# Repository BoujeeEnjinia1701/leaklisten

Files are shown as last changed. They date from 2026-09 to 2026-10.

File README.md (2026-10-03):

# LeakListen

     

**Area:** Smart Cities · **TRL:** 3 of 9 (proof of concept on paper) · **Value-engineering target:** about $130 USD · **Difficulty:** 3 of 5

An acoustic leak sensor that clamps onto water mains and valves and listens overnight for the noise signature of leaks.

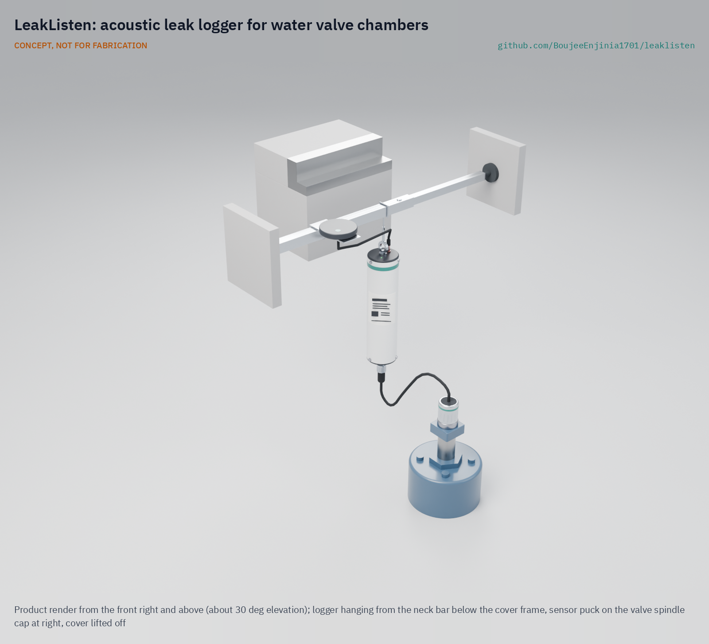
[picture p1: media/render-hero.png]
LeakListen: acoustic leak logger for water valve chambers, product render


[Exploded render](media/render-exploded.png) · [Detail render](media/render-detail.png) · [Interactive 3D model](media/viewer.html) · [Concept blueprint (PDF)](media/concept-blueprint.pdf) · [General arrangement LKL-DWG-001 (PDF)](cad/drawings/LKL-DWG-001.pdf) · [Sizing calculations](docs/04-calcs/01-sizing.md) · [Prototype build plan](docs/05-build-plan.md) · [Design decisions](docs/06-design-decisions.md) · [Review note](docs/REVIEW.md)

## Concept rationale

Leaks on pressurized mains make a steady hiss that travels along the pipe wall, and it is easiest to hear at night, when demand and traffic are low. A logger that listens to every valve in a district for a few minutes each night, and flags the ones whose quietest level has risen, turns a slow street-by-street survey into a short list of places to check. LeakListen does this with a magnet-on piezo sensor, a logger that hangs under the chamber cover, one primary cell for years of life and a single small LoRaWAN message a night.

It is open and garage-buildable because the utilities with the highest losses are often the least able to buy and maintain a fleet of closed commercial loggers. The parts are a turned aluminium puck, a piezo disc, a PVC tube, a standard LoRaWAN module and a lithium cell, for about $142 per logger, and the data format is documented so any network server, including the lab's TwinKit gateway, can read it.

## Burning platform

Water utilities lose an estimated 126 billion m³ of treated water a year to leaks and unbilled use, worth nearly $40 billion ([World Bank](https://blogs.worldbank.org/en/ppps/what-do-private-companies-look-performance-based-non-revenue-water-project)). In developing countries alone, about 45 million m³ a day leak from distribution networks, "enough to serve nearly 200 million people" ([Kingdom, Liemberger and Marin, World Bank, 2006](https://documents1.worldbank.org/curated/en/385761468330326484/pdf/394050Reducing1e0water0WSS81PUBLIC1.pdf)).

High-income networks are not immune. The United States still has about 240,000 water main breaks a year, costing about $2.6 billion in repairs ([ASCE 2025 Report Card](https://infrastructurereportcard.org/cat-item/drinking-water-infrastructure/)). Many leaks, though, never break the surface and run until someone listens for them.

## Where it could be used

### By industry

| Industry | Use |
| --- | --- |
| Municipal water utilities | Nightly screening of a district metered area, so leak crews go to flagged streets first |
| Small towns and community water schemes | A handful of loggers on the key valves of a small network without a specialist contract |
| Campuses, airports and industrial parks | Leaks on private mains after the utility meter, which the utility does not survey |
| Irrigation districts | Leaks on buried pressurized irrigation pipelines |
| Fire protection networks | Hidden leaks on private fire mains that stay pressurized but rarely flow |
| Research and education | An open logger and dataset for leak noise research and teaching |

### By country or region

| Country or region | Why it matters there |
| --- | --- |
| United States | About 240,000 water main breaks a year ([ASCE 2025](https://infrastructurereportcard.org/cat-item/drinking-water-infrastructure/)); many small utilities cannot fund commercial logger fleets. |
| England and Wales | Companies leaked an average of 2,967 million litres a day from April 2022 to March 2025, and all have leakage reduction targets ([Discover Water](https://www.discoverwater.co.uk/leaking-pipes)). |
| Southeast Asia | A study of 47 utilities in Indonesia, Malaysia, Thailand, the Philippines and Vietnam found non-revenue water averaging 30 %, ranging from 4 to 65 % ([Kingdom et al., 2006](https://documents1.worldbank.org/curated/en/385761468330326484/pdf/394050Reducing1e0water0WSS81PUBLIC1.pdf)). |
| Developing countries generally | About 45 million m³ a day lost to leakage ([Kingdom et al., 2006](https://documents1.worldbank.org/curated/en/385761468330326484/pdf/394050Reducing1e0water0WSS81PUBLIC1.pdf)); a low-cost open logger suits utilities starting a leak program. |
| South Africa | About 22 million people, 39 % of the population, were affected by intermittent water supply in 2017, and 65 of 231 municipalities supplied water intermittently ([Loubser, Chimbanga and Jacobs, 2021, *Water SA*](https://scielo.org.za/scielo.php?pid=S1816-79502021000100001&script=sci_arttext)). LeakListen only hears leaks on pressurized pipes, so it fits zones with continuous supply, and a pilot there would test that limit. |

## What sparked the idea

The starting point was the way Tokyo finds hidden leaks. Inspectors of the Tokyo Metropolitan Government Bureau of Waterworks press the tip of a listening rod against a water meter, gate valve or fire hydrant and listen for leak noise through a diaphragm, alongside night-time minimum flow measurements, electronic detectors, correlators and noise loggers; with this sustained effort the city's leakage rate fell from 10.2 % in fiscal 1992 to 3.5 % in fiscal 2024 ([Bureau of Waterworks, *Prevention of Leakage in Tokyo 2025*](https://www.english.metro.tokyo.lg.jp/documents/d/english/knowledge_and_tech_r07rousui)). Few utilities can staff that many trained listeners. LeakListen asks whether a cheap, open logger left on the same gate valves could do the first round of that listening every night, so the scarce experts go only where a valve has started to hiss.

## Problem

A large share of treated city water is lost to leaks before it reaches customers, and leaks are found by slow manual surveys. Full problem statement: [docs/01-problem.md](docs/01-problem.md).

## Concept

A magnetic piezo sensor clips onto a valve spindle cap and a sealed logger hangs under the chamber cover, placed from the surface with no chamber entry. Each night between 02:00 and 04:00 the logger records twelve 20 s windows, computes levels and a 64-band spectrum from 5 Hz to 2 kHz, deletes the raw samples and sends a 24-byte summary over LoRaWAN. A server (or the lab's TwinKit gateway) flags a logger whose night-time minimum level rises and stays up, and a crew then pinpoints the leak with standard tools.

Estimated performance at TRL 3 ([LKL-CAL-001](docs/04-calcs/01-sizing.md)): about 1.2 mAh a day and 10 years or more on one C-size lithium cell; 0.96 kg for the logger, cable and sensor against R12's 1.0 kg (met on paper), plus a 0.32 kg neck bar that stays in the chamber; about $142 in parts against a $130 value-engineering target. The reference leak (5 L/min at 3 bar) is heard about 185 m along an iron main, with a wide uncertainty. The magnet-on sensor is for metallic mains; plastic networks are served by a hydrophone variant on hydrants, not yet sized (R2). Under a cast-iron cover the radio reaches about 0.5 km, so a gateway is planned within 0.5 km of each such district (R7, at risk until cover loss is measured). Also at risk: detection on iron (R1), sensor bandwidth (R3) and noise (R4). A 42 mm magnet now holds 125 N on a coated cap (R9 met on paper). Install time and the false alarm rate need field work.

Full design precis: [docs/02-concept.md](docs/02-concept.md) · Requirements: [docs/03-requirements.md](docs/03-requirements.md) · Decisions: [DDR-001](docs/decisions/0001-trl2-review-decisions.md), [DDR-002](docs/decisions/0002-recommendations-accepted.md) · Model: [cad/src/model.py](cad/src/model.py)

## Key components

- Aluminium sensor puck with a 42 mm pot magnet (with keeper plate), a piezo disc under a 53 g brass mass and a charge preamplifier
- 2 m shielded sensor cable with an M12 IP68 plug
- IP68 PVC logger tube with turned, O-ring sealed end plugs, an eye bolt and antenna connector on top, and a printed frame inside carrying an STM32WL LoRaWAN board (FieldNode core) and a 24-bit ADC
- Lithium thionyl chloride C cell, primary, about 7.7 Ah
- Telescopic aluminium neck bar wedged across the chamber neck below the cover frame on two rubber feet; the logger hangs from it on a lanyard, and a flat LoRa antenna sits on it just under the cover

The working bill of materials is in [bom/bom.csv](bom/bom.csv).

## Building the prototype

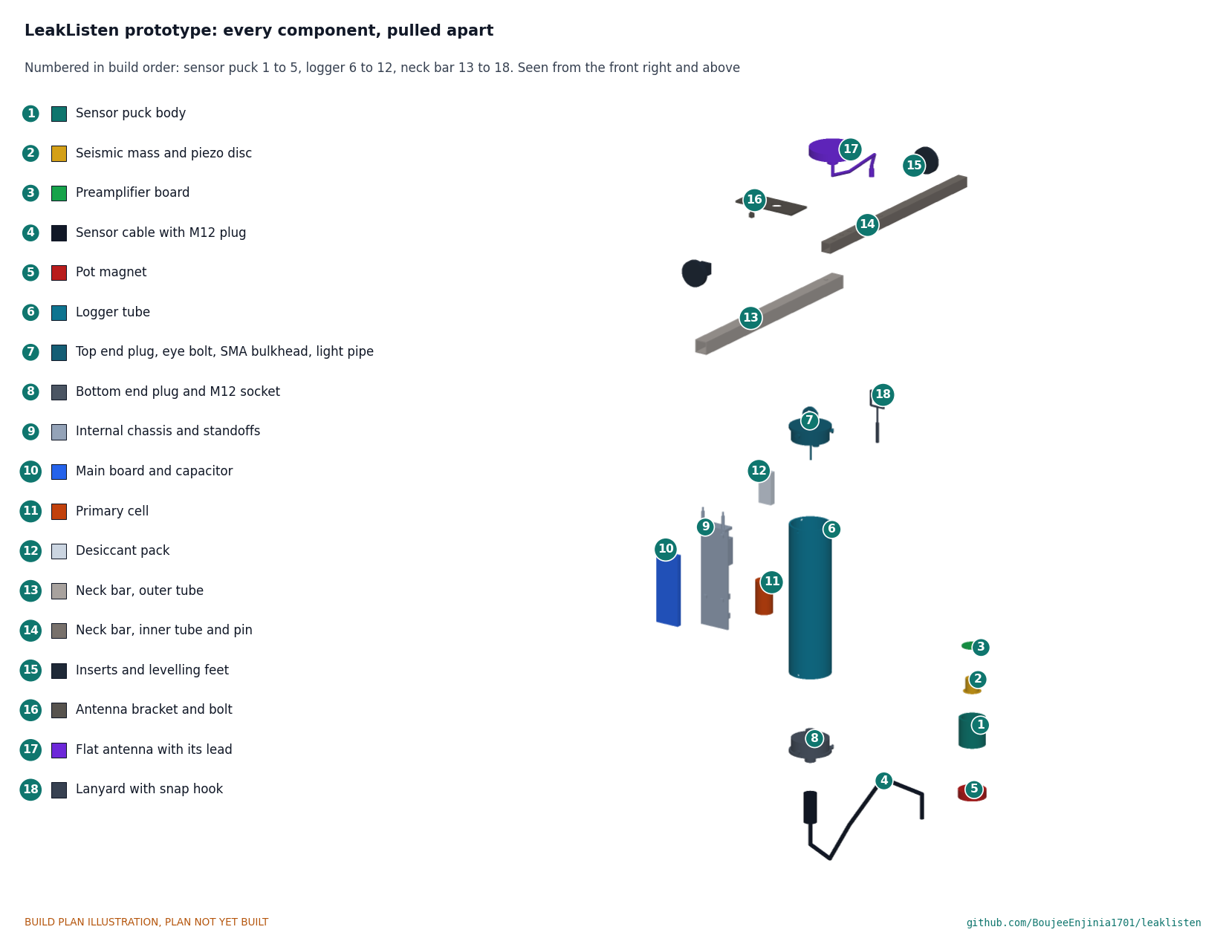
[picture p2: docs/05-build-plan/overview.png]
LeakListen prototype: every component pulled apart and numbered in build order


The [prototype build plan](docs/05-build-plan.md) (LKL-BLD-001) shows, in pictures, how to make each of the eighteen components and put them together in fifteen steps; nothing has been built yet. The made parts are a turned aluminium puck and brass weight, a cut PVC tube with two turned plastic end plugs, a printed frame for the electronics, and a telescopic aluminium neck bar with an antenna bracket. Writing the plan made the design buildable: the strap that was to hook over the cover frame became a neck bar wedged across the chamber neck below the frame, and the end plugs, the top plug fittings, the frame inside the logger and the puck base were redesigned so every part has a fixing (LKL-DDR-003, accepted by Amish on 2026-10-02). Every picture is drawn from the model, and the model checks that each part touches what it should and clears what it should not.

## Safety

> Valve chambers can be confined spaces with low oxygen or toxic gas; LeakListen is placed from the surface, and nobody should enter a chamber without a confined space permit, gas testing and a trained standby person. Covers are heavy and street work needs traffic management.
>
> The logger uses a lithium thionyl chloride primary cell: never charge it, short it, crush it or heat it, and follow the dangerous goods rules for lithium metal cells. The pot magnet can pinch fingers and affect pacemakers.
>
> Place loggers on a public water network only with the utility's written permission.

## Repository layout

| Folder | Contents |
| --- | --- |
| `docs/` | Problem, concept, requirements, calculations and design decisions |
| `cad/src/` | build123d Python source, the source of truth for all geometry |
| `cad/step/`, `cad/stl/` | Exported models for FreeCAD, other CAD tools and printing |
| `cad/drawings/` | 2D sketches and dimensioned drawings |
| `bom/` | Bill of materials |
| `electronics/` | KiCad schematics and PCB layouts |
| `firmware/` | Microcontroller code |
| `media/` | Renders, perspectives and photos |
| `build-log/` | Dated prototyping notes |

## Documentation

Controlled documents follow the portfolio [documentation standard](.kit/STANDARDS.md). Each carries a document ID (LKL-PRC-001 for the precis), a version and a revision history. Branded PDFs are built with `python .kit/render.py` and attached to GitHub Releases when a document is tagged, for example `LKL-PRC-001/v1.0`.

## Credits

Designed by Amish Chadha. See [CONTRIBUTORS.md](CONTRIBUTORS.md) for roles. To cite this design, use [CITATION.cff](CITATION.cff) (GitHub shows it as "Cite this repository").

AI assistance (Claude) was used to accelerate concept renders, prototype documentation and first-pass sizing calculations. Design direction and all decisions are Amish Chadha's, recorded in this repository's decision records (`docs/decisions/`).

## Licenses

- **Hardware** (CAD, drawings, BOM, electronics): [CERN-OHL-S v2](LICENSE)
- **Software** (firmware, scripts, notebooks): [MIT](LICENSE-SOFTWARE)

A project of the [Design Molecule](https://designmolecule.com) lab.

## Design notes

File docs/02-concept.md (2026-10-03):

---
doc_id: LKL-PRC-001
title: LeakListen design precis
project: LeakListen
doc_type: Design precis
version: "0.7"
status: Draft
date: '2026-10-02'
author: Amish Chadha
license: CERN-OHL-S-2.0
revisions:
- version: "0.1"
  date: '2026-09-25'
  author: Amish Chadha
  change: Initial scaffold
- version: "0.2"
  date: '2026-09-25'
  author: Amish Chadha
  change: TRL 2 concept, components, first-order numbers, safety and open questions
- version: "0.3"
  date: '2026-09-25'
  author: Amish Chadha
  change: TRL 3 design choices adopted for TRL 3 (LKL-DDR-001); numbers replaced by LKL-CAL-001; 53 g seismic mass, 24-byte summary, regional transmit power, weekly time correction; links to the model and LKL-DWG-001
- version: "0.4"
  date: '2026-09-25'
  author: Amish Chadha
  change: "Recommendations accepted by Amish (DDR-002): 42 mm pot magnet with keeper plate; contact sensor scoped to metallic mains, hydrophone variant for plastic; district gateway within 0.5 km under iron covers; numbers from LKL-CAL-001 v0.2; LKL-DWG-001 Rev P2"
- version: "0.5"
  date: '2026-10-01'
  author: Amish Chadha
  change: "Constructable design (LKL-DDR-003): neck bar hanger in place of the strap, flanged end plugs, eye bolt and SMA bulkhead, internal chassis, 8 mm puck base; numbers from LKL-CAL-001 v0.3; LKL-DWG-001 Rev P4; cost against the value-engineering target"
- version: "0.6"
  date: '2026-10-02'
  author: Amish Chadha
  change: "Decisions of 2026-10-02: R12 restated (met on paper), calibration check in CalRig, first candidate partner region"
- version: "0.7"
  date: '2026-10-02'
  author: Amish Chadha
  change: 'Daily charge, battery life and cost updated for the status light pipe; general arrangement Rev P5; no requirement status changed'
---

# LeakListen design precis

## Summary

LeakListen is a battery-powered acoustic leak logger that hangs under a valve chamber cover, sticks a magnetic vibration sensor onto the valve spindle cap, listens to the pipe for a few minutes each night, and sends one small LoRaWAN summary a day. A leak on a pressurized main makes a steady hiss that travels along the pipe wall; when a logger's quietest night-time level rises and stays up for several nights, the server flags that street for a follow-up survey. The TRL 3 calculations (LKL-CAL-001 v0.3) give about 1.2 mAh a day, 10 years or more on one C-size lithium cell, 1.35 kg with the neck bar hanger and about $142 in parts for the constructable design (LKL-DDR-003). They also show the two weak points, now answered by decisions Amish accepted on 2026-09-25 (LKL-DDR-002). The reference leak is heard about 185 m along an iron main but only a few metres along a plastic one, so the magnet-on sensor is scoped to metallic mains and plastic networks are left to a hydrophone variant (R2, not yet sized). The radio reaches about 0.5 km, not 1 km, from under a cast-iron cover, so a gateway is planned within 0.5 km of each such district (R7, at risk until the cover loss is measured).

Figure 1. Concept in a valve chamber, street and chamber shown in section ([media/hero.png](../media/hero.png)). Figure 2. Exploded view with BOM numbers ([media/exploded.png](../media/exploded.png)). Figure 3. Cutaway of the logger and sensor ([media/cutaway.png](../media/cutaway.png)). Figure 4. Nightly data flow ([media/flow.png](../media/flow.png)). Figure 5. General arrangement, drawing LKL-DWG-001 Rev P4 ([cad/drawings/LKL-DWG-001.pdf](../cad/drawings/LKL-DWG-001.pdf)), from the parametric model [cad/src/model.py](../cad/src/model.py).

## How it works

1. **Place from the surface.** A technician lifts the cover, lowers the sensor puck on its cable with a pole until the magnet snaps onto the valve spindle cap, and sets the neck bar, with the logger and antenna already fitted, across the chamber neck just below the cover frame, winding out one rubber foot by hand; the logger hangs from the bar on a lanyard and the flat antenna sits on the bar 20 mm under the cover. Nobody enters the chamber. (The concept hooked a strap over the frame; that is not buildable without lifting the cover off its seat, LKL-DDR-003.)
2. **Listen at night.** A real-time clock wakes the logger between 02:00 and 04:00, when demand and traffic noise are lowest. It records 12 windows of 20 s at 8 kS/s from the piezo sensor through a charge preamplifier and a 24-bit ADC. Once a week it asks the network for the time (LoRaWAN 1.0.3 DeviceTimeReq) so the clock stays within 20 s.
3. **Process on the device.** For each window the microcontroller computes the RMS level and a 64-band spectrum from 5 Hz to 2 kHz, in fixed point, with three FFT stages at 8,000, 1,000 and 250 S/s so that even the 0.49 Hz wide bottom band is resolved. It keeps the minimum and the 10th percentile level across the night (leaks are steady; traffic and water use are not) and a band spectrum. Raw samples are then deleted.
4. **Send one summary.** 24 bytes (two night levels, 16 band levels, peak band, steadiness, battery voltage, temperature, flags) go by LoRaWAN to any network server, such as the lab's TwinKit gateway, at +14 dBm in EU868 or up to +20 dBm in US915. The frame fits every EU868 rate and US915 at SF9 or faster.
5. **Flag on the server.** After a 14-night baseline, a logger whose night-time minimum rises by a set margin and stays up for 3 or more nights, with a steady narrow-band spectrum, is flagged. A crew then pinpoints with a ground microphone or a correlator.

## Main components

Numbers match the exploded view and [bom/bom.csv](../bom/bom.csv).

Table 1. Main components.

| No. | Component | Key figures | Role |
| --- | --- | --- | --- |
| 1 | Sensor puck body | Aluminium, 40 mm diameter x 42 mm, potted | Stiff, sealed carrier for the sensor and preamplifier |
| 2 | Pot magnet | 42 mm, about 600 N nominal pull on thick flat steel; keeper plate for transport (LKL-DDR-002; was 32 mm, 290 N) | Attaches to the spindle cap with no tools; 125 N on a 0.5 mm coating (R9) |
| 3 | Piezo disc and seismic mass | 27 mm brass-backed piezo disc in compression under a 20 x 20 mm brass mass, about 53 g; about 157 pC/g | Turns pipe vibration into charge |
| 4 | Charge preamplifier | Low-noise JFET-input stage, 1 nF and 53 MΩ feedback (3 Hz high-pass), then 40 dB; about 1.0 µg/√Hz | Low-noise, low-frequency front end (R3, R4) |
| 5 | Sensor cable | 2 m shielded PUR, M12 IP68 plug | Lets the puck sit on the valve while the logger stays near the cover |
| 6 | Logger housing | 63 mm PVC tube, 240 mm flange to flange, two flanged acetal end plugs with two O-rings each and three radial screws, M12 panel socket | IP68 enclosure (R11) |
| 7 | Main board | STM32WL LoRaWAN module (FieldNode core), 24-bit audio ADC, RTC, hybrid layer capacitor of 0.1 F or more | Scheduling, spectrum, radio |
| 8 | Primary cell | Li-SOCl2, C size, 3.6 V, about 7.7 Ah | Years of life without charging (R6) |
| 9 | Neck bar hanger | Telescopic 20 and 16 mm square aluminium tube with two rubber levelling feet, wedged across the chamber neck below the frame; wire rope lanyard and snap hook | Surface installation (R10) without disturbing the cover |
| 10 | Flat LoRa antenna | About 70 mm disc on a bracket on the neck bar, 20 mm under the cover; 1 m lead with an SMA plug | Radio as close to the cover as possible (R7) |
| 12 | Internal chassis | Printed PETG spine hung from the top plug, clips for the cell and capacitor, desiccant pocket | Holds the electronics; lifts out with the top plug |
| 13 | Top plug fittings | M6 eye bolt (lanyard) and IP67 SMA bulkhead (antenna); the status light pipe rod, part of line 7, shows a short blink at power-up or magnet swipe | Each sealed on its own washer or O-ring |

## Key design choices

These choices were proposed at TRL 2 and were decided by Amish on 2026-09-25: go with recommendation (LKL-DDR-001, confirmed in LKL-DDR-002). The last three follow from the TRL 3 review, also decided by Amish on 2026-09-25 (LKL-DDR-002).

- **Contact sensor on the valve, not a hydrophone.** A magnet-on sensor needs no pipe tapping and no contact with drinking water. Hydrophones hear further on plastic pipes but need a hydrant or tapping point; this is kept as an option for plastic networks (D3), and LKL-CAL-001 shows it is needed to hear any distance on PVC or PE.
- **Noise-level screening, not correlation.** Correlation needs time-synchronized raw audio from pairs of loggers and much more data over the radio. Nightly level and spectrum screening fits LoRaWAN and a primary cell (D1); correlation is recorded as a later variant.
- **Primary cell, not solar.** A chamber has no sun, and a lithium thionyl chloride cell has very low self-discharge. A hybrid layer capacitor supplies the radio pulses the cell cannot deliver alone. A C-size cell (D5) gives 10 years or more.
- **Reuse the FieldNode radio core.** The STM32WL module, payload conventions and network settings are shared with FieldNode so fixes carry across; FieldNode's solar charger and enclosure are not used (D4). Transmit power and the link budget method follow FieldNode's FND-CAL-001.
- **Compression-mode sensor with a heavy mass.** A 53 g brass mass on the disc in compression gives five times the TRL 2 sensitivity while keeping the sensor's own resonance near 200 kHz, far above the band. A disc used as a bender would be as sensitive but would resonate inside the band.
- **Privacy by design.** Raw samples never leave the logger (R8, a fixed requirement under D6). A contact sensor on a valve is a poor microphone, but the rule keeps the design acceptable for street deployment.
- **Contact sensor for metallic mains, hydrophone variant for plastic.** LKL-CAL-001 shows a contact sensor hears only a few metres along PVC or PE, so the magnet-on sensor's scope is metallic mains (R1), and R2 applies to the hydrophone variant on a hydrant or tapping point, which is not yet sized.
- **District gateway under iron covers.** The flat antenna stays under the cover. Where covers are cast iron, a gateway (TwinKit or a partner's) is planned within about 0.5 km of the district; a through-cover antenna or composite cover is used only where the utility agrees. The cover loss is to be measured before deployment (TRL 4, on hold).
- **42 mm pot magnet.** About 600 N rated, it holds 125 N on a cap with 0.5 mm of paint and rust, against 60 N for the 32 mm magnet, for $4 more. It ships with a keeper plate fitted.

## Key numbers (LKL-CAL-001)

All values come from LKL-CAL-001 and `docs/04-calcs/sizing.py`; they are first-principles estimates on assumed data.

Table 2. Key numbers.

| Quantity | Value | Requirement |
| --- | --- | --- |
| Data sampled and sent per night | 3.84 MB sampled and deleted; 24 bytes sent | R8, R14 |
| Daily charge | 1.18 mAh (EU868 SF7) to 1.25 mAh (EU868 SF12), with the status light blink | R6 |
| Battery life on energy | 10.1 to 12.5 years; taken as 10 years | R6 (5 years) |
| Airtime | 1.97 s per uplink at SF12; 5.9 s a day worst case | R14 |
| Link under an iron cover (20 dB assumed) | About 0.53 km range (EU868 SF12); +0.9 dB at the planned 0.5 km gateway distance, -1.2 dB for US915 SF9 | R7 at risk |
| Detection distance, reference leak | About 185 m on ductile iron (93 to 370 m); about 4 m on PVC with the contact sensor, out of its scope | R1 at risk; R2 open (hydrophone variant) |
| Sensor self-noise | 1.03 µg/√Hz worst from 100 Hz to 1 kHz | R4 at risk |
| Mounted resonance | About 676 to 1,350 Hz with the 42 mm magnet and 8 mm puck base | R3 at risk |
| Magnet hold on iron, 42 mm magnet | 309 N bare, 187 N at 0.3 mm, 125 N at a 0.5 mm coating | R9 met on paper |
| Clock | 20 s worst with a weekly time correction | R5 |
| Size and mass | 63 mm tube (68 mm over the screw heads), 283 mm overall; 1.35 kg with the neck bar, 0.96 kg for the logger, cable and sensor | R12 met on paper: 0.96 kg against 1.0 kg for the logger, cable and sensor (restated 2026-10-02, LKL-DDR-003 A1); the bar is site hardware |
| Parts cost | About $142 against a value-engineering target of $130 | R15: USD 12 over the target |

**Energy.** Listening, 12 mA for about 252 s a night, is 59 % of the worst day; sleep at 4 µA and the cell's own self-discharge make up most of the rest. The radio adds only 0.005 to 0.08 mAh a day at +14 dBm.

**Radio.** The flat antenna under the cover is the weak link. To close 1 km, the cover may cost no more than about 10 dB. Decided by Amish, 2026-09-25 (LKL-DDR-002): measure the cover loss first, then plan a gateway within about 0.5 km of each district with iron covers, with a through-cover antenna or composite cover where a utility agrees. At 0.5 km the EU868 link has +0.9 dB to spare at a 20 dB cover loss, and the US915 SF9 link misses by 1.2 dB.

**Cost.** Value-engineering target: USD 130. Estimated cost of the constructable design: USD 142 (USD 12 over the target), see [bom/bom.csv](../bom/bom.csv). The neck bar, the turned end plugs, the chassis and the top plug fittings added USD 28 to the concept's USD 113.

## Safety

> **Safety:** Valve chambers can be confined spaces with low oxygen or toxic gas. LeakListen is designed to be placed from the surface; nobody should enter a chamber without the utility's confined space permit, gas testing and a trained standby person. Covers can weigh 30 kg or more: use a lifting key, lift with the legs and keep feet clear. Street work needs traffic management and high-visibility clothing under local rules.
>
> The lithium thionyl chloride primary cell can vent, burn or explode if shorted, crushed, heated above its rating or charged. Fit a fuse or PTC and reverse protection, never fit a charging circuit, and store and ship cells under the dangerous goods rules for lithium metal cells.
>
> The 42 mm pot magnet pulls about twice as hard as the 32 mm one it replaces, and can pinch fingers badly and affect pacemakers and implanted devices. Carry it with its keeper plate fitted and remove the plate only at the cap.
>
> Placing anything on a public water network needs the utility's written permission. Nothing in LeakListen touches drinking water.

## Open questions

- [ ] Detection distance on iron pipes (R1): estimated in LKL-CAL-001, but the leak source strength and pipe losses need field recordings of known leaks.
- [ ] Sizing the hydrophone variant for plastic networks (R2).
- [ ] Radio loss through cast-iron, ductile iron and composite covers (R7): assumed 10 to 30 dB in LKL-CAL-001, not measured. The response is decided (district gateway within 0.5 km by default, LKL-DDR-002); the measurement is TRL 4 work and on hold.
- [ ] Sensor self-noise (R4): 1.03 µg/√Hz on assumed data; the ceramic's d33 and the op-amp noise need checking against chosen parts.
- [ ] Threshold rules for the leak flag, and how to handle pumps, pressure reducing valves and night-time customer use (R13).
- [ ] Adapter for brass, bronze and plastic fittings (the 42 mm magnet for coated caps is decided, LKL-DDR-002).
- [ ] Whether time synchronization for correlation between neighboring loggers is worth adding later.
- [x] Logger calibration check: a small shaker bay in CalRig, which today covers temperature, humidity and particles only; LeakListen defines the acceptance test (frequency range, level and pass band) in its own repo (decided by Amish, 2026-10-02).
- [x] First partner: a water utility with metallic mains, district metered areas and a leakage target it reports against; the first candidate region to approach is the UK, which would set the radio band to EU868 (decided by Amish, 2026-10-02; nothing agreed). The pilot utility is asked for its range of chamber neck sizes before any deployment.

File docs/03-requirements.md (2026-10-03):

---
doc_id: LKL-REQ-001
title: LeakListen requirements
project: LeakListen
doc_type: Requirements
version: "0.7"
status: Draft
date: '2026-10-02'
author: Amish Chadha
license: CERN-OHL-S-2.0
revisions:
- version: "0.1"
  date: '2026-09-25'
  author: Amish Chadha
  change: Initial scaffold
- version: "0.2"
  date: '2026-09-25'
  author: Amish Chadha
  change: First measurable requirements for TRL 2, with status against the concept
- version: "0.3"
  date: '2026-09-25'
  author: Amish Chadha
  change: "TRL 3, status from LKL-CAL-001 for every requirement; R8 fixed (LKL-DDR-001 D6); R5 and R14 note the weekly time correction and the 24-byte summary"
- version: "0.4"
  date: '2026-09-25'
  author: Amish Chadha
  change: "Recommendations accepted by Amish (DDR-002): R1 and R2 restated (contact sensor for metallic mains, hydrophone variant for plastic); R7 restated against a district gateway within 0.5 km under iron covers; R9 met with the 42 mm magnet; status from LKL-CAL-001 v0.2"
- version: "0.5"
  date: '2026-10-01'
  author: Amish Chadha
  change: "Constructable design (LKL-DDR-003): status from LKL-CAL-001 v0.3; R12 not met on mass with the neck bar; R15 reported against the value-engineering target; R3 and R10 figures updated"
- version: "0.6"
  date: '2026-10-02'
  author: Amish Chadha
  change: "R12 restated by Amish on 2026-10-02 (LKL-DDR-003 A1): 1.0 kg for the logger, cable and sensor, neck bar counted as site hardware; met on paper"
- version: "0.7"
  date: '2026-10-02'
  author: Amish Chadha
  change: 'R6 figure and R15 cost updated for the status light pipe (LKL-DDR-003 follow-up); no status changed'
---

# LeakListen requirements

These are first-pass requirements for one logger. Targets are proposals for review; they come from desk research, not yet from a partner utility, and must be revised after co-design (see the problem statement, LKL-PRB-001). Status is judged against the design in LKL-PRC-001 v0.5 by the calculations in LKL-CAL-001 v0.2, which print every figure quoted here. The TRL 2 review decisions are recorded in LKL-DDR-001. The TRL 3 review decisions, accepted by Amish on 2026-09-25, are recorded in LKL-DDR-002: they restate R2 (plastic mains are served by the hydrophone variant) and R7 (a gateway within 0.5 km of each district with iron covers); no numeric target is lowered.

Table 1. Requirements and status at TRL 3 (LKL-CAL-001).

| ID | Requirement | Target | Verification | Status at TRL 3 |
| --- | --- | --- | --- | --- |
| R1 | Hear a leak on metallic mains (contact sensor) | Flag a 5 L/min (1.3 US gal/min) leak at 3 bar within 100 m of the logger on cast or ductile iron DN100 to DN200. The magnet-on contact sensor's scope is metallic mains (LKL-DDR-002) | Attenuation and detection estimate (LKL-CAL-001 section G); later a partner site with a controlled leak | **At risk:** about 185 m on ductile iron at the central estimate, 93 to 370 m over plausible pipe losses |
| R2 | Hear a leak on plastic mains (hydrophone variant) | Same leak within 30 m on PVC or PE DN100 to DN200, with the hydrophone variant on a hydrant or tapping point (LKL-DDR-002, D3) | As R1, for the hydrophone variant | Open: the hydrophone variant is not sized at TRL 3. For the record, the contact sensor, now out of scope for plastic, hears about 4 m on PVC and 2 m on PE |
| R3 | Sensor bandwidth | 5 Hz to 2 kHz, within ±3 dB after correction | Resonance estimate (LKL-CAL-001 section F); later a shaker comparison | **At risk:** with the 42 mm magnet and the 8 mm puck base the mount resonates at about 676 to 1,350 Hz, flat only to 370 to 730 Hz |
| R4 | Sensor self-noise | Equivalent input noise 1 µg/√Hz or less from 100 Hz to 1 kHz | Noise calculation (LKL-CAL-001 section F) | **At risk:** 1.03 µg/√Hz worst case with the 53 g seismic mass |
| R5 | Night listening | 12 windows of 20 s between 02:00 and 04:00 local time, clock drift under 1 min per month | Clock drift estimate (LKL-CAL-001 section H) | Met on paper with a weekly network time correction (20 s worst); 87 s a month free running |
| R6 | Battery life | 5 years or more on one primary cell at the R5 schedule and one uplink a night | Power budget (LKL-CAL-001 section C) | Met on paper: 10.1 years or more on energy; taken as 10 years |
| R7 | Radio link | 90 % or more of nightly summaries delivered from a chamber with a cast-iron cover to a gateway planned within 0.5 km of each such district; 1 km where the utility agrees to a composite cover or a through-cover antenna (LKL-DDR-002) | Link budget (LKL-CAL-001 section D); cover loss measurement and field check later (TRL 4, on hold) | **At risk:** +0.9 dB at 0.5 km under a 20 dB iron cover (EU868 SF12), -1.2 dB for US915 SF9, -9.1 dB for a tight 30 dB cover; cover loss unmeasured |
| R8 | Data and privacy | Only band levels and spectra leave the logger; raw vibration samples are deleted on the device after processing. Fixed requirement (LKL-DDR-001 D6) | Design review | Met by design |
| R9 | Attachment | Magnet holds 100 N or more on a steel or iron spindle cap, with no tools or pipe work | Hold estimate (LKL-CAL-001 section I); a pull test later | Met on paper with the 42 mm magnet (LKL-DDR-002): 125 N on a 0.5 mm coating, 187 N on 0.3 mm. Non-ferrous fittings, outside this target, need an adapter |
| R10 | Install from the surface | Placed and recovered in 10 min or less without entering the chamber, for chambers up to 1.5 m deep | Task estimate (LKL-CAL-001 section K); a walk-through with the partner utility | Not verifiable at TRL 3: 11 min estimate with the neck bar assembled beforehand; cable reaches caps 2.18 m down |
| R11 | Survive the chamber | IP68: 1 m submersion for 7 days; operate from -20 to +50 °C | Design review (LKL-CAL-001 section J) | Met by design; the logger floats on its lanyard when flooded |
| R12 | Size and mass | Logger 70 mm diameter or less and 300 mm long or less; logger, cable and sensor 1.0 kg or less. The neck bar is site hardware that stays in the chamber and is not counted (restated by Amish on 2026-10-02, LKL-DDR-003 A1) | Parametric model (LKL-CAL-001 section K); weighing at TRL 4 | Met on paper: 68 x 283 mm overall; logger, cable and sensor 0.96 kg (0.04 kg margin); the neck bar is 0.32 kg |
| R13 | Leak flag quality | 1 false alarm or fewer per 20 loggers per month after a 14-night baseline | Field data from a partner network | Not verifiable at TRL 3 |
| R14 | Open and interoperable | Standard LoRaWAN 1.0.x uplink (1.0.3 for the time request), documented 24-byte payload, works with any network server and TwinKit | Design review (LKL-CAL-001 sections A and B) | Met by design |
| R15 | Cost | Parts cost per logger against a value-engineering target of USD 130 (`budget_usd`, a hypothetical control target) | Priced BOM (LKL-CAL-001 section M) | USD 142, USD 12 over the value-engineering target |

## Requirements at risk or open

Summary (LKL-CAL-001 v0.4, Table 6): none not met, 4 at risk, 1 open (R2, variant not sized), 2 not verifiable at TRL 3, 4 met on paper, 3 met by design, and R15 USD 12 over its value-engineering target. R12 was not met on mass after LKL-DDR-003 until Amish restated it on 2026-10-02 (A1); before LKL-DDR-003 R12 and R15 were met on paper; before LKL-DDR-002 there were 2 not met (R2, R7) and 4 at risk (R1, R3, R4, R9).

- **R12 thin margin on mass.** The concept's strap hanger could not be built (it had nothing to hook over except the seat under the cover), and the neck bar that replaces it (LKL-DDR-003) weighs 0.32 kg. The set is 1.35 kg; the logger, cable and sensor are 0.96 kg. Amish decided on 2026-10-02 (LKL-DDR-003, A1) to restate R12 as 1.0 kg for the logger, cable and sensor and count the bar as site hardware, so R12 is met on paper with a 0.04 kg margin; the logger set is weighed at TRL 4.

- **R7 at risk.** At an assumed 20 dB cover loss the link closes to about 0.53 km in EU868 and 0.46 km in US915. Under LKL-DDR-002 a gateway is planned within 0.5 km of each district with iron covers, which EU868 SF12 reaches with +0.9 dB to spare and US915 SF9 misses by 1.2 dB. The cover loss must be measured first; that is TRL 4 work and on hold.
- **R2 open.** Leak noise attenuates quickly on plastic pipes (0.42 dB/m at 100 Hz on PVC against 0.011 dB/m on ductile iron), and a contact sensor on a valve hears the reference leak only a few metres along PVC or PE. Under LKL-DDR-002 R2 applies to the hydrophone variant (LKL-DDR-001 D3), which is not yet sized.
- **R1 at risk.** The central estimate of 185 m on iron clears 100 m, but pipe loss and leak source strength are both uncertain by large factors.
- **R3 at risk.** The magnet mount's resonance falls inside the band and varies by site; the heavier 42 mm magnet and the 8 mm puck base lower it by about 13 %.
- **R4 at risk.** 1.03 µg/√Hz against 1 µg/√Hz, on assumed ceramic and op-amp data.
- **R9 met on paper** with the 42 mm magnet (LKL-DDR-002); it was at risk with the 32 mm magnet (90 N at a 0.3 mm coating). Brass, bronze or plastic fittings still need an adapter.
- **R10 and R13 not verifiable at TRL 3.** They need a walk-through and field data with a partner utility.

## Assumptions

- Network pressure at night 2 to 6 bar; leaks at lower pressure are quieter.
- Valve spindle caps and hydrant bodies are cast iron or steel on most networks the lab would target first.
- A LoRaWAN gateway (TwinKit, a partner's or a public network) is within about 1 km in an urban area, and within about 0.5 km of each district with cast-iron covers (LKL-DDR-002).
- Transmit power follows the regional limit: +14 dBm in EU868, up to +20 dBm in US915.
- Primary cell: lithium thionyl chloride C size, 3.6 V, about 7.7 Ah nominal, derated to 70 % usable for cold and pulse loads.

## Safety requirements

> **Safety:** S1: no confined space entry is needed to place, service or recover a logger. S2: the cell is a primary lithium cell with a fuse or PTC and reverse protection; no charging circuit is fitted. S3: the logger carries a label with the owner, a contact and a lithium cell warning. S4: nothing touches drinking water, and nothing is fixed to the pipe other than the magnet.

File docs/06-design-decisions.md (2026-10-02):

---
doc_id: LKL-DEC-001
title: LeakListen design decisions register
project: LeakListen
doc_type: Design decisions register
version: "0.2"
status: Draft
date: '2026-10-02'
author: Amish Chadha
license: CERN-OHL-S-2.0
revisions:
  - version: "0.1"
    date: '2026-10-01'
    author: Amish Chadha
    change: Register opened with the open decisions, items to confirm, value engineering and decisions made to date
  - version: "0.2"
    date: '2026-10-02'
    author: Amish Chadha
    change: "Amish approved the recommendations for all six open decisions on 2026-10-02 (LKL-DDR-003 accepted); moved to decisions made"
---

# LeakListen design decisions register

Every design decision still to be made, and every decision made, in one place. Each decision is argued in full in its decision record under `docs/decisions/`; this register is the index Amish works from. The build plan (`docs/05-build-plan.md`) describes the design as it stands and does not list open decisions.

## Open decisions

None. All open decisions were decided on 2026-10-02.

## To confirm when parts are bought

| # | What to confirm | Why it matters | Source |
| --- | --- | --- | --- |
| 1 | The pot magnet's stud is M6 and can be cut to 6 mm | The puck base is tapped M6 for 6 mm of thread | LKL-DDR-003, P7 |
| 2 | The flat antenna's centre stud size, and that its lead ends in an SMA plug | Sets the bracket's stud hole and the top plug's connector | LKL-DDR-003, P2 and P4 |
| 3 | The SMA bulkhead's panel hole and the M12 socket's thread (M16 x 1.5 assumed) | Sets the holes in the two end plugs | LKL-DDR-003, P4 and P6 |
| 4 | The square tube inserts suit 1.5 mm wall tube and take an M10 levelling foot | The feet wedge the bar | LKL-DDR-003, P1 |
| 5 | The main board fits 38 x 110 mm with its components within 8 mm | The chassis and the tube bore are sized to it | LKL-DDR-003, P5 |
| 6 | The capacitor and cell sizes (16 x 30 mm, C size 26.2 x 50 mm) | The chassis clips are printed to them; the cell clears the bore by 0.8 mm | LKL-DDR-003, P5 |

## Value engineering

Value-engineering target: USD 130 (a hypothetical control target, not a limit). Estimated cost of the constructable design: USD 141 (USD 11 over the target). Main cost drivers and savings worth trying:

- The largest lines are the main board (USD 30, a prototype price; its design is TRL 4 work), the neck bar hanger (USD 18), the logger housing with its turned plugs (USD 16), the sensor cable (USD 12) and the primary cell (USD 12).
- Making the design constructable added USD 28 to the concept's USD 113: the neck bar (USD 12 more than the strap), the turned plugs, O-rings and screws (USD 4), the internal chassis (USD 4), the eye bolt and SMA bulkhead (USD 7) and the thicker puck (USD 1).
- Savings worth trying: a fixed-length bar cut to each district's neck width, with one foot and no inner tube or pin (about USD 4 and 80 g); plugs turned in batches or moulded later; a main board price that should fall once its design is done; a cable bought by the reel with a field-fit M12 plug.

## Decisions made

| Date | Decision | Decided by | Record |
| --- | --- | --- | --- |
| 2026-09-25 | D1 to D6: nightly noise-level screening; flat antenna under the cover; piezo disc sensor with the hydrophone kept for plastic networks; reuse of the FieldNode STM32WL core; C-size cell; raw samples never leave the device | Amish: "i accept all your recommendations, go with them across all repos." | LKL-DDR-001, LKL-DDR-002 |
| 2026-09-25 | D7: measure cover loss first, then a gateway within about 0.5 km of each district with iron covers | Amish, same instruction | LKL-DDR-002 |
| 2026-09-25 | D8: the contact sensor's scope is metallic mains; the hydrophone variant answers plastic mains | Amish, same instruction | LKL-DDR-002 |
| 2026-09-25 | D9: 42 mm pot magnet with a keeper plate | Amish, same instruction | LKL-DDR-002 |
| 2026-10-01 | Budget treated as a value-engineering target, reported as over or under rather than met or not met | Amish: "the budgets are a hypothethical control target to ensure we are thinking along a value engineering lens" | This register; LKL-CAL-001 v0.3 |
| 2026-10-02 | Design for construction accepted as a whole: the changes P1 to P9 of LKL-DDR-003 (neck bar hanger, flanged end plugs, top plug fittings, internal chassis, puck changes) and their knock-on changes, as made | Amish: "i approve your recommendations for all 555 open decisions." | LKL-DDR-003, P1 to P9 |
| 2026-10-02 | R12 restated as 1.0 kg for the logger, cable and sensor (0.96 kg estimated); the 0.32 kg neck bar is site hardware that stays in the chamber; the logger set is weighed at TRL 4 because the margin is 0.04 kg | Amish: "i approve your recommendations for all 555 open decisions." | LKL-DDR-003, A1 |
| 2026-10-02 | Neck bar for the prototype; the pilot utility is asked for its range of chamber neck sizes before any deployment, and a longer inner tube is designed only if that range goes past 710 mm; a drilled bracket stays the fallback for poor or out-of-range necks | Amish: "i approve your recommendations for all 555 open decisions." | LKL-DDR-003, A2 |
| 2026-10-02 | First partner: a water utility with metallic mains, district metered areas and a leakage target it reports against. First candidate region to approach: the UK, where water companies run district metered areas and report leakage to the regulator; that would set the radio band to EU868 | Amish: "i approve your recommendations for all 555 open decisions." | LKL-DDR-002, O1 |
| 2026-10-02 | The vibration calibration check goes in CalRig as a small shaker bay; LeakListen defines the acceptance test (frequency range, level and pass band) in its own repo | Amish: "i approve your recommendations for all 555 open decisions." | LKL-DDR-002, O2 |
| 2026-10-02 | Light pipe on the top plug kept, lit only for a brief blink at power-up or magnet swipe and added to BOM line 7; board orientation, cable route and render context accepted as appearance only | Amish: "i approve your recommendations for all 555 open decisions." | `docs/REVIEW.md`, 2026-09-26 |

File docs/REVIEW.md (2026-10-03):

# Review note: LeakListen

## Session 2026-10-02: open decisions decided by Amish

Amish wrote on 2026-10-02: "i approve your recommendations for all 555 open decisions." Every open decision in this repo's register was decided as recommended and moved to "Decisions made" in `docs/06-design-decisions.md`, dated 2026-10-02.

### Decisions recorded

6 decisions recorded (register items 1 to 6). The register's "Open decisions" section now reads: "None. All open decisions were decided on 2026-10-02."

### Documents changed

- `docs/06-design-decisions.md` v0.2
- `docs/decisions/0003-design-for-construction.md` v0.2
- `docs/decisions/0001-trl2-review-decisions.md` v0.3
- `docs/decisions/0002-recommendations-accepted.md` v0.2
- `docs/03-requirements.md` v0.6
- `docs/04-calcs/01-sizing.md` v0.4
- `docs/02-concept.md` v0.6
- `docs/01-problem.md` v0.5
- `docs/05-build-plan.md` v0.2
- `README.md` (R12 figure and DDR-003 status; not a controlled document)

PDFs re-rendered with `python3 .kit/render.py`. The CAD model, BOM quantities and prices, and pictures were not changed.

### Follow-up actions to carry approved decisions into the design

1. Decision 1 (build plan pictures and renders): Update `cad/src/product_model.py` to the constructable design (neck bar, flanged plugs, eye bolt and SMA bulkhead) and regenerate `media/render-*.png`, `media/card.png` and `media/social-preview.png` on Amish's Mac; then drop the concept strap parameters that `cad/src/model.py` keeps only for the appearance model.
2. Decision 2 (calculations): Change the R12 check in `docs/04-calcs/sizing.py` to 1.0 kg for the logger, cable and sensor (neck bar excluded) and rerun, so that LKL-CAL-001 matches the hand-edited v0.4.
3. Decision 5 (documents): Write LeakListen's vibration acceptance test (frequency range, level and pass band) in this repo, and raise the small shaker bay with the CalRig project; CalRig was not edited.
4. Decision 6 (model): Add the light pipe and its hole to the top plug in `cad/src/model.py` and rerun the constructability checks.
5. Decision 6 (drawings): Regenerate the top plug making sketch and LKL-DWG-001 with the light pipe hole.
6. Decision 6 (BOM): Add the light pipe to BOM line 7 (description and price) in `bom/bom.csv` and rerun the cost line [M1].
7. Decision 6 (calculations): Add the power-up and magnet-swipe blink to the daily charge in LKL-CAL-001, section C (expected to be negligible).
8. Decision 6 (build plan pictures and renders): Show the light pipe in the top plug step pictures of LKL-BLD-001 and in the renders.

### Points found in the review

- R10 (install in 10 min or less) is shown as 'not verifiable at TRL 3' although the task estimate is now 11 min; on the register's own figures it should read 'at risk'.
- Item 2's restated limit leaves 0.04 kg of margin on the logger set (0.96 kg against 1.0 kg) on estimated masses.
- The 2026-09-26 note that the hanger plate overlapped the antenna by about 10 mm is resolved by LKL-DDR-003, P2 and can be closed in REVIEW.md.

TRL 4 remains on hold by Amish's instruction.

## Session 2026-10-01: kit 1.7.0, constructable design and prototype build plan

Kit 1.7.0 installed (`.kit/`, `.claude/commands/`, `CLAUDE.md` replaced by `.kit/CLAUDE.md`). Following `/build-plan` and STANDARDS section 18, under Amish's 2026-09-30 instruction to make the design physically buildable and his 2026-10-01 instruction to treat the budget as a value-engineering target.

### What was done

- Constructability review of `cad/src/model.py` with build123d checks; the model is now built component by component and runs 72 checks (`python cad/src/model.py --check`), all passing.
- `docs/decisions/0003-design-for-construction.md` (LKL-DDR-003 v0.1, Draft, open for Amish's review): every change below, its reason and the knock-on effects.
- `docs/05-build-plan.md` (LKL-BLD-001 v0.1) with `cad/src/build_plan_media.py`: overview, 9 making sketches (`cad/drawings/LKL-DWG-101` to `109`), 8 joint pictures, 15 step pictures and a wiring diagram in `docs/05-build-plan/`.
- `docs/06-design-decisions.md` (LKL-DEC-001 v0.1): 6 open decisions, 6 items to confirm when parts are bought, a value engineering section and the decisions made to date.
- `bom/bom.csv`: lines 1, 6 and 9 repriced, lines 12 (internal chassis) and 13 (top plug fittings) added; `bom/bom-notes.md` updated.
- Calculations re-run: LKL-CAL-001 v0.3 and `docs/04-calcs/results.csv`. LKL-REQ-001 v0.5 and LKL-PRC-001 v0.5 updated to match.
- STEP and STL regenerated (`leaklisten-assembly`, `logger`, `sensor-puck`, and new `neck-bar`); LKL-DWG-001 Rev P4 (with `cad/src/sheets.py` brought in line with the kit 1.7 sheet layout); concept media regenerated (`hero`, `exploded`, `cutaway`, `flow`, `concept-blueprint`, `model.glb`).
- `project.yaml`: `design_state: constructable`, LKL-DDR-003, LKL-BLD-001 and LKL-DEC-001 added to `trl_evidence`; `budget_usd` unchanged at 130. README: links line, value-engineering wording, key components and a "Building the prototype" section.

### Design changes made for construction (LKL-DDR-003)

1. Hanger: the stainless strap "hooked over the cover frame" (which could only sit under the cover and rock it) became a telescopic aluminium neck bar wedged across the chamber neck below the frame on two rubber levelling feet; the logger hangs from it on a wire rope lanyard.
2. Antenna: on a 40 x 3 mm bracket bolted across the bar, held by its own stud; 20 mm under the cover (was 8 mm), and no longer overlapping the hanger (the overlap flagged in this note on 2026-09-26 is resolved).
3. End plugs: flanged acetal plugs with two O-rings each, held by three radial M4 screws outboard of the O-rings; tube cut to 232 mm so the logger stays 240 mm flange to flange.
4. Top plug: an M6 eye bolt for the lanyard and an IP67 SMA bulkhead for the antenna, in place of one "antenna and lanyard gland".
5. Inside the logger: a printed chassis hung from the top plug on two standoffs, with the board on standoffs, clips for the cell and capacitor and a desiccant pocket.
6. Bottom plug: a front-mount M12 panel socket in an M16 thread.
7. Puck base thickened from 3 to 8 mm and tapped M6 for the magnet's stud.
8. Puck bore stepped so a round 31 mm preamplifier board sits on the step clear of the seismic mass, with potting above the board only.
9. Logger lowered to 180 mm below the street to hang under the bar; the cable still reaches caps 2.18 m deep.

### Key results

- Mass 1.35 kg with the neck bar (logger, cable and sensor 0.96 kg): **R12 not met** on mass (1.0 kg). Size 68 x 283 mm still meets R12's 70 x 300 mm.
- Value-engineering target: USD 130. Estimated cost of the constructable design: USD 141 (USD 11 over the target).
- R3 slightly worse: mounted resonance 676 to 1,352 Hz (was 695 to 1,389 Hz). Install task estimate 11 min (R10, not verifiable at TRL 3). Logger still floats on its lanyard when flooded (1.9 N).
- Requirement status: 1 not met (R12), 4 at risk (R1, R3, R4, R7), 1 open (R2), 2 not verifiable (R10, R13), 3 met on paper (R5, R6, R9), 3 met by design (R8, R11, R14), R15 USD 11 over its value-engineering target.

### Proposed, awaiting Amish

All in the design decisions register (LKL-DEC-001): accept LKL-DDR-003 as a whole; A1, restate R12's mass limit for the logger, cable and sensor (recommended); A2, neck bar versus a drilled wall bracket for other neck sizes (neck bar recommended for the prototype); O1 and O2 carried from LKL-DDR-002; the 2026-09-26 appearance-model items.

### Safety

No change to the safety case. The neck bar removes a hazard the concept had (a strap under the cover seat would rock the cover under traffic). The build plan carries stop points for the lithium thionyl chloride cell and the magnet, and keeps all work at the bench or the surface.

### Stale, to redo on Amish's Mac

The photoreal renders (`media/render-*.png`, referenced by the README but not present in this copy), `media/card.png`, `media/social-preview.png` and the appearance model `cad/src/product_model.py` still show the concept strap hanger, the fused end plugs and the single top gland. The design changed visibly, so they are stale. `cad/src/model.py` keeps the concept strap parameters only so `product_model.py` still runs.

### Recommended next step

Amish reviews LKL-DDR-003 and the register. TRL 4 (building and testing to the plan) remains on hold.

## Session 2026-09-26: sources strengthened

Amish asked on 2026-09-26 to fix the weaker sources. README change only; no controlled document changed. All other README sources (World Bank, Kingdom et al. 2006, ASCE 2025, Discover Water, Tokyo Bureau of Waterworks) were re-checked and support their claims.

| Where | Old source | New source |
| --- | --- | --- |
| Country row: Sub-Saharan Africa | None | Replaced by South Africa, citing [Loubser, Chimbanga and Jacobs, 2021, *Water SA*](https://scielo.org.za/scielo.php?pid=S1816-79502021000100001&script=sci_arttext) (22 million people, 39 % of the population, on intermittent supply in 2017) |

## Session 2026-09-25: /populate to a strong TRL 2

### What was done

- `docs/01-problem.md` (LKL-PRB-001 v0.2): problem with cited loss figures, users, operating context, constraints, out of scope, prior work (Hunaidi and Chu 1999, Gutermann ZONESCAN, World Bank NRW work), open questions and safety; co-design checklist kept.
- `docs/03-requirements.md` (LKL-REQ-001 v0.2): 15 measurable requirements (R1 to R15) with targets, verification method and status at TRL 2; safety requirements S1 to S4; assumptions.
- `docs/02-concept.md` (LKL-PRC-001 v0.2): how it works, 10 numbered components, design choices, data and energy budgets, battery life, magnet hold, cost, safety and open questions.
- `cad/src/concept_media.py`: massing model of the logger on a gate valve in a DN150 main's valve chamber, with the street, soil and chamber shown in section and a 1.75 m person standing on the street. Existing assets (main, valve, spindle cap) are grey and unnumbered.
- `media/`: `hero.png`, `concept-blueprint.png`, `.pdf` and `.svg`, `exploded.png` (BOM callouts 1 to 10), `cutaway.png` (logger and sensor puck interiors), `flow.png` (nightly data flow, estimates), `model.glb` and `viewer.html`.
- `bom/bom.csv`: 11 lines with indicative USD prices, numbered to match the exploded view; `bom/bom-notes.md` updated.
- `README.md`: hero image and links line; concept rationale, burning platform, where it could be used, what sparked the idea, concept, key components and safety expanded.
- `docs/pdf/`: branded PDFs of the three controlled documents.

Media notes: the kit's cutaway cutter is centered on Z = 0, so `concept_media.py` lifts the model 400 mm for the kit media; the hero is rendered separately in true street coordinates with a plain-language note. The main and valve appear only in the hero so the exploded view and cutaway frame the logger at a readable size.

### Key results (estimates, to be checked at TRL 3)

| Quantity | Estimate | Requirement |
| --- | --- | --- |
| Data sampled per night | 3.84 MB (240 s at 8 kS/s, 16 bit), deleted on device | R8 met by design |
| Data sent per night | about 50 bytes, one LoRaWAN uplink plus retries | R14 |
| Energy per day | about 1.15 mAh, self-discharge included | |
| Battery life, C-size Li-SOCl2 7.7 Ah at 70 % usable | about 12.8 years on energy, taken as about 10 years | R6 met on paper (5 years) |
| Magnet hold on a painted spindle cap | about 95 N (a third of the 290 N rating) | R9 marginal (100 N) |
| Logger size and mass | 63 x 240 mm; about 0.7 kg | R12 met |
| Parts cost | about $108 | R15 met ($130) |

Requirements not met or at risk:

- **R2 (plastic pipes) at risk:** plastic pipes attenuate leak noise strongly, so 30 m detection may not be reachable.
- **R7 (radio from under a cast-iron cover) at risk:** cover loss is unknown and may block the link.
- **R9 (attachment) not met** for brass, bronze or plastic fittings, and marginal on painted iron caps.
- **R1, R4 and R13 unverified:** detection distance on iron pipes, sensor self-noise and false alarm rate need calculation at TRL 3 and field data later.

### Proposed, awaiting Amish

1. **Screening versus correlation (pitch-level).** Option A: nightly noise-level screening only (this concept; fits LoRaWAN and a primary cell). Option B: add time-synchronized raw audio for correlation between neighboring loggers (pinpoints leaks, but needs GNSS or radio time sync, much more data and a larger battery). Recommendation: A for TRL 3, with B recorded as a later variant. **Decided by Amish, 2026-09-25: go with recommendation** (LKL-DDR-001, LKL-DDR-002).
2. **Radio from under covers.** Option A: flat antenna under the cover (this concept). Option B: through-cover antenna in a drilled or composite cover (needs utility consent). Option C: a nearby gateway per district. Recommendation: A, with a link budget at TRL 3 deciding whether B is needed. **Decided by Amish, 2026-09-25: go with recommendation** (LKL-DDR-001, LKL-DDR-002).
3. **Sensor type.** Piezo disc with a charge amplifier (cheap, this concept) versus a MEMS accelerometer (simpler, likely noisier at low levels) versus a hydrophone on hydrants (hears further on plastic, needs a tapping). Recommendation: piezo disc, with the hydrophone kept as an option for plastic networks. **Decided by Amish, 2026-09-25: go with recommendation** (LKL-DDR-001, LKL-DDR-002).
4. **Reuse of the FieldNode radio core** (STM32WL module and payload conventions, without FieldNode's solar power). Recommendation: yes, to share fixes across the lab. **Decided by Amish, 2026-09-25: go with recommendation** (LKL-DDR-001, LKL-DDR-002).
5. **Primary cell size.** C size about 7.7 Ah (this concept, about 10 years) versus D size about 19 Ah (longer margin, larger tube). Recommendation: C size. **Decided by Amish, 2026-09-25: go with recommendation** (LKL-DDR-001, LKL-DDR-002).
6. **Privacy rule.** Raw samples never leave the device (R8). Recommendation: keep as a fixed requirement. **Decided by Amish, 2026-09-25: go with recommendation** (LKL-DDR-001, LKL-DDR-002).
7. **First partner utility and region** for co-design and a pilot district. No recommendation; still Proposed, awaiting Amish.
8. **Whether a vibration calibration check belongs here or in CalRig** (CalRig today covers temperature, humidity and particles only). No recommendation; still Proposed, awaiting Amish.

No change to `project.yaml`: the pitch and problem still match the numbers found, and the budget holds.

### Safety concerns

- Valve chambers are confined spaces; the design avoids entry, but a failed placement may tempt someone to climb in. Instructions must say never enter without a permit, gas test and standby person.
- Heavy covers and street work: manual handling and traffic.
- Lithium thionyl chloride primary cell: fire or explosion if shorted, crushed, heated or charged; dangerous goods rules apply to shipping.
- Strong pot magnet: pinching and implanted medical devices.
- Work on a public water network without utility permission.

### Recommended next step

Review this note and the media, then decide items 1 and 2. If approved, run `/advance-trl3` to estimate leak noise attenuation and detection distance for iron and plastic pipes, the sensor noise budget, the radio link budget through covers, and the magnet hold, and to produce the parametric model and drawing sheet.

## Session 2026-09-25: TRL 3

On 2026-09-25 Amish asked for this batch of repos to be taken through the usual process with the instruction "you know the drill, nothing gets past TRL 3". He has not reviewed this repo's TRL 2 items one by one, so every item that carried a recommendation is adopted as recommended for TRL 3 under Amish's 2026-09-25 instruction, open for his review. This session ran `/advance-trl3` on that basis and stopped at TRL 3.

### What was done

- `docs/decisions/0001-trl2-review-decisions.md` (LKL-DDR-001 v0.1, status proposed): six items adopted as recommended for TRL 3, open for Amish's review (D1 to D6), and two left open (O1, O2).
- `docs/04-calcs/01-sizing.md` (LKL-CAL-001 v0.1) and `docs/04-calcs/sizing.py`: data and processing, airtime, energy and battery life, link budget through the cover, leak noise attenuation, sensor noise and resonances, detection distance, clock, magnet hold, chamber survival, size and mass, installation, false alarms and cost, with a status for every requirement. The script imports the model, reads the BOM and `project.yaml`, prints every number the note quotes and writes `docs/04-calcs/results.csv`.
- `cad/src/model.py`: parametric build123d model of the installed set (sensor puck, magnet, piezo and mass, preamplifier, cable with M12 plug, logger tube with plugs, board and capacitor, cell, desiccant, hanger and lanyard, flat antenna), with the spindle cap and cover frame as grey context. Exports `cad/step/` and `cad/stl/` for `leaklisten-assembly`, `logger` and `sensor-puck`.
- `cad/src/sheets.py` and `cad/drawings/LKL-DWG-001.svg`, `.pdf`, `.png`: general arrangement at Rev P1, 1:5, marked "CONCEPT, NOT FOR FABRICATION" and "PRELIMINARY, NOT FOR FABRICATION". LKL-DWG-001 was free because the concept blueprint is LKL-DWG-010.
- `bom/bom.csv` (11 lines, all priced with a supplier or supplier type, $109.00 against the $130 budget) and `bom/bom-notes.md`.
- `cad/src/concept_media.py` now takes the LeakListen parts from the model; all of `media/` was re-rendered and every image checked; temporary `_views` folders deleted.
- LKL-PRB-001, LKL-PRC-001 and LKL-REQ-001 revised to v0.3; `README.md` (TRL badge and line, links, concept figures) and `project.yaml` (`trl: 3`, `trl_target: 3`, evidence list) updated. PDFs rebuilt in `docs/pdf/`.

Design changes made by the calculations, within the adopted decisions: the seismic mass grows from about 11 g to about 53 g in compression and the puck from 34 to 42 mm tall (R4); the nightly summary shrinks from about 50 to 24 bytes so it fits US915 (R14); transmit power is +14 dBm in EU868, since the TRL 2 figure of +20 dBm is not permitted there; the clock takes a weekly LoRaWAN time correction (R5).

### Requirement status (LKL-CAL-001, Table 6)

2 not met, 4 at risk, 2 not verifiable at TRL 3, 4 met on paper, 3 met by design.

| ID | Status | Key number |
| --- | --- | --- |
| R2 Plastic mains | **Not met** | About 4 m on PVC and 2 m on PE for the reference leak, against 30 m |
| R7 Radio link | **Not met** | -9.7 dB at 1 km under an iron cover at an assumed 20 dB loss (EU868 SF12); range about 0.53 km |
| R1 Metallic mains | At risk | About 185 m on ductile iron; 93 to 370 m over plausible pipe losses |
| R3 Bandwidth | At risk | Magnet mount resonance about 780 to 1,550 Hz, flat only to 420 to 840 Hz |
| R4 Self-noise | At risk | 1.03 µg/√Hz against 1 µg/√Hz |
| R9 Attachment | At risk | 149 N bare, 90 N at a 0.3 mm coating, 60 N at 0.5 mm; non-ferrous fittings still need an adapter |
| R10 Install, R13 False alarms | Not verifiable at TRL 3 | 10 min task estimate; random scatter negligible, site events unknown |
| R5, R6, R12, R15 | Met on paper | 20 s clock error with weekly sync; 10.3 years or more; 63 x 267 mm, 0.93 kg; $109.00 |
| R8, R11, R14 | Met by design | |

Key numbers: 1.15 to 1.22 mAh a day; 1.97 s per uplink at SF12; 157 pC/g sensor; leak noise loss 0.011 dB/m (iron) and 0.42 dB/m (PVC) at 100 Hz.

### Decisions recorded (LKL-DDR-001)

Adopted as recommended for TRL 3 under Amish's 2026-09-25 instruction, open for his review (since **Decided by Amish, 2026-09-25: go with recommendation**, LKL-DDR-002): D1 nightly noise-level screening, correlation as a later variant; D2 flat antenna under the cover, with the link budget deciding whether more is needed (it is, see item 3 below); D3 piezo disc sensor, hydrophone kept as an option for plastic networks; D4 reuse of the FieldNode STM32WL core and payload conventions without its solar power; D5 C-size cell; D6 raw samples never leave the device, R8 fixed. No new budget, pitch or problem wording was recommended, so `budget_usd` stays at $130 and `project.yaml` and `README.md` keep the existing pitch and problem lines.

### Still awaiting Amish

1. **O1, first partner utility and region** for co-design and a pilot district. No preference stated.
2. **O2, vibration calibration check here or in CalRig.** No recommendation was made. CalRig's TRL 3 scope is still temperature, humidity and particles.
3. **New, radio under iron covers (R7).** Options: (a) a through-cover antenna or composite cover, which needs utility consent; (b) plan a gateway within about 0.5 km of each district (TwinKit or partner); (c) relax R7 to 0.5 km under iron covers. Recommendation: measure cover loss first; then (b) as the default because it touches no utility asset, with (a) where a utility agrees. **Decided by Amish, 2026-09-25: go with recommendation** (LKL-DDR-002 D7); the measurement is TRL 4 and on hold.
4. **New, plastic mains (R2).** Options: (a) restate the contact sensor's scope as metallic mains and make the hydrophone variant (D3) the answer for plastic networks; (b) keep R2 for the contact sensor and accept it is not met; (c) relax R2. Recommendation: (a). **Decided by Amish, 2026-09-25: go with recommendation** (LKL-DDR-002 D8); the pitch still holds, since hydrophones also mount on existing fittings.
5. **New, 42 mm pot magnet (R9).** About +$4 ($113.00, under budget); holds 125 N at a 0.5 mm coating. Recommendation: yes, with a keeper plate as for the 32 mm magnet. **Decided by Amish, 2026-09-25: go with recommendation** (LKL-DDR-002 D9).

Suggestions only, not in the repo: request the full 64-band spectrum from a flagged logger by downlink; a pointed hardened contact stud under the magnet to stiffen the mount (R3).

### Cross-repo consistency

- FieldNode (FND REVIEW, TRL 3): STM32WL-class module, +14 dBm SX1262-class radio at 45 mA, 20-byte payload, TwinKit first. LeakListen now uses the same EU868 power, noise figure, SNR limits and antenna and feeder figures; its path model is urban Hata rather than FieldNode's suburban one, because loggers sit at street level in towns. The 24-byte summary is LeakListen's own payload on FieldNode's conventions. No conflict; FieldNode not edited.
- TwinKit (TWK REVIEW, TRL 3): 8-channel LoRaWAN concentrator; gateway sensitivity assumed equal to the node's, as here. Recommendation 3(b) would add gateways at about 0.5 km spacing in districts with iron covers, which is denser than TwinKit's sizing assumes. Noted here; TwinKit not edited.
- CalRig: no vibration scope (O2 stays open). No other repo was edited.

### Safety concerns

- Confined spaces: the design still needs no chamber entry. A failed placement may tempt someone to climb in; instructions must say never enter without a permit, gas test and standby person.
- Heavy covers and street work: manual handling and traffic management, as at TRL 2.
- Lithium thionyl chloride cell: fuse or PTC, reverse protection and no charging circuit; dangerous goods rules for shipping. The hybrid layer capacitor must be fused with the cell.
- Magnets: the proposed 42 mm magnet roughly doubles the pull, and the pinch hazard with it; keeper plate fitted in transport, and the pacemaker warning on the label.
- A flooded chamber lifts the logger against its lanyard (2.8 N); the lanyard must not rely on the antenna lead.
- Utility permission before placing anything on a public network.

### Gaps and notes

- Citations: the TRL 2 note listed no unchecked citations. The new citation in LKL-CAL-001 and LKL-PRB-001 (Gao et al., 2004) was verified with WebFetch on its publisher page. WebSearch was not used (quota exhausted).
- Assumptions only tests can settle: cover loss (10 to 30 dB), leak acoustic efficiency (1e-6 to 1e-4), pipe loss factors, valve coupling (-10 dB), night background, magnet mount stiffness and the gap law for the magnet. No figure was invented to replace them.
- The kit's cutaway cuts at the mean Y of the parts; as at TRL 2, `concept_media.py` lifts the logger parts 400 mm for the kit media and renders the hero separately in street coordinates. The cutaway shows the cell, capacitor and puck interior; the main board sits in the removed half and shows in the exploded view.
- Existing material beyond TRL 3: `build-log/README.md` (scaffold) is present, untouched and not extended. `firmware/` and `electronics/` are empty. No test, build or firmware material exists.

### Recommended next step

TRL 4 is on hold by Amish's instruction; this repo stops at TRL 3. Amish's review is needed on D1 to D6, O1 and O2, and items 3 to 5 above. For the record only, TRL 4 would need: a bench build of the sensor puck and logger; a lab test report (TST, `environment: lab`) covering sensor sensitivity and self-noise against a reference accelerometer on a shaker, magnet pull on coated iron caps, mounted resonance, LoRa loss through iron and composite covers, sleep and listening current, and a submersion check; and build log entries. None of this has been started.

## Session 2026-09-25: recommendations accepted

On 2026-09-25 Amish wrote: "i accept all your recommendations, go with them across all repos." Every item with a recommendation is now "Decided by Amish, 2026-09-25: go with recommendation", recorded in `docs/decisions/0002-recommendations-accepted.md` (LKL-DDR-002 v0.1). Items without a recommendation stay open. The repo stays at TRL 3.

### Decisions applied and what changed

- **D1 to D6** (LKL-DDR-001): screening, flat antenna, piezo sensor, FieldNode core, C cell, privacy rule. Already built into the TRL 3 design; LKL-DDR-001 raised to v0.2 with the new status wording.
- **D7, radio under iron covers (R7).** Measure cover loss first (TRL 4, on hold), then plan a gateway within about 0.5 km of each district with iron covers, with a through-cover antenna or composite cover where a utility agrees. R7 restated from "gateway within 1 km" to "gateway within 0.5 km under iron covers, 1 km where a composite cover or through-cover antenna is agreed". New LKL-CAL-001 line [D5]: margin at 0.5 km under a 20 dB cover +0.9 dB (EU868 SF12) and -1.2 dB (US915 SF9); -9.1 dB under a tight 30 dB cover. R7: not met (-9.7 dB at 1 km) to at risk.
- **D8, plastic mains (R2).** The contact sensor's scope is metallic mains (R1); R2 applies to the hydrophone variant, which is not yet sized. R2: not met (4 m on PVC) to open.
- **D9, 42 mm magnet (R9).** `cad/src/model.py` magnet 32 to 42 mm (rated 290 to 600 N, new parameter `magnet_rated_n`); STEP and STL re-exported; BOM line 2 $5 to $9, total $109.00 to $113.00 (budget $130 unchanged, margin $21.00 to $17.00); hold at a 0.5 mm coating 60 to 125 N, at 0.3 mm 90 to 187 N. R9: at risk to met on paper. Side effects: puck and magnet 210 to 262 g, mounted resonance 776 to 1,553 Hz becomes 695 to 1,389 Hz (flat to 376 to 752 Hz, R3 still at risk and slightly worse); total mass 0.93 to 0.98 kg (R12 met with 20 g to spare).
- Documents: LKL-PRB-001 v0.4, LKL-PRC-001 v0.4, LKL-REQ-001 v0.4, LKL-CAL-001 v0.2 (script re-run, `results.csv` rewritten), LKL-DDR-001 v0.2, new LKL-DDR-002 v0.1; LKL-DWG-001 Rev P1 to P2 (magnet); `media/` re-rendered (magnet label, key figures) and checked; `bom/bom-notes.md` updated; `project.yaml` evidence list adds LKL-DDR-002. No budget, pitch or problem change was recommended, so `budget_usd`, `pitch` and `problem` are unchanged.
- README: "What sparked the idea" rewritten around Tokyo's listening-rod leak surveys on gate valves (leakage 10.2 % in fiscal 1992 to 3.5 % in fiscal 2024, Tokyo Bureau of Waterworks); cost, mass and requirement text updated. All PDFs and drawings regenerated so the footer reads designmolecule.com.

### Requirement status (LKL-CAL-001 v0.2)

None not met (was 2), 4 at risk, 1 open, 2 not verifiable at TRL 3, 5 met on paper, 3 met by design.

| ID | Status | Key number |
| --- | --- | --- |
| R1 Metallic mains | At risk | About 185 m on ductile iron; 93 to 370 m over plausible pipe losses |
| R3 Bandwidth | At risk | Mount resonance 695 to 1,389 Hz, flat only to 376 to 752 Hz |
| R4 Self-noise | At risk | 1.03 µg/√Hz against 1 µg/√Hz |
| R7 Radio link | At risk | +0.9 dB at 0.5 km (EU868 SF12), -1.2 dB (US915 SF9); cover loss unmeasured |
| R2 Plastic mains | Open | Hydrophone variant not sized |
| R10, R13 | Not verifiable at TRL 3 | Field work needed |
| R5, R6, R9, R12, R15 | Met on paper | 20 s clock; 10.3 years; 125 N at 0.5 mm; 0.98 kg; $113.00 |
| R8, R11, R14 | Met by design | |

### Still awaiting Amish

1. **O1, first partner utility and region** for co-design and a pilot district. No recommendation.
2. **O2, vibration calibration check here or in CalRig.** No recommendation.

The two suggestions in the TRL 3 section (full spectrum by downlink; a hardened contact stud) were suggestions, not recommendations, and remain outside the repo.

### Cross-repo actions

- **TwinKit:** D7 plans a gateway within about 0.5 km of each district with cast-iron covers, denser than TwinKit's current sizing assumes. Raise with TwinKit; TwinKit not edited.
- **FieldNode:** no action; D4 (shared STM32WL core and payload conventions) is consistent with FieldNode's TRL 3 figures.
- **CalRig:** depends on O2, which is still open; no action yet.

### Safety

Unchanged, plus: the 42 mm magnet pulls about twice as hard as the 32 mm one, so the pinch hazard rises; it ships with its keeper plate fitted and the pacemaker warning stays on the label.

### TRL 4

TRL 4 remains on hold by Amish's instruction. Decided but on hold: measuring LoRa loss through cast-iron and composite covers (D7) and any field link check. No build, test, purchasing, PCB or firmware work was done.

## Session 2026-09-26: product appearance model and photoreal renders

Amish chose LeakListen for the first batch of product renders on 2026-09-26.

### What was done

- `cad/src/product_model.py` (new): appearance model for photoreal renders only, with `product_parts()`, `TITLE` and three `RENDER_VIEWS` (hero with compact chamber context, exploded, and a detail view without context). It adds:
  - logger tube with filleted end plugs, a parting groove and O-ring line on each plug, a teal name band, the owner and lithium warning label with print, the antenna gland and a ribbed M12 panel socket;
  - main board with its module shield can and components facing the front, the hybrid layer capacitor, the C cell with terminals and label band, and the desiccant pack (fabric);
  - flat antenna radome with filleted edges, a seam line and a teal mark, and its lead;
  - stainless hanger strap with a rounded bend, rivets and a lanyard eye, and the stainless lanyard;
  - sensor cable on a smoothed route with a molded M12 plug and knurled coupling nut;
  - bead-blasted aluminium sensor puck with grip flutes, a lid seam, a teal ring and a cable gland, on the 42 mm pot magnet; piezo disc, ceramic, 53 g brass mass and preamplifier inside;
  - context (not in the BOM): the square spindle cap, spindle and gate valve bonnet top (bonnet top at Z = -570 mm, as `cad/src/concept_media.py`), and a slice of cover frame, roof slab and street. The chamber cover is left off so the antenna shows, and the main is not drawn, to keep the render compact.
- `README.md`: the hero image now points to `media/render-hero.png`, with a link to `media/render-exploded.png`. The render files are produced separately.
- Every main dimension, position and interface comes from `PARAMS`, `derived()` and `site_context()` in `cad/src/model.py`. `model.py`, the BOM, the calculation note and the drawing are unchanged.

### Differences between the appearance model and model.py

1. **Status light pipe on the top plug.** A small green light pipe (shown lit) is not in model.py or the BOM. It would let the technician confirm the logger is awake before closing the cover, at a small energy cost. Proposed, awaiting Amish. Recommendation: keep it as a brief blink on the magnet-swipe or power-up only, and add it to BOM line 7 if accepted; otherwise delete the part from `product_model.py`.
2. **Main board orientation.** The board sits at the back of model.py's 8 mm board envelope with its components facing the front (-Y), so they show in the exploded view. The envelope is unchanged. Proposed, awaiting Amish. Recommendation: accept; no change to model.py is needed.
3. **Sensor cable route.** The direct run in model.py is drawn with softened bends through the same points, and the cable leaves the puck through a gland on the lid. The 2 m cable length and both end interfaces are unchanged. Proposed, awaiting Amish. Recommendation: accept as appearance only.
4. **Context extent.** The cover frame slice is 220 mm deep (model.py's `site_context()` frame is 120 mm), and a roof slab, street slice and valve bonnet top are added for the render. These are existing assets, not LeakListen parts. Proposed, awaiting Amish. Recommendation: accept as render context only.

Noted, not changed: in model.py the hanger plate overlaps the antenna disc by about 10 mm in X, and the lanyard starts inside the antenna. The appearance model keeps these positions. Proposed, awaiting Amish: shorten the plate or move the antenna about 10 mm toward +X in model.py at the next design revision.

### TRL

Appearance only: no tolerances, no fabrication detail, no PCB layout and no TRL 4 work. `trl: 3` is unchanged, and TRL 4 remains on hold.

## Session 2026-09-27: kit 1.5.0 and image quality

- Kit 1.5.0 synced: STANDARDS v1.5 (sections 12 to 15: product renders, storefront images and image quality, public release, authorship and signing), `.kit/cards.py`, `.kit/image_qc.py`, `.kit/release_gate.py`, issue templates, and the `/render-product` and `/release` commands. `CLAUDE.md` now matches `.kit/CLAUDE.md`.
- Every `media/render-*.png` recaptioned from its original render with the new layout: the title, concept label and repository sit in a band above the render and the view note in a band below it, each line wrapped to the image width, so no text overlaps other text or the render or runs off the image. `media/card.png` and `media/social-preview.png` regenerated with the same rules.
- `python .kit/image_qc.py` and `python .kit/release_gate.py` pass. trl stays 3.

## Session 2026-10-02: approved follow-ups carried out

Amish approved on 2026-10-02 that every follow-up action from the open-decision sign-off be carried out. trl stays 3; no build or test work was done. `budget_usd` is unchanged.

### Follow-ups

1. Done (pictures, appearance model): `cad/src/product_model.py` rebuilt on the constructable design: neck bar with feet, pin and bracket, lanyard, flanged plugs with O-rings and radial screws, eye bolt, SMA bulkhead, light pipe, chassis on standoffs, round preamplifier board on its step, and the model.py cable route. The concept strap parameters and the concept board size are dropped from `cad/src/model.py`. The photoreal renders, `media/card.png` and `media/social-preview.png` are made on Amish's Mac next from the exported scenes.
2. Done (calculations): the R12 check in `sizing.py` counts the logger, cable and sensor against 1.0 kg: 0.96 kg (margin 38 g). The 70 g antenna rides on the neck bar and is counted with the bar, as in the 0.96 kg of the register. With the bar and antenna the set is 1.35 kg.
3. Not done: LeakListen's vibration acceptance test (frequency range, level and pass band) is a test plan, which is TRL 4 work under the portfolio cap; raising the shaker bay with CalRig is Amish's to start. See Cross-repo actions.
4. Done (model): a 3 mm light pipe rod through a 3 mm hole in the top plug, 13 mm from the axis toward the board side and 10 mm along the standoff line, ending 1.5 mm above the board's top edge. All 75 constructability checks pass (3 new). STEP and STL regenerated.
5. Done (drawings): top plug making sketch LKL-DWG-104 (Rev P2) and general arrangement LKL-DWG-001 (Rev P5) show the light pipe hole and rod.
6. Done (BOM): line 7 includes the light pipe, USD 30.00 to USD 31.00 (basis in `bom/bom-notes.md`).
7. Done (calculations): the status light blink is in the daily charge (section C, [C4]): 5 mA for 2 s, 10 times a day, adds 0.028 mAh a day (1.9 % of the worst case). Battery life on energy is now 10.1 years or more (was 10.3); R6 stays met on paper.
8. Done (pictures): the light pipe is in step pictures 5, 7, 8 and 10, joint 8, the overview and the wiring figure, and in the appearance model.

### Results

- Cost: Value-engineering target: USD 130. Estimated cost of the constructable design: USD 142.00 (USD 12.00 over the target); it was USD 141.00 before the light pipe.
- Mass: logger, cable and sensor 0.96 kg; whole set 1.35 kg.
- Requirement status changes: none. R12 stays met on paper (restated); R15 stays over the target; R6 stays met on paper.
- Pictures regenerated: LKL-DWG-001 (Rev P5), LKL-DWG-104 (Rev P2), concept media (hero, exploded, cutaway, flow, concept blueprint, model.glb), overview, steps 5, 7, 8 and 10, joint 8, wiring figure.
- Render scenes exported to `/home/claude/renders/leaklisten` for the views hero, exploded and detail, with `leaklisten__jobs.json`.

### Documents changed

- `docs/04-calcs/01-sizing.md` (LKL-CAL-001 v0.5), `docs/03-requirements.md` (LKL-REQ-001 v0.7), `docs/02-concept.md` (LKL-PRC-001 v0.7), `docs/05-build-plan.md` (LKL-BLD-001 v0.3), `bom/bom.csv`, `bom/bom-notes.md`, `README.md`, `docs/04-calcs/sizing.py`, `docs/04-calcs/results.csv`, `cad/src/model.py`, `cad/src/sheets.py`, `cad/src/build_plan_media.py`, `cad/src/product_model.py`.

### Cross-repo actions

- CalRig: add a small shaker bay for the vibration calibration check of LeakListen (decision of 2026-10-02). LeakListen's acceptance test (frequency range, level, pass band) is to be written at TRL 4. CalRig was not edited.

### Recommended next step

Render the three views on Amish's Mac, then run the card script.

## 2026-10-02: photoreal renders redone on the constructable design

Rendered with Blender Cycles on Amish's Mac from the updated appearance model; captioned with `.kit/photo_caption.py`; `media/card.png` and `media/social-preview.png` regenerated with `.kit/cards.py`. Views: hero, exploded, detail. image_qc passes. Appearance deviations are those logged above as proposed, awaiting Amish.

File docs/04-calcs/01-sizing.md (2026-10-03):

---
doc_id: LKL-CAL-001
title: LeakListen sizing calculations
project: LeakListen
doc_type: Calculation
version: "0.5"
status: Draft
date: '2026-10-02'
author: Amish Chadha
license: CERN-OHL-S-2.0
revisions:
- version: "0.1"
  date: '2026-09-25'
  author: Amish Chadha
  change: First issue for TRL 3 (data and processing, airtime, energy and battery life, link budget through the cover, leak noise attenuation, sensor noise and resonances, detection distance, clock, magnet hold, chamber survival, size and mass, installation, false alarms, cost)
- version: "0.2"
  date: '2026-09-25'
  author: Amish Chadha
  change: "Recommendations accepted by Amish (DDR-002): 42 mm magnet fitted; R2 restated for the hydrophone variant; R7 against a gateway within 0.5 km under iron covers; results re-run"
- version: "0.3"
  date: '2026-10-01'
  author: Amish Chadha
  change: "Constructable design (LKL-DDR-003): mass, cost, resonance, flooding, cable reach and install time re-run; R12 not met on mass; cost reported against the value-engineering target"
- version: "0.4"
  date: '2026-10-02'
  author: Amish Chadha
  change: "R12 status from Amish's 2026-10-02 restatement (LKL-DDR-003 A1): met on paper. Figures not rerun; sizing.py still prints the 1.0 kg total-mass target"
- version: "0.5"
  date: '2026-10-02'
  author: Amish Chadha
  change: 'Rerun with the R12 check on logger, cable and sensor (0.96 kg, neck bar and antenna excluded), the status light blink added to the daily charge (section C), the light pipe added to BOM line 7 (cost USD 142, USD 12 over the target); no requirement status changed'
---

# LeakListen sizing calculations

On paper, LeakListen meets seven of its fifteen requirements (four on paper, three by design), has four at risk, misses none (R12, mass, was missed once the constructable design added a neck bar hanger, LKL-DDR-003, until Amish restated it for the logger, cable and sensor on 2026-10-02), is USD 12 over its value-engineering target on cost (R15), leaves two that cannot be checked until there is field data and leaves one (R2) open until the hydrophone variant is sized. Version 0.1 of this note found two misses. R7 (radio link) was not met at 1 km: with a flat antenna under a cast-iron cover, and an assumed 20 dB cover loss, the link closes to about 0.53 km. Under LKL-DDR-002 a gateway is now planned within 0.5 km of each district with iron covers, and R7 is at risk rather than not met, because the margin at 0.5 km is only +0.9 dB and the cover loss is unmeasured. R2 (plastic mains) was not met: a contact sensor on a valve hears the reference leak only a few metres along PVC or PE pipe. R2 now applies to the hydrophone variant, and the contact sensor's scope is metallic mains. The 42 mm magnet fitted under LKL-DDR-002 moves R9 to met on paper. On iron mains the central estimate is about 185 m against the 100 m target, but the range spans about 93 to 370 m for plausible pipe losses, so R1 is at risk rather than met. The calculations changed four things in the TRL 2 concept: the seismic mass grows from about 11 g to about 53 g so that the sensor meets its noise target, the nightly summary shrinks from about 50 to 24 bytes so that it fits every LoRaWAN region, transmit power follows the regional limit (+14 dBm in EU868, not +20 dBm), and the clock is corrected weekly by the network. Every number in this note is printed by `docs/04-calcs/sizing.py`; the tag in brackets, for example [C1], is the line of that script's output that carries it.

> **Safety:** These are first-principles estimates for a paper proof of concept. They do not replace confined space procedures, a lithium cell safety review or the utility's permission. Valve chambers can hold low-oxygen or toxic air; nothing in this note needs anyone to enter one. See LKL-PRC-001, Safety.

## Scope and method

The note checks every requirement in LKL-REQ-001 v0.5 against the design in LKL-PRC-001 v0.5 and the parametric model `cad/src/model.py`. The script imports the model's `PARAMS`, derived dimensions and part solids, so the puck, seismic mass, logger tube, cable run and part volumes used here are the ones in the STEP files and in drawing LKL-DWG-001. It also reads `bom/bom.csv` and `budget_usd` in `project.yaml`, and writes the status table to `docs/04-calcs/results.csv`. Run it from the repo root with `python docs/04-calcs/sizing.py`.

The design case is a DN150 gate valve in a concrete chamber under a cast-iron cover, with the spindle cap 0.48 m below the street, a network pressure of 3 bar (44 psi) at night, and a LoRaWAN gateway 30 m up in an urban area, 0.5 km away in districts with iron covers (LKL-DDR-002) and 1 km away elsewhere.

## Assumptions

*Table 1. Main assumptions.*

| Area | Assumption | Basis |
| --- | --- | --- |
| Electronics | Sleep 4 µA; 12 mA while sampling and processing; 1 s of preamplifier settling per window; two 0.2 s receive windows at 5 mA per uplink | STM32WL-class figures; to confirm from the chosen module's datasheet |
| Radio | +14 dBm at 45 mA (EU868, as FieldNode); +20 dBm at 120 mA (US915); up to 3 transmissions a night | FieldNode FND-CAL-001 for EU868; the TRL 2 figure for US915 |
| Cell | Li-SOCl2 C, 7.7 Ah, 70 % usable, 1 % a year self-discharge; carries up to 30 mA, the capacitor the rest | Typical bobbin cell; check against the chosen cell |
| Link | 6 dB receiver noise figure; LoRa SNR limits -7.5 dB (SF7) to -20 dB (SF12); node antenna -3 dBi near the cover, 0.5 dB lead; gateway 2 dBi, 2 dB feeder; 10 dB fade margin; Okumura-Hata urban model at a 1 m mobile height | As FieldNode, with an urban rather than suburban path |
| Cover loss | 10 dB composite cover; 20 dB cast-iron cover (central); 30 dB tight cover over a flooded chamber | Assumed, no verified source; the largest single uncertainty in R7 |
| Pipe waves | Fluid-dominated axial wave below the ring frequency, wavenumber k = k_f √(1 + 2Ba/(Eh(1 + iη))), model form after Gao et al. (2004); water B 2.2 GPa, 1,480 m/s | [Gao, Brennan, Joseph, Muggleton and Hunaidi, *J. Sound Vib.* 277 (2004) 133 to 148](https://www.sciencedirect.com/science/article/pii/S0022460X03011647) |
| Pipes | Ductile iron 170 GPa, 6 mm wall; cast iron 100 GPa, 10 mm; PVC 3.3 GPa, 7.7 mm; PE100 1.2 GPa, 14.6 mm; loss factor including soil coupling 0.02 (iron), 0.065 (PVC), 0.10 (PE) | Handbook moduli; loss factors assumed |
| Leak source | 5 L/min at 3 bar through a sharp orifice (Cd 0.6); acoustic efficiency 1e-6 to 1e-4 of the jet's mechanical power (central 1e-5), half into each direction, flat spectrum from 5 Hz to 2 kHz | Flat spectrum as in Gao et al. (2004); efficiency assumed |
| Sensing | Sensor acceleration = -10 dB coupling times the hoop acceleration of a ductile iron valve body (80 mm radius, 10 mm wall) | Assumed; the valve, not the pipe, is what the magnet touches |
| Background | Night vibration on the spindle cap 0.5 µg/√Hz above 100 Hz, rising as 1/f below | Assumed; site data will replace it |
| Sensor | Soft PZT, d33 300 pC/N; 20 mm ceramic, 0.23 mm, εr 1,800, tan δ 0.02; JFET op-amp 5 nV/√Hz with a 10 Hz 1/f corner; 1 nF feedback, 3 Hz high-pass | Typical buzzer ceramic and op-amp figures |
| Magnet | Rated pull 600 N (42 mm, fitted) or 290 N (32 mm, v0.1) on thick mild steel; 0.7 on cast or ductile iron; pull falls as 1/(1 + g/0.6 mm)² with a coating gap g | Assumed gap law; to check against a supplier's curve |
| Clock | 32.768 kHz crystal, ±20 ppm at 25 °C, -0.034 ppm/°C² | Typical tuning-fork crystal |

## A. Nightly data, processing and payload (R5, R8, R14)

- **Data.** Twelve 20 s windows at 8 kS/s and 16 bits are 3.84 MB a night; 12 spectra of 64 bands, 1.54 kB, stay in RAM [A1]. Raw samples are processed as they arrive and never stored.
- **Resolution.** The 64 bands spaced evenly on a log scale from 5 Hz to 2 kHz are only 0.49 Hz wide at the bottom. A three-stage multirate scheme resolves every band: a 1,024-point FFT at the full rate for 80 Hz to 2 kHz, the same after decimating by 8 for 10 to 80 Hz, and a 512-point FFT after decimating by 32 for 5 to 10 Hz [A2].
- **Memory.** The signal path needs about 22 kB, and with a 32 kB allowance for the LoRaWAN stack the total is 54 kB of the STM32WLE5's 64 kB. The STM32WL has no floating-point unit, so processing is fixed point (q15) [A3].
- **Payload.** The TRL 2 summary of about 50 bytes does not fit US915's slowest rate (11 bytes at SF10) and takes 2.8 s at SF12. The summary is now 24 bytes: night minimum and 10th percentile levels, 16 band levels in 1 dB steps (the 64 bands merged four to one), the peak band, a steadiness index, battery, temperature, flags and a sequence number [A4]. The full 64-band spectrum stays on the device and can be requested later.

## B. LoRaWAN airtime (R7, R14)

- **Time on air.** With 13 bytes of LoRaWAN overhead the 37-byte frame takes 82 ms at SF7, 267 ms at SF9, 494 ms at SF10 and 1.97 s at SF12 [B1].
- **Regional limits.** 24 bytes fits EU868 at every rate and US915 at SF9 or faster, within its 400 ms dwell limit (267 ms) [B2].
- **Fair use.** Three transmissions at SF12 use 5.9 s a day, 20 % of The Things Network's 30 s fair-use allowance, and each needs 197 s of silence under the 1 % duty cycle [B3]. R14 is met by design.

## C. Energy and battery life (R6)

*Table 2. Daily charge and battery life [C1].*

| Case | Sleep | Listening | Radio | Self-discharge | Status light | Total | Life on energy |
| --- | --- | --- | --- | --- | --- | --- | --- |
| EU868 SF7 +14 dBm | 0.096 | 0.840 | 0.005 | 0.211 | 0.028 | 1.18 mAh | 12.5 years |
| EU868 SF12 +14 dBm | 0.096 | 0.840 | 0.076 | 0.211 | 0.028 | 1.25 mAh | 11.8 years |
| US915 SF9 +20 dBm | 0.096 | 0.840 | 0.028 | 0.211 | 0.028 | 1.20 mAh | 12.3 years |
| TRL 2 case, 50 bytes at SF12, +20 dBm | 0.096 | 0.840 | 0.281 | 0.211 | 0.028 | 1.46 mAh | 10.1 years |

- **R6 is met on paper.** Every case gives 10.1 years or more on 5.39 Ah usable; life is still taken as 10 years, limited by cell and seal ageing. Listening, not radio, dominates: 58 % of the worst day [C2]. The TRL 2 figure of about 1.15 mAh a day stands for the EU868 case before the status light is added.
- **Status light blink.** The status light pipe (LKL-DDR-003, decision of 2026-10-02) is lit only for a brief blink at power-up or when the magnet is swiped. At 5 mA for 2 s a blink costs 0.0028 mAh; 10 blinks a day, a generous allowance, add 0.028 mAh a day, 1.9 % of the worst-case day [C4], and are included in Table 2. The effect is negligible.
- **Pulse capacitor.** A bobbin cell carrying 30 mA leaves 0.06 F of capacitance to cover an EU868 SF12 burst and 0.05 F for US915 SF9, over a 0.5 V droop; a +20 dBm burst as long as SF12 would need 0.36 F [C3]. The main board specifies a hybrid layer capacitor of 0.1 F or more.

## D. Radio link from under the cover (R7)

*Table 3. Link margin at 1 km after the 10 dB fade margin, and the range at zero margin [D1], [D2].*

| Radio | Link budget | Composite cover (10 dB) | Iron cover (20 dB) | Tight iron cover, flooded (30 dB) |
| --- | --- | --- | --- | --- |
| EU868 SF12, +14 dBm | 147.5 dB | +0.3 dB; 1.02 km | **-9.7 dB; 0.53 km** | **-19.7 dB; 0.28 km** |
| US915 SF9, +20 dBm | 146.0 dB | **-1.8 dB; 0.89 km** | **-11.8 dB; 0.46 km** | **-21.8 dB; 0.24 km** |
| EU868 SF7, +14 dBm | 135.0 dB | **-12.2 dB; 0.45 km** | **-22.2 dB; 0.23 km** | **-32.2 dB; 0.12 km** |

Bold values miss 1 km. The urban Hata path loss at 1 km is 127.3 dB at 868 MHz and 127.9 dB at 915 MHz.

*Table 3a. Link margin at 0.5 km, the planned gateway distance under iron covers (LKL-DDR-002), after the 10 dB fade margin [D5].*

| Radio | Iron cover (20 dB) | Tight iron cover, flooded (30 dB) |
| --- | --- | --- |
| EU868 SF12, +14 dBm | +0.9 dB | **-9.1 dB** |
| US915 SF9, +20 dBm | **-1.2 dB** | **-11.2 dB** |
| EU868 SF7, +14 dBm | **-11.6 dB** | **-21.6 dB** |

- **R7 is at risk.** Under the central iron cover the link reaches about 0.53 km at the slowest EU868 rate and 0.46 km at US915 SF9. R7 is restated under LKL-DDR-002 against a gateway within 0.5 km of each district with iron covers; the EU868 link closes there with +0.9 dB to spare, the US915 link misses by 1.2 dB, and a tight cover over a flooded chamber misses by about 9 dB [D5]. To close 1 km the cover may cost no more than 10.3 dB (EU868 SF12) or 8.2 dB (US915 SF9) [D3], which only a composite cover or a through-cover antenna is likely to give; that remains the option where a utility agrees.
- **Transmit power.** EU868 limits the uplink to 14 dBm ERP (16.15 dBm EIRP), so the TRL 2 assumption of +20 dBm is not permitted there [D4]; the design now uses +14 dBm in EU868, as FieldNode does, and up to +20 dBm in US915.
- **Decision.** Decided by Amish, 2026-09-25 (LKL-DDR-002): measure the cover loss first, then plan a gateway within about 0.5 km of each district as the default, with a through-cover antenna or composite cover where a utility agrees. The cover loss measurement is TRL 4 work and on hold; until then the 20 dB figure is an assumption.

## E. Leak noise attenuation along the pipe (R1, R2)

- **Wave speed.** The fluid-dominated wave travels at about 1,270 m/s in the iron mains and 394 m/s (PVC) and 338 m/s (PE) in the plastic ones, because a compliant wall slows it [E1].
- **Attenuation.** On ductile iron it is 0.011 dB/m at 100 Hz and 0.11 dB/m at 1 kHz; on PVC 0.42 dB/m at 100 Hz and 4.2 dB/m at 1 kHz; on PE nearly twice the PVC figure [E1]. Over 100 m of iron, a 200 Hz tone loses 2.2 dB; over 30 m of PVC it loses 25.1 dB and a 50 Hz tone 6.3 dB [E2]. This agrees in kind with the low-frequency, narrow-band leak signals on plastic pipes that Gao et al. (2004) and Hunaidi and Chu (1999, cited in LKL-PRB-001) describe.

## F. Sensor: sensitivity, self-noise and resonances (R3, R4)

- **Sensitivity.** In compression, a piezo disc's charge output is d33 times the seismic mass. The TRL 2 mass of about 11 g gives 32 pC/g; the TRL 3 mass, a brass cylinder 20 mm x 20 mm of about 53 g, gives 157 pC/g. The disc has 21.8 nF; the charge amplifier uses 1 nF and 53 MΩ [F1].
- **Self-noise.** Op-amp voltage noise across the disc capacitance, the feedback resistor's current noise and the disc's dielectric loss give 1.03 µg/√Hz at 100 Hz, 0.83 at 300 Hz and 0.76 at 1 kHz, and 2.95 µg/√Hz at 10 Hz. With the TRL 2 mass the figures were five times higher [F2]. The worst value from 100 Hz to 1 kHz is 1.03 µg/√Hz against the 1 µg/√Hz target [F3], so **R4 is at risk**, 3 % over the target on assumed ceramic and op-amp data. The ADC's contribution is negligible after the 40 dB stage [F4].
- **Seismic resonance.** In compression the disc and mass resonate far above the band, near 200 kHz [F5]. A disc used as a bender, the other way to raise sensitivity, would resonate inside the band.
- **Mounted resonance.** With the 42 mm magnet and the 8 mm puck base of LKL-DDR-003 the puck and magnet weigh about 277 g (262 g in v0.2, 210 g with the 32 mm magnet of v0.1). On a contact stiffness of 5 to 20 MN/m, typical of a magnet on a painted cap but assumed, they resonate at 676 to 1,352 Hz and stay within 3 dB only up to 366 to 732 Hz [F6]; the heavier magnet and base lower both by about 13 %. A fixed correction cannot remove a resonance that changes from site to site, so **R3 is at risk** above about 370 Hz. This matters for R1: the band that sets the detection distance on iron is the 800 Hz third octave (section G), at the edge of the flat range. Near the resonance the mount amplifies the leak and the background alike, so the level is site-dependent rather than lost; the nightly trend compares a logger with itself, which tolerates this better than an absolute threshold would.

## G. Detection distance (R1, R2)

The reference leak (5 L/min at 3 bar) is a 24.5 m/s jet through a 2.7 mm orifice, 25 W of mechanical power at a Mach number of 0.017 [G1]. The script spreads a fraction of that power over the pipe as a flat spectrum, turns the in-pipe pressure into valve acceleration and, in each third-octave band, finds the distance at which the attenuated leak level falls to the combined background and sensor noise. At that distance the band level rises by 3 dB, enough for the nightly minimum to show it.

*Table 4. Detection distance for the reference leak [G2].*

| Pipe | Efficiency 1e-6 | Efficiency 1e-5 (central) | Efficiency 1e-4 | Target |
| --- | --- | --- | --- | --- |
| Ductile iron DN150 | 105 m | 185 m | 325 m | 100 m (R1) |
| Cast iron DN150 | 99 m | 175 m | 308 m | 100 m (R1) |
| PVC DN150 | 2 m | 4 m | 7 m | 30 m (R2) |
| PE100 DN150 SDR11 | 1 m | 2 m | 4 m | 30 m (R2) |

- **Limiting band.** The detection distance is set by the 800 Hz third octave on iron and the 1 kHz band on plastic [G2]. Leak pressure turns into valve acceleration in proportion to the square of frequency, so the higher bands win until pipe attenuation takes over.
- **R1 is at risk.** The central estimate on ductile iron is 185 m, but halving or doubling the pipe loss factor moves it to 370 m or 93 m [G3], and the source efficiency spans a factor of 100. Only field recordings of known leaks can pin these down.
- **R2 is not met.** A contact sensor on a valve hears only a few metres along a plastic main in this model; halving the pipe loss factor gives 8 m [G3]. The model is pessimistic at low frequency, because a stiff metal valve body converts pressure into very little acceleration there, and practice with hydrophones on plastic mains reaches further. That is the case for the hydrophone variant kept open in decision D3. Under LKL-DDR-002 the contact sensor's scope is metallic mains and R2 applies to the hydrophone variant, which is not sized in this note; the contact sensor figures above are kept for the record.

## H. Clock (R5)

- **Free running.** A ±20 ppm crystal in a chamber at 5 to 20 °C drifts by 54 to 87 s in 30 days [H1], which misses the 1 min a month in R5.
- **Corrected.** A weekly network time request (LoRaWAN 1.0.3 DeviceTimeReq, answered by any compliant network server) holds the error to 20 s at worst [H2]. **R5 is met on paper** with that correction, which is now part of the design.

## I. Magnet hold (R9)

*Table 5. Pull on a cast or ductile iron spindle cap [I1].*

| Magnet | 0.1 mm gap (bare) | 0.3 mm (paint) | 0.5 mm (paint and rust) | 1.0 mm (heavy coating) |
| --- | --- | --- | --- | --- |
| 32 mm pot, 290 N rated (v0.1, replaced) | 149 N | **90 N** | **60 N** | **29 N** |
| 42 mm pot, about 600 N rated (fitted) | 309 N | 187 N | 125 N | **59 N** |

- **R9 is met on paper.** The 32 mm magnet of v0.1 met 100 N only on a bare or lightly coated cap. The 42 mm magnet fitted under LKL-DDR-002 (it fits the 50 mm cap) meets it up to a 0.5 mm coating, and only a heavy 1 mm coating defeats it. The magnet itself carries only about 3.0 N of static load, since the puck sits on top of the cap [I2]; the 100 N target covers a snagged cable or a knock. Non-ferrous caps, outside R9's target, still need an adapter. The larger magnet roughly doubles the pinch hazard; it ships with its keeper plate fitted.

## J. Chamber survival (R11)

- **Submersion.** 1 m of water puts 9.8 kPa on the O-rings and the M12 socket [J1], well within the rating of static O-ring seals and IP68 connectors.
- **Flooding.** The logger body (tube, flanged plugs, fittings, chassis and electronics) weighs about 551 g and displaces 748 g of water, so in a flooded chamber it floats up against the lanyard with 1.9 N [J2]. The lanyard, eye bolt and neck bar carry that by a wide margin.
- **Condensation.** The free air in the tube holds about 5 mg of water at saturation; a 10 g silica gel pack holds about 2,000 mg [J3]. Long-term vapour ingress through the seals cannot be estimated on paper. **R11 is met by design**; a submersion test is TRL 4 work and on hold.

## K. Size, mass and installation (R10, R12)

- **Size and mass.** The logger is 63 mm in diameter (68 mm over the radial screw heads) and 240 mm long flange to flange, 283 mm with its socket and eye bolt, within R12's 70 x 300 mm. Made parts are weighed from their model volume and material, bought parts from catalogue figures. The whole set weighs 1.35 kg [K1]: the housing with its acetal plugs 365 g, the neck bar with feet and lanyard 322 g, the cable 140 g, the magnet 126 g, the cell 90 g, the puck body 78 g and the antenna 70 g. The logger, cable and sensor alone weigh 0.96 kg; the 70 g antenna rides on the bar and is counted with it. The neck bar that replaced the concept's 51 g strap (LKL-DDR-003, P1) puts the whole set 0.35 kg over 1.0 kg. On 2026-10-02 Amish restated R12 as 1.0 kg for the logger, cable and sensor, with the bar counted as site hardware (LKL-DDR-003, A1), so **R12 is met on paper** at 0.96 kg, a margin of 0.04 kg (38 g) on estimated masses; the logger set is weighed at TRL 4.
- **Reach.** The cable plug sits 0.48 m below the street, so the 2 m cable with 0.3 m of slack reaches a spindle cap 2.18 m down, covering chambers up to the 1.5 m of R10 [K2].
- **Time.** The task estimate is 11 min: 3 min for cones and cover, 2 min to lower the puck on a pole, 2 min to set the neck bar with the logger and antenna already fitted and plug in the cable, 2 min to check the network join and 2 min to close up [K3]. It is 1 min over the R10 target and has not been shown with a crew, so **R10 is not verifiable at TRL 3**.

## L. False alarms (R13)

Random night-to-night scatter in the minimum level does not cause false alarms: with a 2 dB scatter and a flag at +6 dB for three nights, the rate is about 1e-6 per 20 loggers a month, and 7e-3 even at 3 dB scatter [L1]. Real false alarms come from persistent changes: a pump schedule, a pressure reducing valve that starts to hunt, a customer's night irrigation. Their rate is a property of the network, so **R13 is not verifiable at TRL 3**.

## M. Cost (R15)

Thirteen BOM lines, every one priced [M1]. Value-engineering target: USD 130 (`budget_usd`, a hypothetical control target, not a limit). Estimated cost of the constructable design: USD 142 (USD 12 over the target). The constructable design added USD 28 to the USD 113 of v0.2 (USD 141 before the light pipe): the neck bar (USD 12 more than the strap), the turned plugs, O-rings and screws (USD 4), the chassis (USD 4), the eye bolt and SMA bulkhead (USD 7), the thicker puck (USD 1) and, added on 2026-10-02, the status light pipe (USD 1). **R15 is USD 12 over the value-engineering target.**

## N. Requirement status

*Table 6. Requirement status from this note [N]. Not met first, then at risk, then open.*

| ID | Requirement | Value | Target | Status |
| --- | --- | --- | --- | --- |
| R12 | Size and mass | 68 x 283 mm; logger, cable and sensor 0.96 kg (1.35 kg with the neck bar) | 70 x 300 mm; 1.0 kg for the logger, cable and sensor (restated 2026-10-02) | Met on paper (0.04 kg margin) |
| R1 | Hear a leak on metallic mains | 185 m on ductile iron at central efficiency (105 to 325 m over source efficiency, 93 to 370 m over pipe loss) | 100 m | **At risk** |
| R3 | Sensor bandwidth | Mounted resonance 676 to 1,352 Hz; flat to 366 to 732 Hz | 5 Hz to 2 kHz, ±3 dB after correction | **At risk** |
| R4 | Sensor self-noise | 1.03 µg/√Hz worst from 100 Hz to 1 kHz | 1 µg/√Hz | **At risk** |
| R7 | Radio link | Range 0.53 km under an iron cover at 20 dB (EU868 SF12), 0.46 km (US915 SF9); cover loss unmeasured | 90 % delivery to a gateway within 0.5 km under iron covers | **At risk** |
| R2 | Hear a leak on plastic mains | Hydrophone variant not sized; the contact sensor (out of scope for plastic) hears 4 m on PVC | 30 m, hydrophone variant | Open, variant not sized at TRL 3 |
| R10 | Install from the surface | 11 min task estimate; reach to 2.18 m | 10 min, 1.5 m, no entry | Not verifiable at TRL 3 |
| R13 | Leak flag quality | Random scatter negligible; site events unknown | 1 per 20 loggers per month | Not verifiable at TRL 3 |
| R5 | Night listening | 20 s worst with weekly time correction | 12 windows, under 1 min a month | Met on paper |
| R6 | Battery life | 10.1 years or more on energy | 5 years | Met on paper |
| R9 | Attachment | 125 N at a 0.5 mm coating (187 N at 0.3 mm, 309 N bare) | 100 N | Met on paper |
| R15 | Cost | $142.00 | $130 value-engineering target | USD 12 over the value-engineering target |
| R8 | Data and privacy | Processed as sampled, deleted on device | Only levels and spectra leave | Met by design |
| R11 | Survive the chamber | IP68 parts; floats on its lanyard when flooded | IP68, -20 to +50 °C | Met by design |
| R14 | Open and interoperable | 24-byte LoRaWAN 1.0.3 uplink, documented | Standard LoRaWAN | Met by design |

## O. TRL 2 figures checked

*Table 7. TRL 2 figures against this note.*

| TRL 2 figure | This note | Outcome |
| --- | --- | --- |
| 3.84 MB sampled a night | 3.84 MB [A1] | Stands |
| About 50 bytes sent a night | 24 bytes [A4] | Changed; the precis is updated |
| About 1.15 mAh a day | 1.18 to 1.25 mAh [C1], with the status light blink | Stands |
| About 12.8 years on energy, about 10 years life | 10.1 to 12.5 years [C1] | Stands |
| Radio at 20 dBm, 120 mA | +14 dBm in EU868 [D4] | Changed |
| Magnet hold about 95 N, marginal | 90 N at 0.3 mm, 60 N at 0.5 mm [I1] | Stood; 42 mm magnet fitted (LKL-DDR-002) |
| 63 x 240 mm, about 0.7 kg | 63 x 240 mm (283 mm overall), 1.35 kg with the neck bar [K1] | Mass changed (v0.2: 0.98 kg); the precis is updated |
| About $108 in parts | $142.00 [M1] | Changed: $113.00 in v0.2 (mass $1, magnet $4); constructable design $28 more |

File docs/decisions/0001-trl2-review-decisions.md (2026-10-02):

---
doc_id: LKL-DDR-001
title: LeakListen TRL 2 review decisions
project: LeakListen
doc_type: Design decision record
version: "0.3"
status: Draft
date: '2026-10-02'
author: Amish Chadha
license: CERN-OHL-S-2.0
revisions:
- version: "0.1"
  date: '2026-09-25'
  author: Amish Chadha
  change: Record the TRL 2 review items adopted as recommended for TRL 3 under Amish's 2026-09-25 instruction, and the items that remain open
- version: "0.2"
  date: '2026-09-25'
  author: Amish Chadha
  change: "Recommendations accepted by Amish (DDR-002): D1 to D6 decided; O1 and O2 still open"
- version: "0.3"
  date: '2026-10-02'
  author: Amish Chadha
  change: "O1 and O2 decided by Amish on 2026-10-02 (LKL-DEC-001, items 4 and 5)"
---

# 0001: TRL 2 review decisions

- **Date:** 2026-09-25
- **Status:** accepted for D1 to D6. On 2026-09-25 Amish wrote "i accept all your recommendations, go with them across all repos", so D1 to D6 are "Decided by Amish, 2026-09-25: go with recommendation" (see LKL-DDR-002). Items O1 and O2 had no recommendation and remain "Proposed, awaiting Amish". O1 and O2 were decided by Amish on 2026-10-02 as recommended in the design decisions register (LKL-DEC-001, items 4 and 5): "i approve your recommendations for all 555 open decisions."

## Context

The TRL 2 review note (`docs/REVIEW.md`, session 2026-09-25, /populate) listed eight items as "Proposed, awaiting Amish". On 2026-09-25 Amish asked for this batch of repos to be taken through the usual process with the instruction "you know the drill, nothing gets past TRL 3". He has not reviewed this repo's items one by one. Every item that carried a recommendation is therefore adopted as recommended for TRL 3 under Amish's 2026-09-25 instruction, open for his review. Items without a recommendation stay open. Version 0.1 of this record contained no decision made by Amish; version 0.2 records his acceptance of D1 to D6 on 2026-09-25.

## Options considered

The options for each item are those listed in `docs/REVIEW.md` (session 2026-09-25, /populate) and in LKL-PRC-001 v0.2, Key design choices.

## Decision

*Table 1. Items decided.*

| # | Item | Recommendation (now the decision) | Status |
| --- | --- | --- | --- |
| D1 | Screening versus correlation (pitch-level) | Option A: nightly noise-level screening only. Time-synchronized correlation between loggers (option B) is recorded as a later variant. | Decided by Amish, 2026-09-25: go with recommendation |
| D2 | Radio from under covers | Option A: flat antenna under the cover, with the TRL 3 link budget deciding whether a through-cover antenna (B) or a nearby gateway (C) is needed. LKL-CAL-001 section D finds that it is needed under iron covers; the response is decided in LKL-DDR-002. | Decided by Amish, 2026-09-25: go with recommendation |
| D3 | Sensor type | Piezo disc with a charge amplifier, with a hydrophone on hydrants kept as an option for plastic networks. | Decided by Amish, 2026-09-25: go with recommendation |
| D4 | Reuse of the FieldNode radio core | Yes: the STM32WL module and payload conventions are shared with FieldNode; FieldNode's solar power is not used. | Decided by Amish, 2026-09-25: go with recommendation |
| D5 | Primary cell size | C size, about 7.7 Ah. | Decided by Amish, 2026-09-25: go with recommendation |
| D6 | Privacy rule | Raw samples never leave the device; R8 is kept as a fixed requirement. | Decided by Amish, 2026-09-25: go with recommendation |

*Table 2. Items that remain open.*

| # | Item | Status |
| --- | --- | --- |
| O1 | First partner utility and region for co-design and a pilot district. No recommendation was made. | Decided by Amish, 2026-10-02 (LKL-DEC-001, item 4): a water utility with metallic mains, district metered areas and a leakage target; first candidate region to approach, the UK (radio band EU868). Nothing is agreed. |
| O2 | Whether a vibration calibration check belongs in LeakListen or in CalRig (CalRig covers temperature, humidity and particles only). No recommendation was made. | Decided by Amish, 2026-10-02 (LKL-DEC-001, item 5): a small shaker bay in CalRig, with LeakListen defining the acceptance test (frequency range, level and pass band) in its own repo. |
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

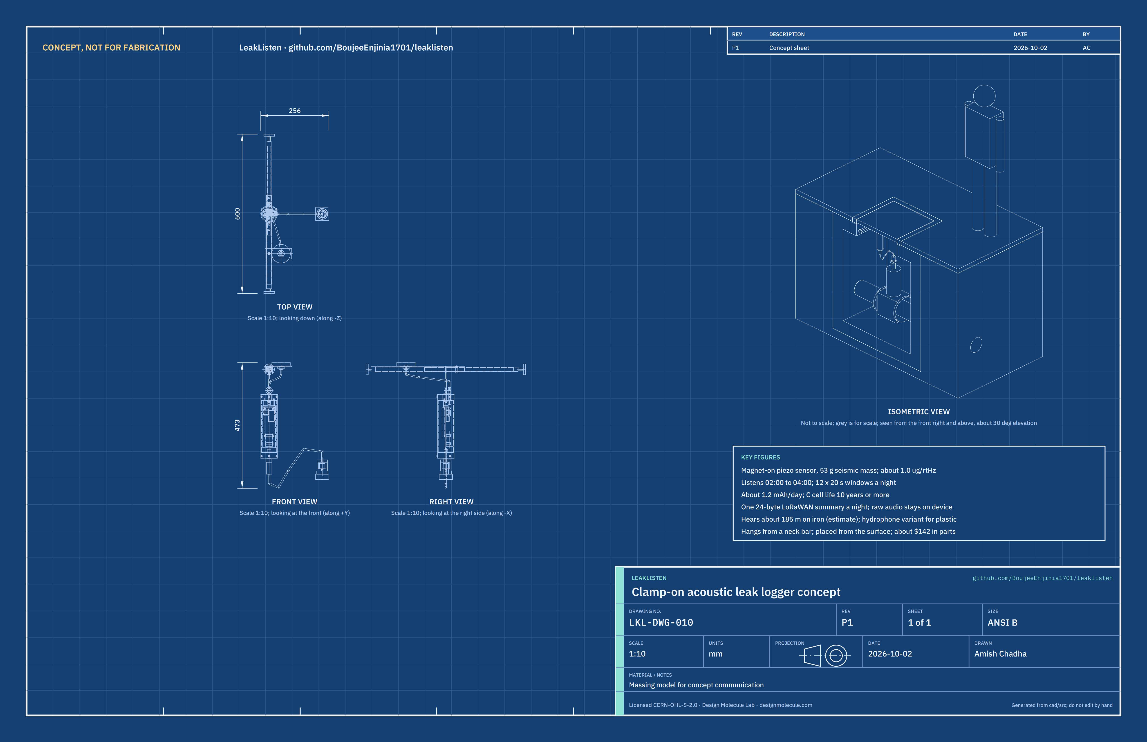
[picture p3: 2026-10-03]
media/concept-blueprint.png

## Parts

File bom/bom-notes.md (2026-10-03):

# BOM notes

- Costs are indicative USD prices for one prototype logger, from typical distributor and hobby market prices in 2026. Every line is priced; supplier types are given where no supplier is chosen yet.
- Line numbers match the callouts in `media/exploded.png`. Line 11 has no callout.
- Lines 12 and 13 were added and lines 1, 6 and 9 repriced when the design was made constructable (LKL-DDR-003, 2026-10-01): the strap hanger became a neck bar (line 9, USD 6 to USD 18), the logger housing gained turned flanged plugs, O-rings and radial screws (line 6, USD 12 to USD 16), the puck base was thickened for the magnet's stud (line 1, USD 8 to USD 9), and the internal chassis (line 12, USD 4) and the eye bolt and SMA bulkhead (line 13, USD 7) are new.
- Value-engineering target: USD 130 (`budget_usd` in `project.yaml`, a hypothetical control target, not a limit). Estimated cost of the constructable design: USD 142 per logger (USD 12 over the target), checked by `docs/04-calcs/sizing.py`, LKL-CAL-001 [M1].
- Changes at TRL 3: the seismic mass grows from about 11 g to about 53 g (line 3, +$1) and the puck from 34 mm to 42 mm tall, so the sensor meets its noise target on paper.
- Decided by Amish, 2026-09-25 (LKL-DDR-002): the 32 mm pot magnet ($5) is replaced by a 42 mm pot magnet with a keeper plate ($9), so the concept total rose from $109.00 to $113.00. The district gateway for iron covers is a TwinKit or partner gateway and is not in the logger's BOM; a through-cover antenna is fitted only where a utility agrees and is not in the total.
- Not included: a LoRaWAN gateway (TwinKit or a partner's network), the placement pole and cover lifting key (utility tools), and any network server costs.
- Decision of 2026-10-02 (LKL-DDR-003 follow-up): line 7 now includes the 3 mm clear acrylic status light pipe rod and its LED, USD 1.00 added (USD 30.00 to USD 31.00), which moves the total from USD 141.00 to USD 142.00. Basis: about USD 0.30 of acrylic rod, a share of a bag of clear epoxy and a status LED at distributor single-piece prices, rounded up.

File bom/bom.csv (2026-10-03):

item | qty | spec | supplier | unit_cost_usd | make_buy | notes
1 Sensor puck body | 1 | Aluminium 6061, 40 mm diameter x 42 mm, turned cup: 8 mm base tapped M6 x 6 mm deep for the magnet stud, 29 mm lower bore, 32 mm upper bore with a step 25 mm above the base for the preamplifier board | Local machinist or online CNC turning service | 9.00 | make | Indicative price for one-off turning; base thickened from 3 mm to take the magnet stud (LKL-DDR-003)
2 Pot magnet | 1 | 42 mm neodymium pot magnet, about 600 N rated pull on thick flat steel, M6 stud cut to 6 mm, with keeper plate | Magnet supplier (industrial pot magnet catalog) | 9.00 | buy | Indicative price; about 125 N on iron with a 0.5 mm coating gap (LKL-CAL-001 [I1]); LKL-DDR-002
3 Piezo disc and seismic mass | 1 | 27 mm brass-backed piezo disc (20 mm ceramic) in compression, with a 20 mm x 20 mm brass mass, about 53 g, epoxy bonded | Electronics distributor plus local machinist | 3.00 | buy | Indicative price; the mass is a slice of 20 mm brass rod (made)
4 Charge preamplifier | 1 | Low-noise JFET-input op-amp (about 5 nV/rtHz), 1 nF and 53 MOhm feedback (3 Hz high-pass), second stage 40 dB, on a round 31 mm board 1.6 mm thick | Electronics distributor | 6.00 | buy | Indicative price; self-noise about 1.0 ug/rtHz (LKL-CAL-001 [F3]); round board seats on the puck's bore step (LKL-DDR-003)
5 Sensor cable | 1 | 2 m shielded PUR cable, 4-core, 6 mm, M12 A-coded IP68 plug at the logger end | Industrial connector supplier | 12.00 | buy | Indicative price for a molded M12 cordset
6 Logger housing | 1 | 63 mm PVC pressure pipe, 3 mm wall, cut to 232 mm; two flanged end plugs turned from 65 mm acetal rod (63 mm flange 4 mm thick, 57 mm spigot 18 mm long, two O-ring grooves); four nitrile O-rings 2.5 mm section; six M4 x 10 stainless pan-head screws; M12 A-coded IP68 front-mount panel socket, M16 thread | Plumbing supplier plus local machinist plus industrial connector supplier | 16.00 | make | Indicative price; IP68 target (R11); flanged plugs and radial screws added (LKL-DDR-003)
7 Main board | 1 | STM32WL LoRaWAN module (FieldNode core), 24-bit audio ADC, RTC crystal, hybrid layer capacitor about 0.1 F or more, fuse and reverse protection, two-layer board; status LED with a 3 mm clear acrylic light pipe rod about 48 mm long, epoxied into a 3 mm hole in the top plug | Electronics distributor plus board house | 31.00 | buy | Indicative price; capacitor sized in LKL-CAL-001 [C3]; light pipe added 2026-10-02 (LKL-DDR-003 follow-up): USD 1.00 on top of the USD 30.00 | basis a 3 mm clear acrylic rod (about USD 0.30 of stock) | a share of a bag of epoxy and a status LED at distributor single-piece prices | rounded up
8 Primary cell | 1 | Lithium thionyl chloride C size, 3.6 V, about 7.7 Ah, with solder tabs | Battery distributor (industrial primary cells) | 12.00 | buy | Indicative price; primary only; never charge; ships as lithium metal dangerous goods
9 Neck bar hanger | 1 | Aluminium square tube 20 x 20 x 1.5 mm and 16 x 16 x 1.5 mm, 350 mm each; two square tube end inserts with M10 nuts; two M10 levelling feet with 40 mm rubber pads; 6 mm locking pin with R-clip; antenna bracket of 40 x 3 mm aluminium flat bar, 100 mm; M5 x 30 bolt and nyloc nut; 3 mm stainless wire rope lanyard with a loop, ferrules and a snap hook | Metal stockist plus local hardware shop | 18.00 | make | Indicative price; replaces the stainless strap and hook (LKL-DDR-003); spans chamber necks of about 570 to 710 mm
10 Flat LoRa antenna | 1 | About 70 mm flat puck antenna for the regional LoRaWAN band, threaded centre stud with nut, 1 m low-loss lead with an SMA plug | Electronics distributor | 10.00 | buy | Indicative price; link from under an iron cover at risk (LKL-CAL-001 section D)
11 Desiccant and consumables | 1 | 10 g silica gel pack, spare O-rings, potting compound, threadlocker, epoxy, owner and lithium warning label | Local hardware and electronics shops | 5.00 | buy | Indicative price; no exploded-view callout
12 Internal chassis | 1 | 3D printed PETG spine 48 x 3 x 158 mm with two cell clips, two capacitor clips and a desiccant pocket; two M3 x 20 hex standoffs; four M3 x 3 nylon standoffs; M3 screws; short lead with a 4-pin plug from the M12 socket to the board | 3D printing (own printer) plus electronics distributor | 4.00 | make | Indicative price; new line (LKL-DDR-003)
13 Top plug fittings | 1 | IP67 SMA female bulkhead with O-ring and nut, with a short pigtail to the board; M6 x 20 stainless eye bolt with a bonded sealing washer and nyloc nut | Electronics distributor plus local hardware shop | 7.00 | buy | Indicative price; new line (LKL-DDR-003); replaces the antenna and lanyard gland

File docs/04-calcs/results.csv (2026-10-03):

id | value | target | status
R1 | 185 m on ductile iron at central efficiency (105 to 325 m) | 100 m on iron | At risk
R2 | hydrophone variant not sized; contact sensor 4 m on PVC (out of its scope) | 30 m on plastic, hydrophone variant | Open, variant not sized at TRL 3
R3 | mounted resonance 676 to 1352 Hz | 5 Hz to 2 kHz within 3 dB | At risk
R4 | 1.03 ug/rtHz | 1 ug/rtHz or less | At risk
R5 | 20 s with weekly time sync | under 60 s a month | Met on paper
R6 | 10.1 years or more on energy | 5 years | Met on paper
R7 | range 0.53 km under an iron cover at 20 dB (EU868 SF12); 0.46 km US915 SF9; cover loss unmeasured | 90 % delivery to a gateway within 0.5 km (iron cover) | At risk
R8 | raw samples processed and deleted on device | only levels leave | Met by design
R9 | 125 N at a 0.5 mm coating (187 N at 0.3 mm) | 100 N | Met on paper
R10 | 11 min task estimate | 10 min, no entry | Not verifiable at TRL 3
R11 | IP68 by design; logger floats on its lanyard | IP68, -20 to +50 degC | Met by design
R12 | 68 x 283 mm, 0.96 kg for logger, cable and sensor (1.35 kg with the neck bar and antenna) | 70 x 300 mm, 1.0 kg for logger, cable and sensor | Met on paper (margin 38 g)
R13 | random variation negligible; site events unknown | 1 per 20 loggers per month | Not verifiable at TRL 3
R14 | 24 B LoRaWAN 1.0.3 uplink | standard LoRaWAN | Met by design
R15 | $142.00 | $130 value-engineering target | $12.00 over the value-engineering target

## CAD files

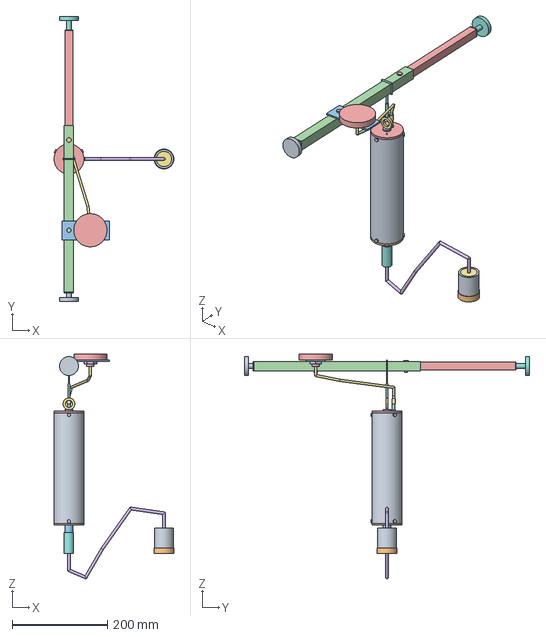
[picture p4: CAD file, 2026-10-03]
cad/step/leaklisten-assembly.step
252.4 x 600.0 x 473.0 mm

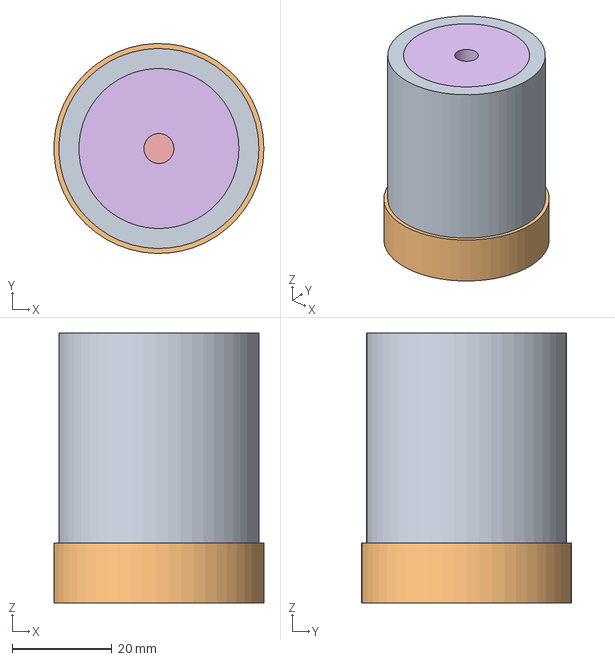
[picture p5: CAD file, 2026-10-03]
cad/step/sensor-puck.step
42.0 x 42.0 x 54.0 mm

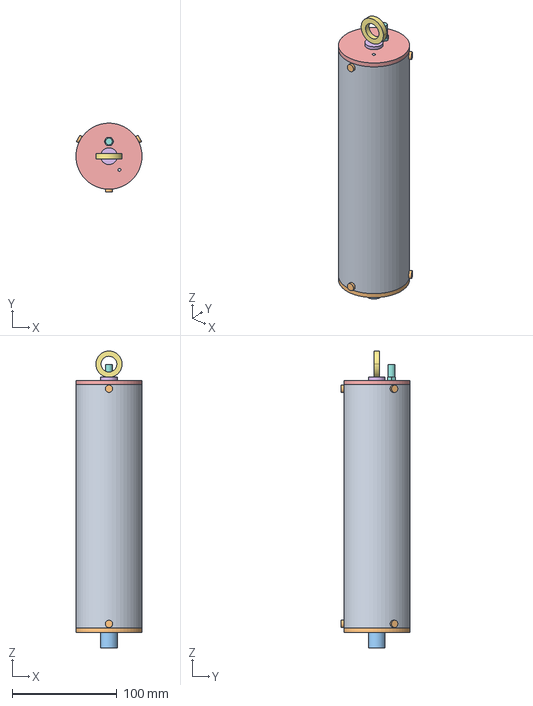
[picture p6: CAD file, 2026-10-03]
cad/step/logger.step
62.9 x 65.5 x 283.0 mm

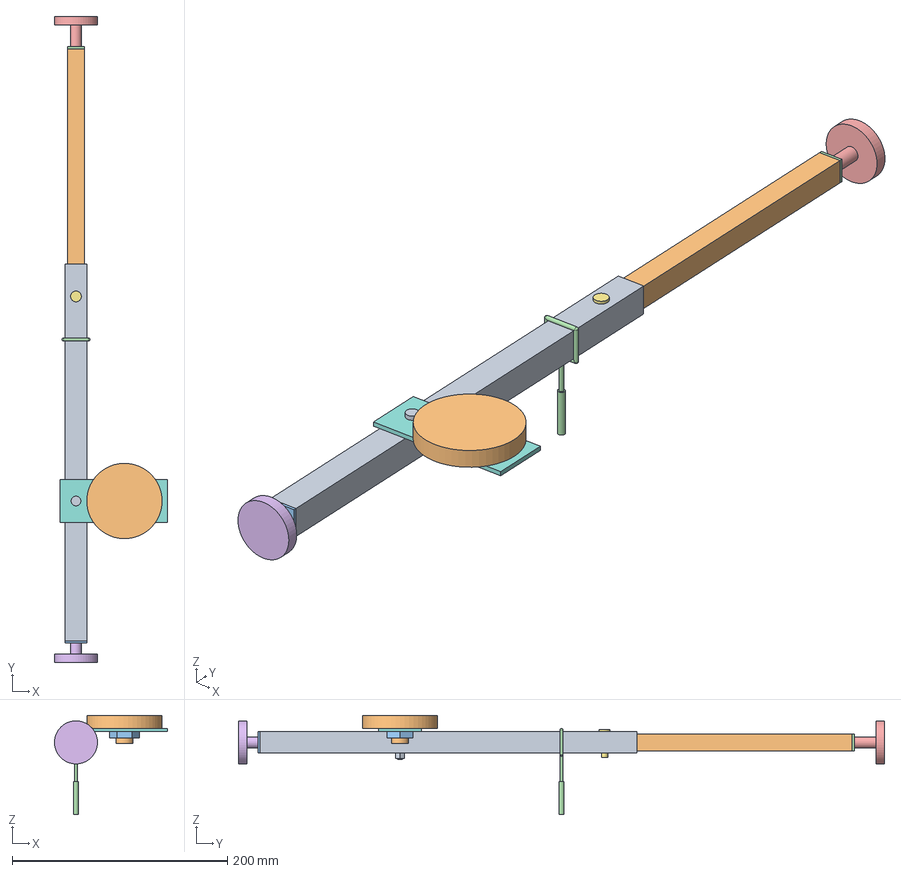
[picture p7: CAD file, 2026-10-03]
cad/step/neck-bar.step
105.0 x 600.0 x 92.0 mm

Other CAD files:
cad/stl/leaklisten-assembly.stl
cad/stl/logger.stl
cad/stl/neck-bar.stl
cad/stl/sensor-puck.stl

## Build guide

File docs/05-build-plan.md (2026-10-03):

---
doc_id: LKL-BLD-001
title: LeakListen prototype build plan
project: LeakListen
doc_type: Build plan
version: "0.3"
status: Draft
date: '2026-10-02'
author: Amish Chadha
license: CERN-OHL-S-2.0
revisions:
  - version: "0.1"
    date: '2026-10-01'
    author: Amish Chadha
    change: First build plan, with pictures by component and step; design made constructable (LKL-DDR-003)
  - version: "0.2"
    date: '2026-10-02'
    author: Amish Chadha
    change: "LKL-DDR-003 recorded as accepted and the R12 acceptance figure set to the restatement, both decided by Amish on 2026-10-02 (LKL-DEC-001, items 1 and 2)"
  - version: "0.3"
    date: '2026-10-02'
    author: Amish Chadha
    change: 'Status light pipe added to the top plug text, parts list and steps 5 and 8; step pictures 5, 7, 8 and 10, joint 8, overview and wiring figure redrawn; general arrangement Rev P5; cost USD 142; no open decisions'
---

# LeakListen prototype build plan

**Plan, not yet built.** How to build the first proof-of-concept prototype, component by component. Building and testing to it is TRL 4 work. Decisions still to be made are kept in the design decisions register ([docs/06-design-decisions.md](06-design-decisions.md)), not here.

## 1. What you are building

Figure 1. Every component, pulled apart and numbered in build order

*Figure 1. Every component pulled apart and numbered in build order: the sensor puck (1 to 5), the logger (6 to 12) and the neck bar that hangs it in the chamber (13 to 18).*

The prototype is one LeakListen set in three parts. The sensor puck is a small turned aluminium cup with a pot magnet under it; inside, a piezo disc and a brass weight turn pipe vibration into a signal, and a small amplifier board, potted in, sends it up a 2 m cable. The logger is a sealed 63 mm PVC tube with a turned plastic plug in each end; inside, a printed frame carries the radio and processing board, a lithium cell and a desiccant pack. The neck bar is a telescopic aluminium bar that wedges across the chamber's neck, just below the cover frame, on two rubber feet; the logger hangs from it on a short wire rope, and a flat antenna sits on a bracket on top of it, just under the cover. Nine components are made in a small workshop: the puck body and the brass weight (turned), the logger tube (cut and drilled), the two end plugs (turned from plastic bar), the frame inside the logger (3D printed), the two bar tubes and the antenna bracket (cut and drilled). Everything else is bought and fitted. The parts cost about USD 142, from the bill of materials.

> **Safety:** The logger holds a lithium thionyl chloride primary cell. It must never be charged, shorted, crushed or heated; keep it in its packaging until stop point S2 (section 6). The pot magnet pulls hard enough to trap fingers and can affect pacemakers; keep its keeper plate on until the puck is at the spindle cap. Valve chambers can be confined spaces: everything in this plan is done at a bench or from the surface, and nobody enters a chamber. Turning, drilling and cutting need eye protection.

## 2. What changed to make it buildable

The concept showed what LeakListen does; some of its parts could not be made or fixed as drawn. Each change below keeps what LeakListen does, and all of them are recorded in decision record LKL-DDR-003, accepted by Amish on 2026-10-02.

*Table 1. Changes from the concept.*

| Component | The concept had | The buildable design has | Why |
| --- | --- | --- | --- |
| Hanger | A stainless strap "hooked over the cover frame", which had nothing to hook over except the seat under the cover | A telescopic aluminium bar wedged across the chamber neck below the frame by two rubber feet; the logger hangs from it on a wire rope lanyard (Figures 15 and 17, steps 11 to 14) | The cover stays seated and nothing is drilled; still placed from the surface |
| Antenna mounting | Overlapping the strap, with no fixing | A small aluminium bracket bolted across the bar, the antenna's own stud through it; the antenna sits 20 mm under the cover (Figure 19) | Nothing overlaps; one bolt and one nut |
| Logger end plugs | Drawn solid with the tube, no way to hold them | Flanged plastic plugs with two O-rings each, held by three screws through the tube outboard of the O-rings (Figures 8 and 10) | Seals for submersion; the screws never cross the seal |
| Top of the logger | One gland for both the lanyard and the antenna lead | An eye bolt for the lanyard and a sealed antenna bulkhead connector, each in its own hole, and a glued-in light pipe rod for the status light (Figures 6 and 12) | A rope and a connector cannot share a gland |
| Inside the logger | Board, cell and desiccant floating | A printed frame hung from the top plug, with clips and a pocket (Figures 9 and 11) | Everything is fixed and lifts out with the top plug |
| Puck base | 3 mm thick, too thin for the magnet's stud | 8 mm thick, tapped for the stud (Figures 2 and 4) | The magnet is screwed on |
| Inside the puck | Amplifier board floating above the weight; "potted" without saying where | A stepped bore: the board sits on the step clear of the weight, and potting fills only the space above the board (Figure 4) | The weight must stand free to sense correctly |

The set now weighs about 1.35 kg with the bar (the logger, cable and puck about 0.96 kg), and is about 283 mm long from socket to eye bolt.

## 3. Making the components

Make and check each component before the assembly step that needs it. Sizes are in millimetres. Workshop tolerance is 0.2 mm on turned diameters that seal or slide and 0.5 mm elsewhere; drawings do not carry tolerances before TRL 4.

### 3.1 Sensor puck body

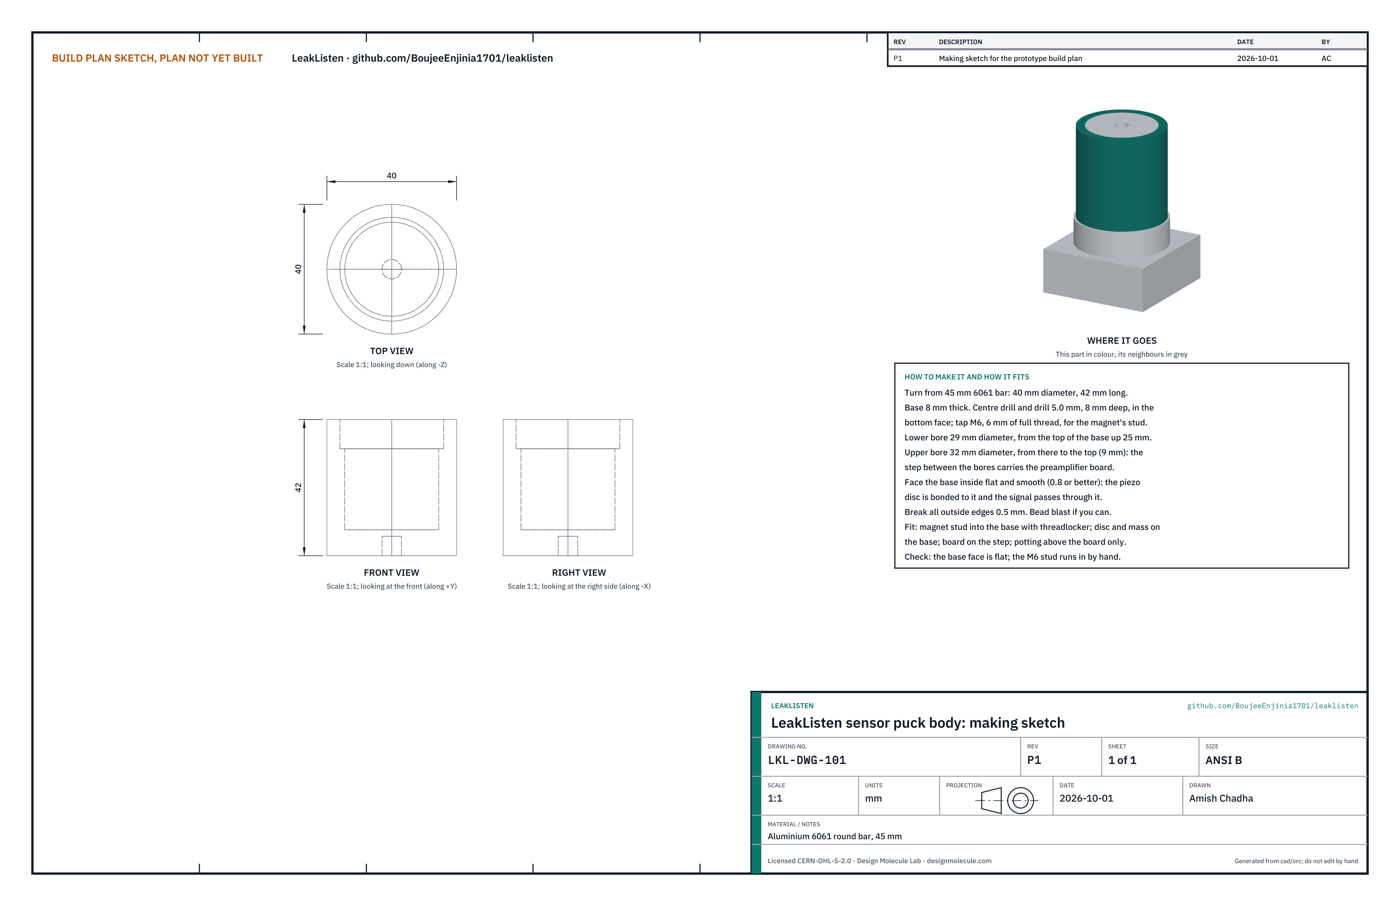
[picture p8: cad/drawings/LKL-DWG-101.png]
Figure 2. Making sketch of the sensor puck body


*Figure 2. Sensor puck body making sketch (LKL-DWG-101).*

**What it is and what it is made from.** The stiff cup that sits on the magnet and carries the sensor. Aluminium 6061 round bar, 45 mm, turned to 40 mm diameter and 42 mm long.

**How to make it.**

1. Face and turn the bar to 40 mm diameter; part off 42 mm long.
2. Bore the lower bore 29 mm diameter, leaving a base 8 mm thick; then bore the upper 9 mm to 32 mm diameter. The step between them is 25 mm above the base.
3. Finish the inside face of the base flat and smooth: the piezo disc is bonded to it and the signal passes through it.
4. Turn the part round. Centre drill the bottom face, drill 5 mm, 8 mm deep, and tap M6 for 6 mm of full thread.
5. Break all outside edges 0.5 mm.

**How it fits the parts next to it.** The magnet's stud screws into the base. The piezo disc is bonded to the inside of the base, the brass weight to the disc, and the round amplifier board rests on the step. Potting fills the upper bore above the board (Figure 4).

**Check before moving on.** The base face is flat when checked with a straight edge; the magnet's stud runs into the thread by hand.

### 3.2 Seismic mass

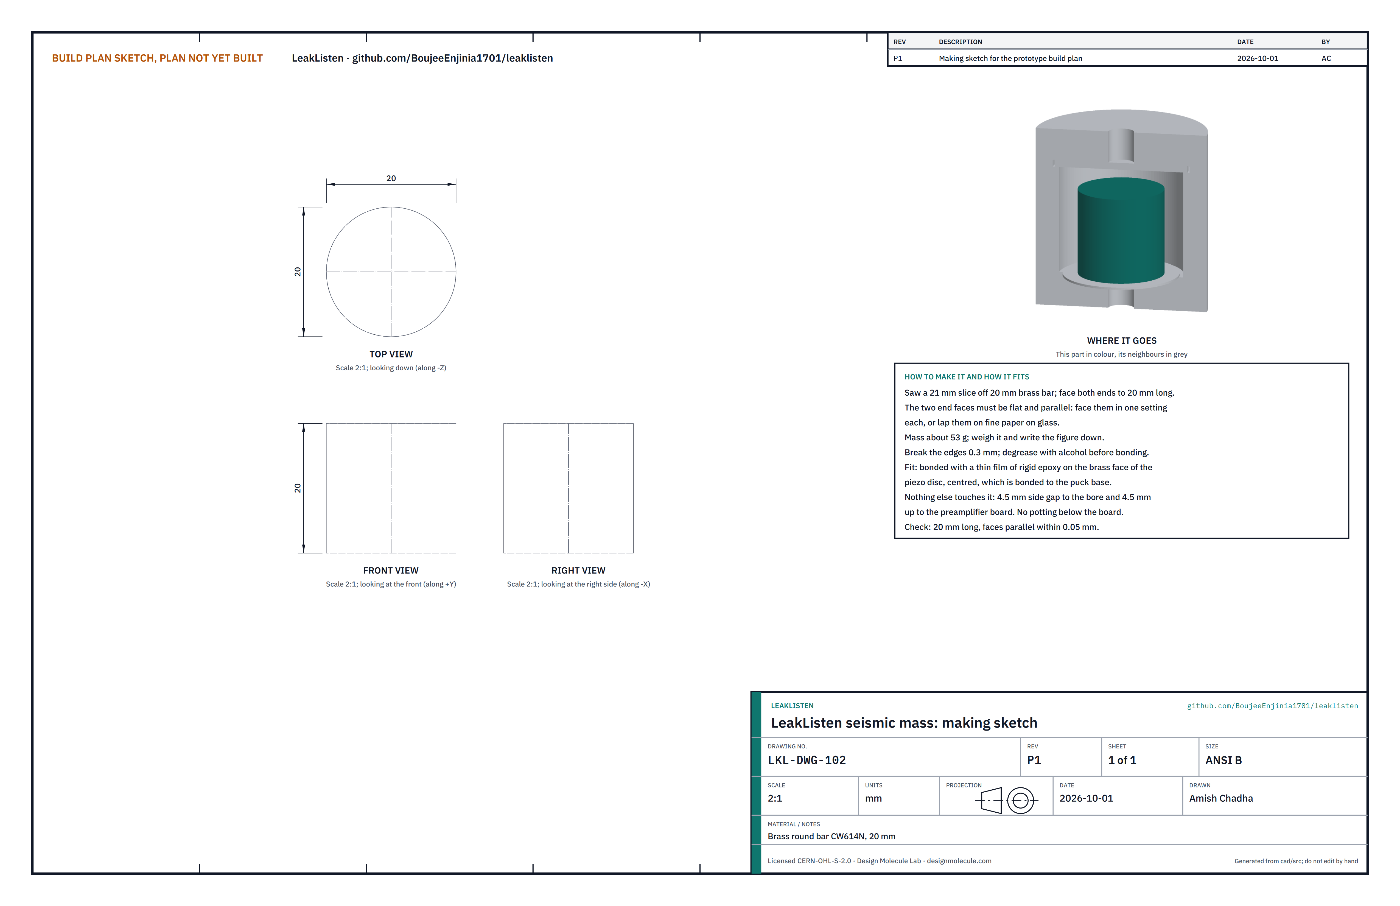
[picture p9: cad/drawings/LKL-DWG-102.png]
Figure 3. Making sketch of the seismic mass


*Figure 3. Seismic mass making sketch (LKL-DWG-102).*

**What it is and what it is made from.** The brass weight that presses on the piezo disc; its inertia is what makes the disc sense vibration. Brass round bar, 20 mm, 20 mm long, about 53 g.

**How to make it.**

1. Saw a 21 mm slice off the bar.
2. Face both ends to 20 mm long, flat and parallel, in one setting each (or lap them on fine abrasive paper on glass).
3. Break the edges 0.3 mm, weigh the part and write the mass down.
4. Degrease with alcohol just before bonding.

**How it fits the parts next to it.**

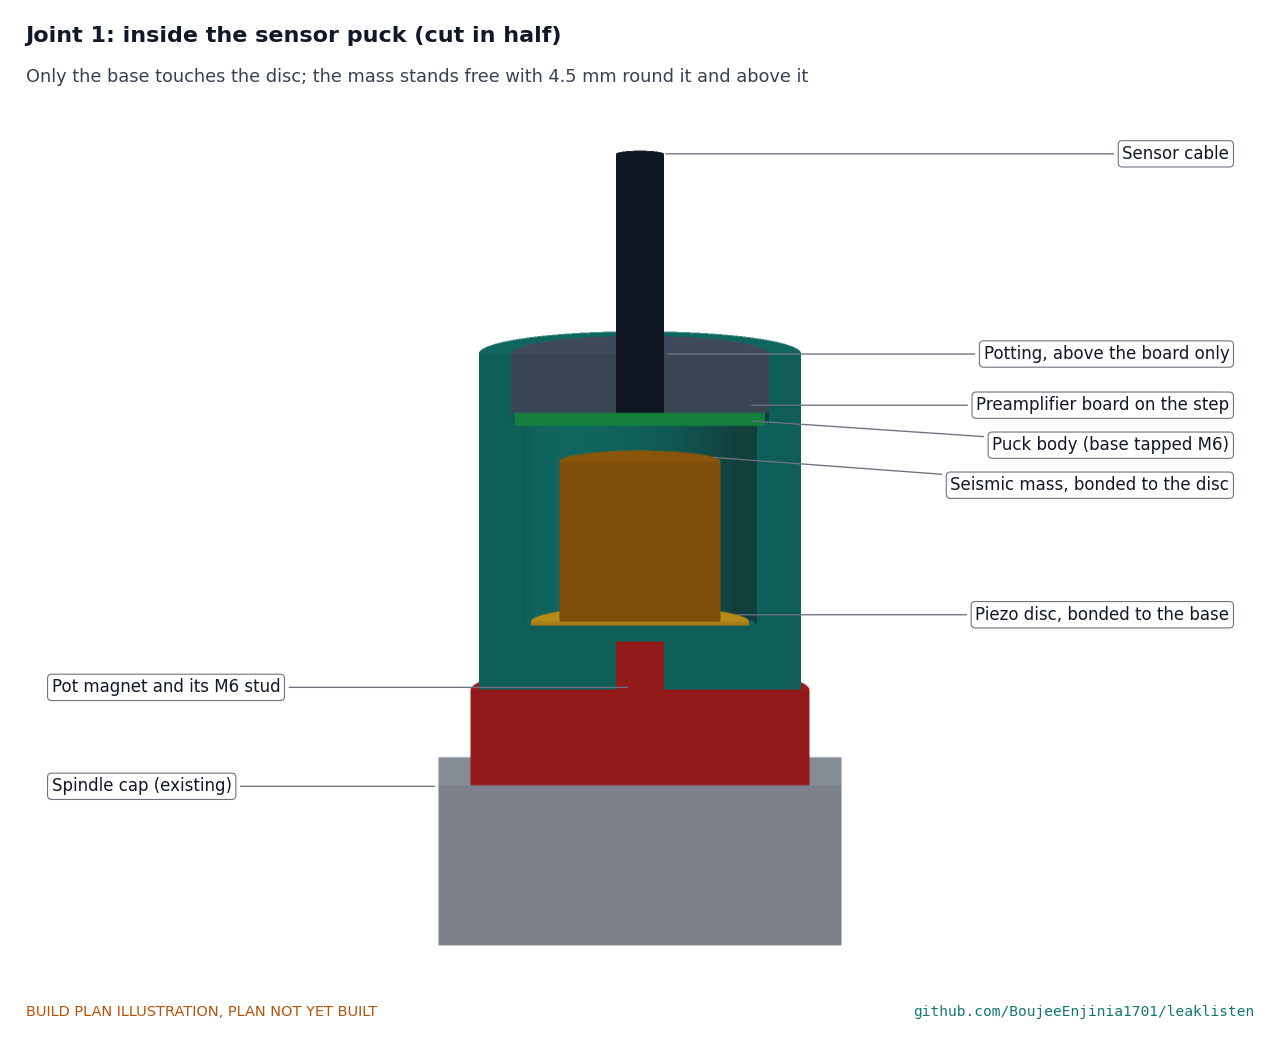
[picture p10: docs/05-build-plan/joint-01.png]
Figure 4. Joint 1: inside the sensor puck, cut in half


*Figure 4. Only the base touches the disc and only the disc touches the weight; the weight has 4.5 mm of air round it and above it.*

A thin film of rigid epoxy bonds the weight, centred, to the brass face of the piezo disc; another bonds the disc to the puck base. Nothing else touches the weight: potting must never run below the amplifier board.

**Check before moving on.** 20 mm long, faces parallel within 0.05 mm.

### 3.3 Bought parts for the sensor puck

- **Pot magnet.** 42 mm neodymium pot magnet, about 600 N rated pull on thick steel, with an M6 stud and a keeper plate. Cut the stud to 6 mm with a hacksaw, keeper plate on, and file the end.
- **Piezo disc.** 27 mm brass-backed piezo disc with a 20 mm ceramic and fine leads.
- **Amplifier board.** The charge amplifier built on a round board 31 mm in diameter, 1.6 mm thick, so it rests on the puck's step.
- **Sensor cable.** 2 m shielded four-core cable, 6 mm, with a moulded M12 plug at one end and bare wires at the other.

### 3.4 Logger tube

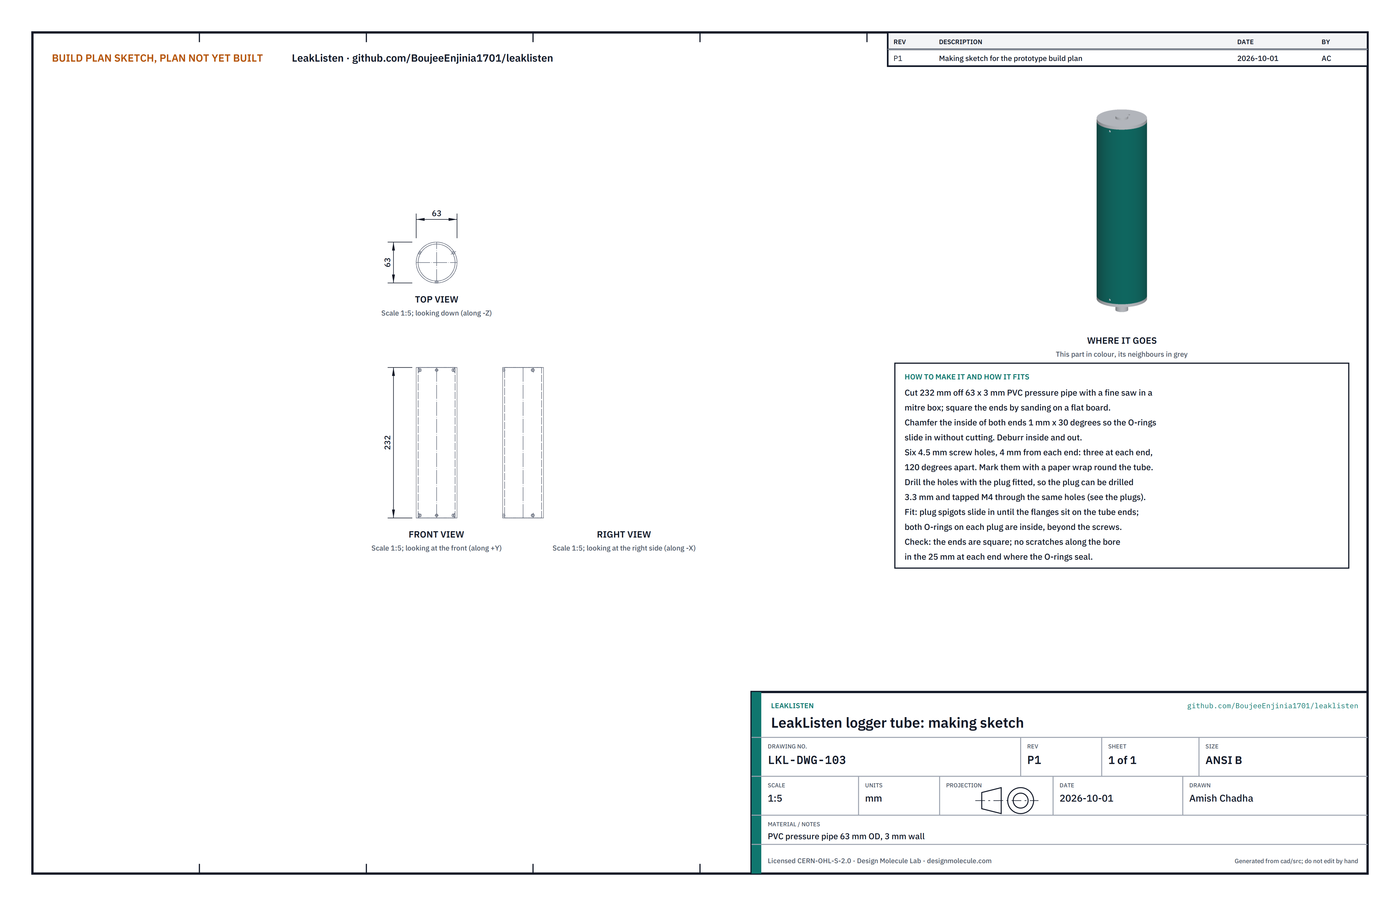
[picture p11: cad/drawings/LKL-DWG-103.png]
Figure 5. Making sketch of the logger tube


*Figure 5. Logger tube making sketch (LKL-DWG-103).*

**What it is and what it is made from.** The body of the logger. PVC pressure pipe, 63 mm outside diameter, 3 mm wall, cut to 232 mm.

**How to make it.**

1. Cut 232 mm with a fine saw in a mitre box; square the ends on abrasive paper laid on a flat board.
2. Chamfer the inside of both ends 1 mm at 30° so the O-rings slide in without being cut. Deburr inside and out.
3. Mark three screw positions at each end, 4 mm from the end and 120° apart, using a paper strip wrapped round the tube.
4. Drill the six holes 4.5 mm only when each plug is in place (section 3.5), so the plug is drilled through the same holes.

**How it fits the parts next to it.** Each plug's spigot slides into one end until its flange meets the tube end. Both O-rings on each plug sit inside the tube, further in than the screws (Figure 10).

**Check before moving on.** The ends are square; the 25 mm of bore at each end, where the O-rings seal, is free of scratches.

### 3.5 Top end plug

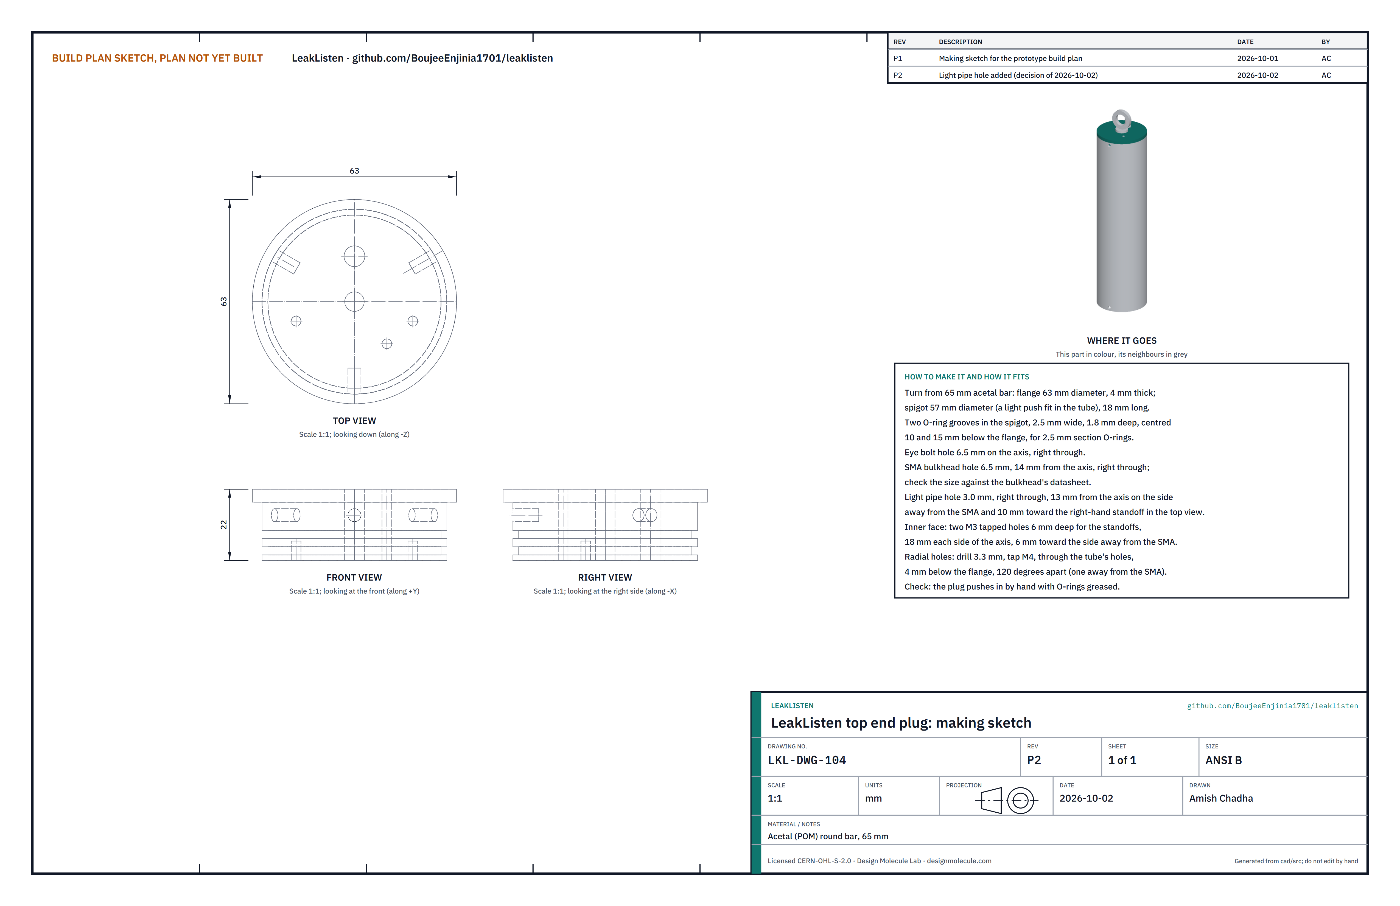
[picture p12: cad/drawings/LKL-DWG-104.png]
Figure 6. Making sketch of the top end plug


*Figure 6. Top end plug making sketch (LKL-DWG-104).*

**What it is and what it is made from.** The plug that closes the top of the logger and carries the eye bolt, the antenna connector, the status light pipe and the internal frame. Acetal (POM) round bar, 65 mm.

**How to make it.**

1. Turn a flange 63 mm in diameter and 4 mm thick, and a spigot 57 mm in diameter and 18 mm long that pushes into the tube by hand.
2. Cut two O-ring grooves in the spigot, 2.5 mm wide and 1.8 mm deep, centred 10 and 15 mm below the flange.
3. Drill a 6.5 mm hole on the axis for the eye bolt, and a 6.5 mm hole 14 mm off the axis for the antenna connector (check its datasheet for the size).
4. Drill a 3.0 mm hole right through for the status light pipe: 13 mm from the axis on the side away from the antenna connector, and 10 mm toward the right-hand standoff as Figure 6 shows it. It sits over the top edge of the board once the frame is hung.
5. On the inner face, drill and tap two M3 holes 6 mm deep for the standoffs: 18 mm each side of the axis, on a line 6 mm from the axis on the side away from the antenna connector.
6. With the plug pushed into the tube and the antenna connector hole pointing where you want it, drill the tube's three top holes 4.5 mm (section 3.4), then drill on into the plug 3.3 mm and tap M4. Put the antenna connector between two screws, not over one.

**How it fits the parts next to it.** See Figure 10 and Figure 12. The flange sits on the tube end; the screws go through the tube 4 mm below the flange.

**Check before moving on.** With greased O-rings the plug pushes in by hand and the screws run in freely.

### 3.6 Bottom end plug

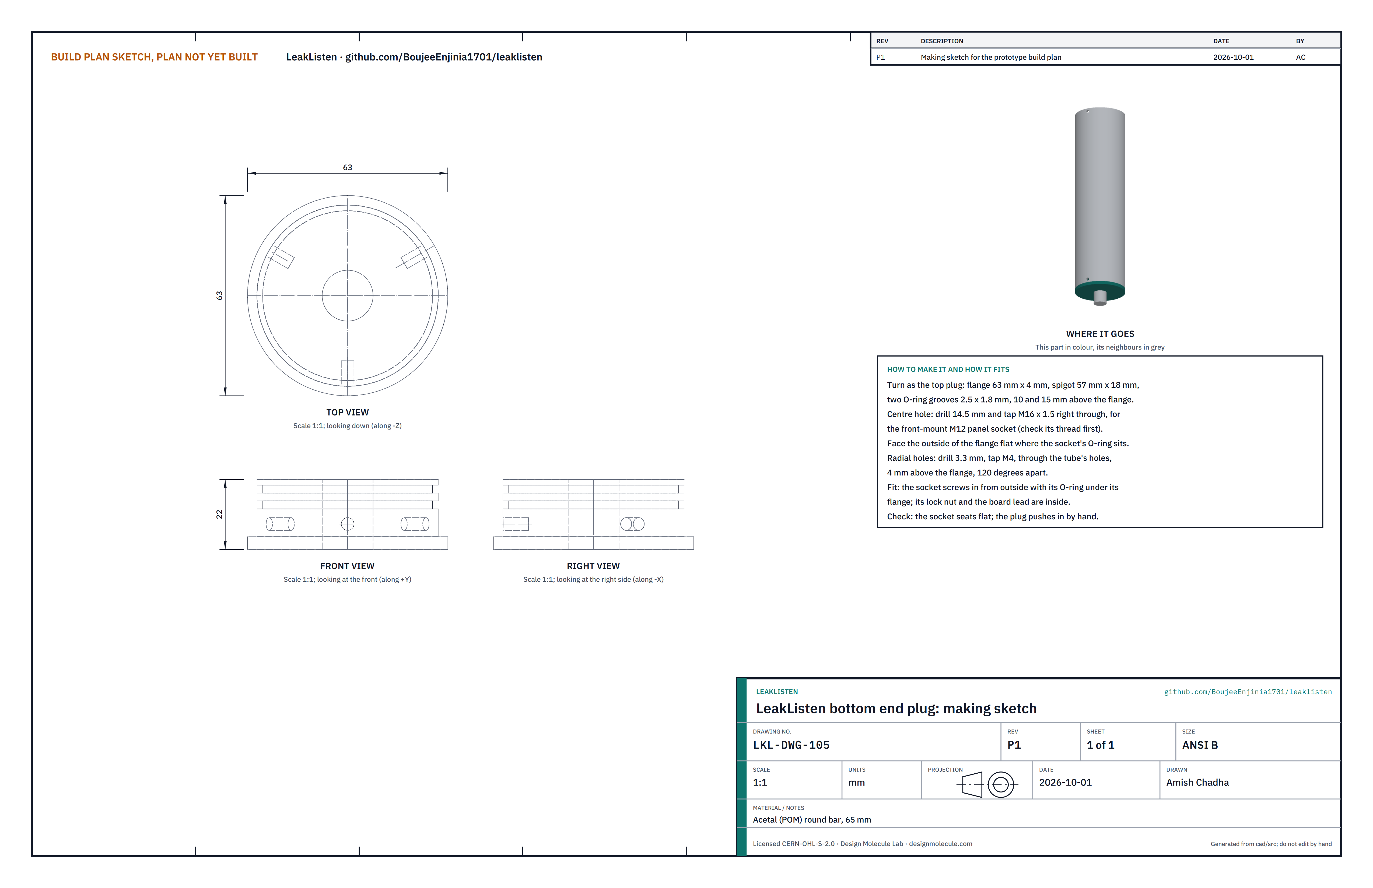
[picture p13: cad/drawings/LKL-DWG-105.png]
Figure 7. Making sketch of the bottom end plug


*Figure 7. Bottom end plug making sketch (LKL-DWG-105).*

**What it is and what it is made from.** The plug that closes the bottom of the logger and carries the cable socket. Acetal (POM) round bar, 65 mm.

**How to make it.**

1. Turn the flange and spigot as the top plug, with the two O-ring grooves 10 and 15 mm above the flange.
2. Drill 14.5 mm right through on the axis and tap M16 x 1.5 for the panel socket (check the socket's thread first).
3. Face the outside of the flange flat where the socket's O-ring seats.
4. Drill and tap the three radial holes through the tube, as for the top plug.

**How it fits the parts next to it.**

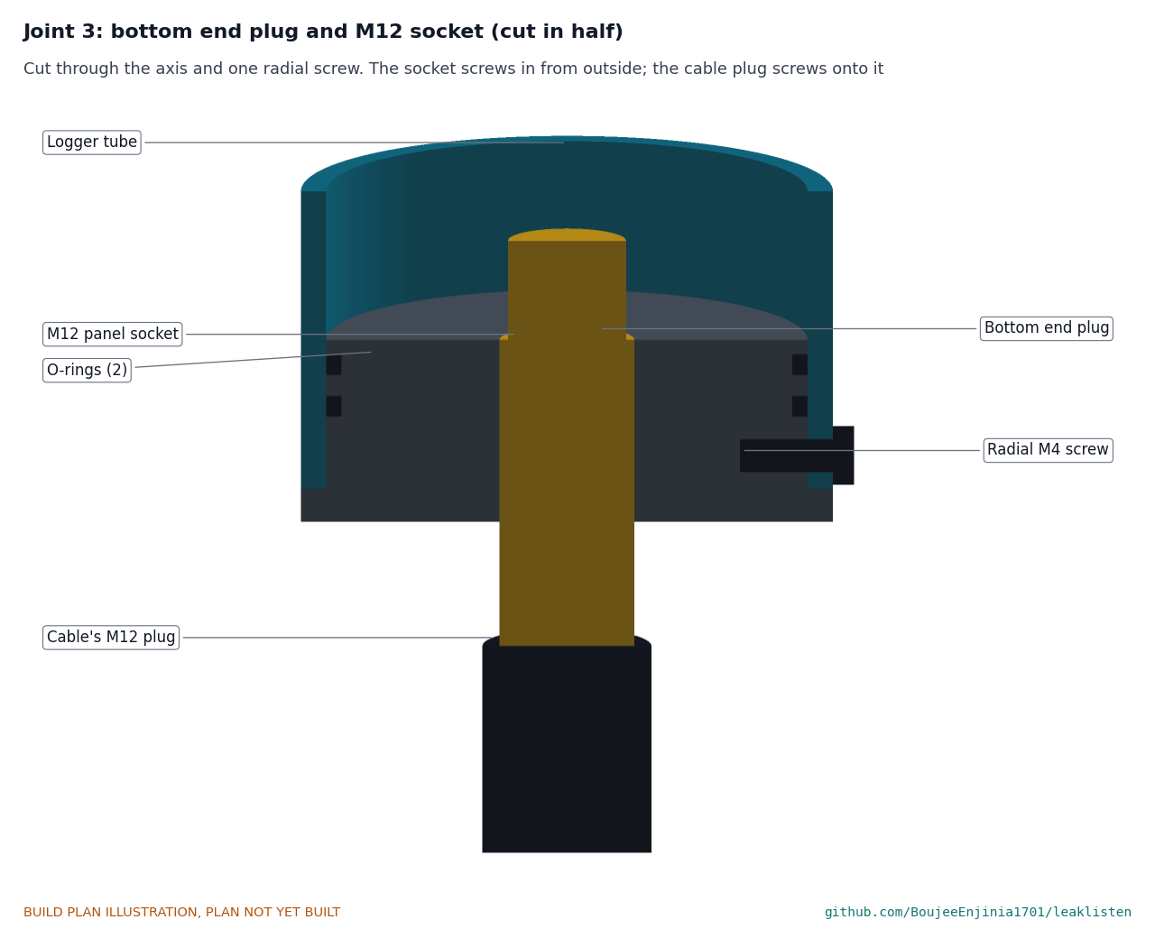
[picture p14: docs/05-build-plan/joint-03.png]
Figure 8. Joint 3: bottom end plug and socket, cut in half


*Figure 8. The socket screws into the plug from outside, sealed by its own O-ring; the cable's plug screws onto the socket.*

**Check before moving on.** The socket seats flat on the flange; the plug pushes in by hand.

### 3.7 Internal frame

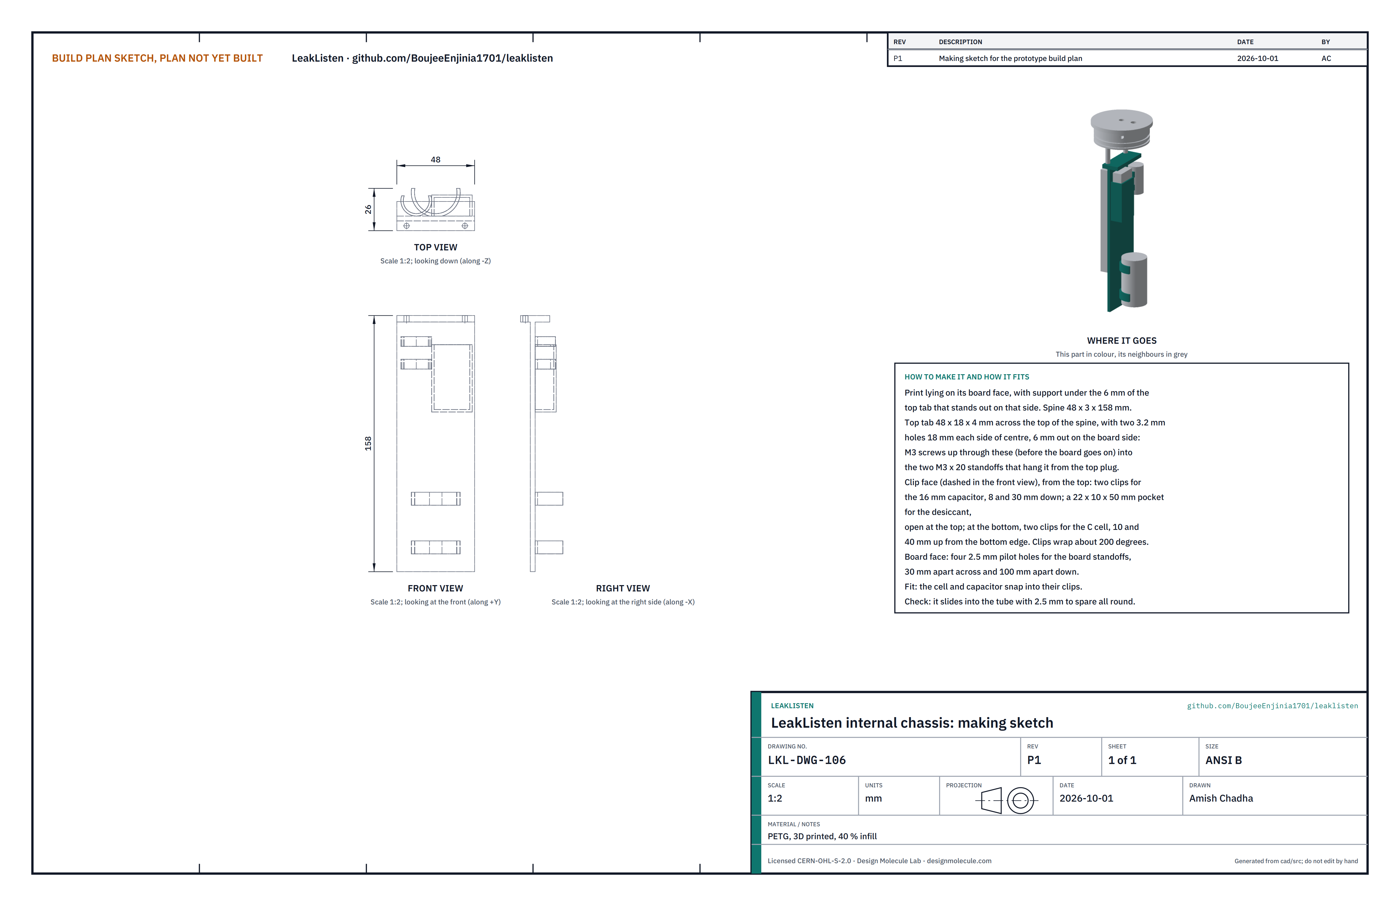
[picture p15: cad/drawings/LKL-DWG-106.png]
Figure 9. Making sketch of the internal frame


*Figure 9. Internal frame (chassis) making sketch (LKL-DWG-106).*

**What it is and what it is made from.** A printed spine that hangs from the top plug and carries the electronics. PETG, 40 % infill.

**How to make it.**

1. Print it lying on its board face, with support under the part of the top tab that stands out on that side. The spine is 48 mm wide, 3 mm thick and 158 mm long.
2. The top tab, 48 by 18 by 4 mm, has two 3.2 mm holes 18 mm each side of centre, 6 mm out on the board side.
3. On the other face (the clip face), from the top: two clips for the capacitor, 8 and 30 mm down; a 22 by 10 by 50 mm pocket for the desiccant, open at the top; and at the bottom two clips for the cell, 10 and 40 mm up. The clips wrap about 200° round their part.
4. On the board face, drill four 2.5 mm pilot holes for the board standoffs, 30 mm apart across and 100 mm apart down, matched to your board.

**How it fits the parts next to it.** Two M3 by 20 mm standoffs screw into the top plug's inner face; two M3 screws come up through the tab into them (step 7). The board sits on four short standoffs on the board face; the cell and capacitor snap into their clips and the desiccant drops into its pocket (step 8).

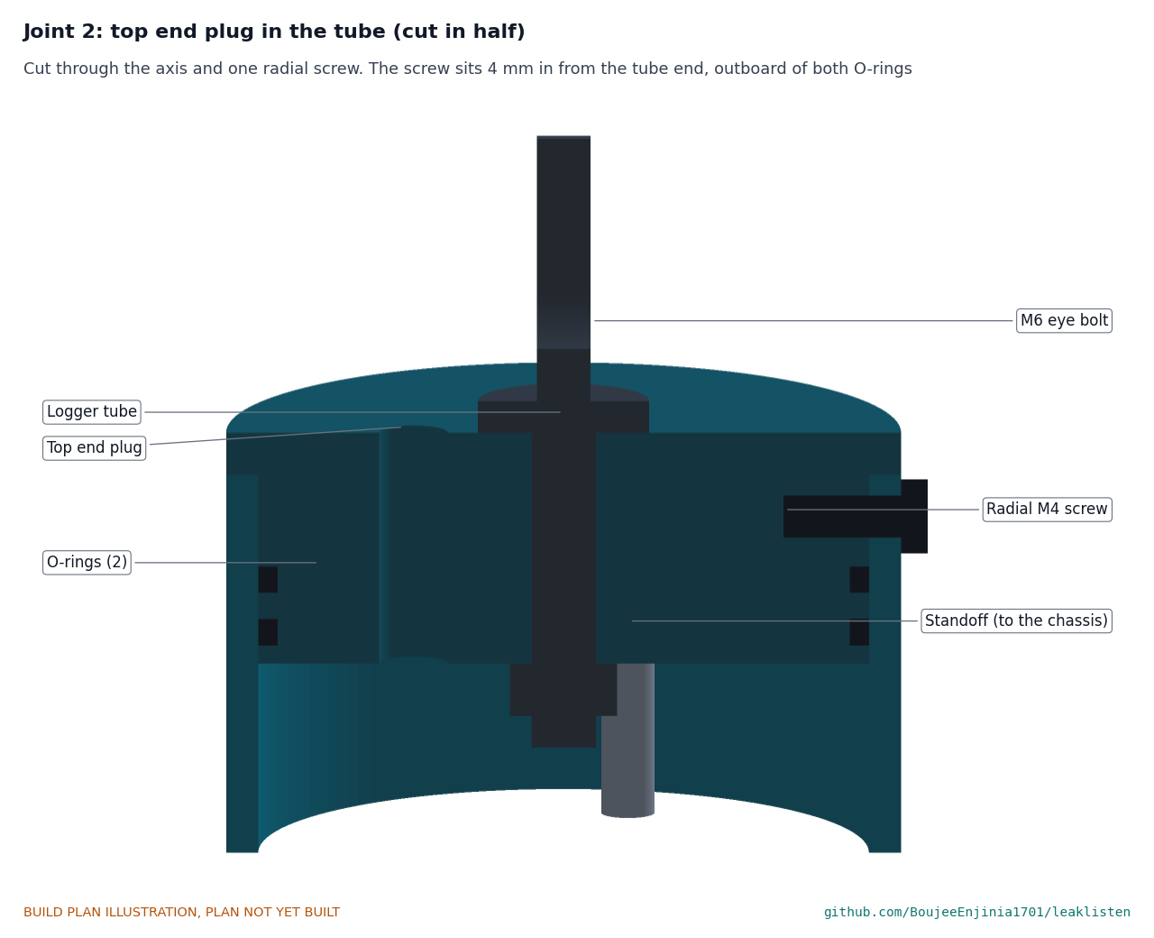
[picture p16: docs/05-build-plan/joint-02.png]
Figure 10. Joint 2: top end plug in the tube, cut in half


*Figure 10. Cut through the axis and one radial screw: the screw is 4 mm in from the tube end, outboard of both O-rings, so water stops at the O-rings; a standoff hangs the frame below the plug.*

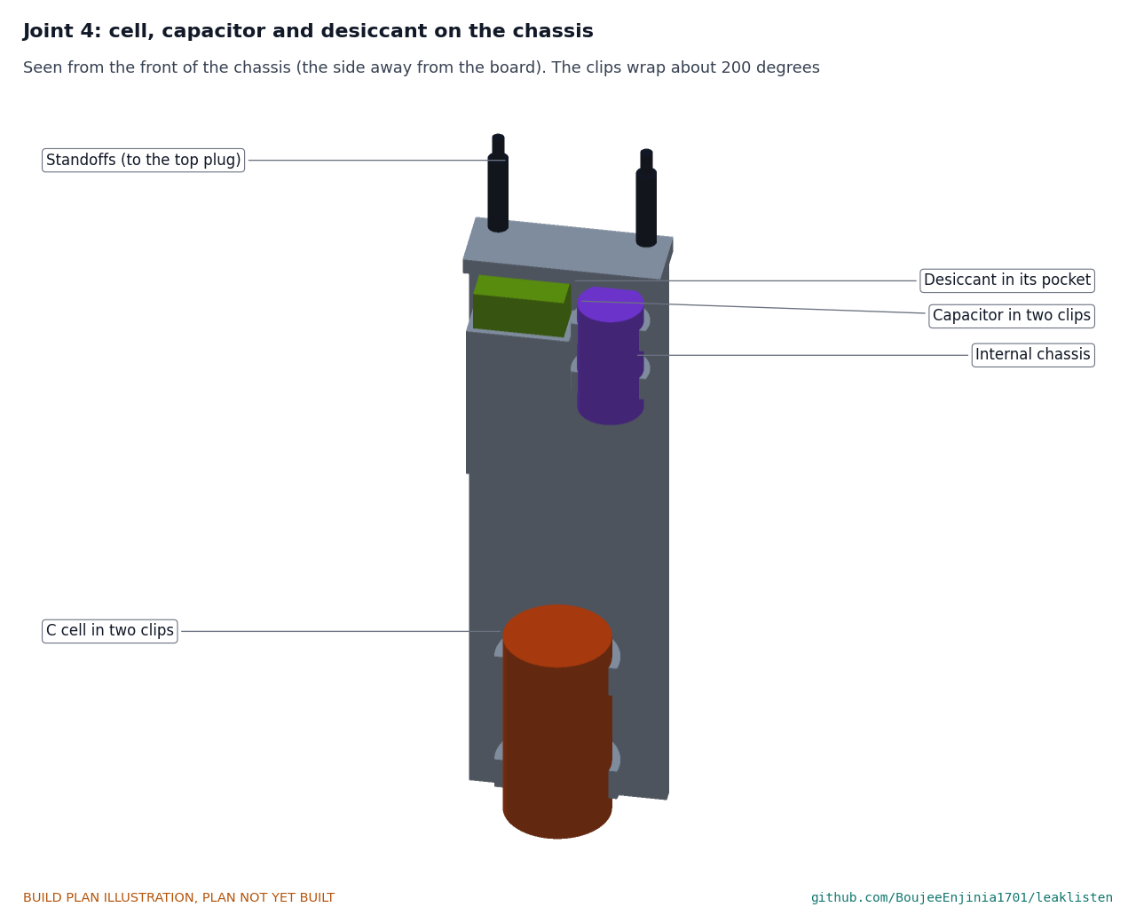
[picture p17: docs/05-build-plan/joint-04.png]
Figure 11. Joint 4: cell, capacitor and desiccant on the frame


*Figure 11. The clip face of the frame.*

**Check before moving on.** The frame slides into the tube with about 2.5 mm to spare all round; the cell snaps in and does not fall out when the frame is shaken.

### 3.8 Bought parts for the logger

- **Eye bolt.** M6 by 20 mm stainless eye bolt with a bonded sealing washer and a nyloc nut.
- **Status light pipe.** A 3 mm clear acrylic rod about 48 mm long with both ends cut square and polished. It is glued into its hole in the top plug with a drop of clear epoxy, flush with the top face, and its lower end stops 1.5 mm above the status light on the board's top edge. The light is lit only for a short blink at power-up or when the magnet is swiped over the logger.
- **Antenna connector.** IP67 SMA female bulkhead with its O-ring and nut, with a short pigtail to the board.
- **Panel socket.** M12 A-coded IP68 front-mount panel socket with an M16 x 1.5 thread, its O-ring and lock nut, and a short four-pin lead to the board.
- **O-rings.** Four nitrile O-rings of 2.5 mm section to suit the 57 mm spigot grooves, and silicone grease.
- **Main board.** STM32WL LoRaWAN module with a 24-bit audio converter, clock, fuse and reverse protection, about 38 by 110 mm, bought or built on a maker's carrier (no board is laid out at this stage).
- **Capacitor.** Hybrid layer capacitor of 0.1 F or more, 16 mm by 30 mm.
- **Cell.** Lithium thionyl chloride C cell, 3.6 V, about 7.7 Ah, with solder tabs, wired to a two-pin plug by the supplier or at stop point S2.
- **Desiccant.** 10 g silica gel pack.
- **Fixings.** Six M4 by 10 mm stainless pan-head screws; two M3 by 20 mm male-female standoffs; four M3 by 3 mm nylon standoffs; M3 screws.

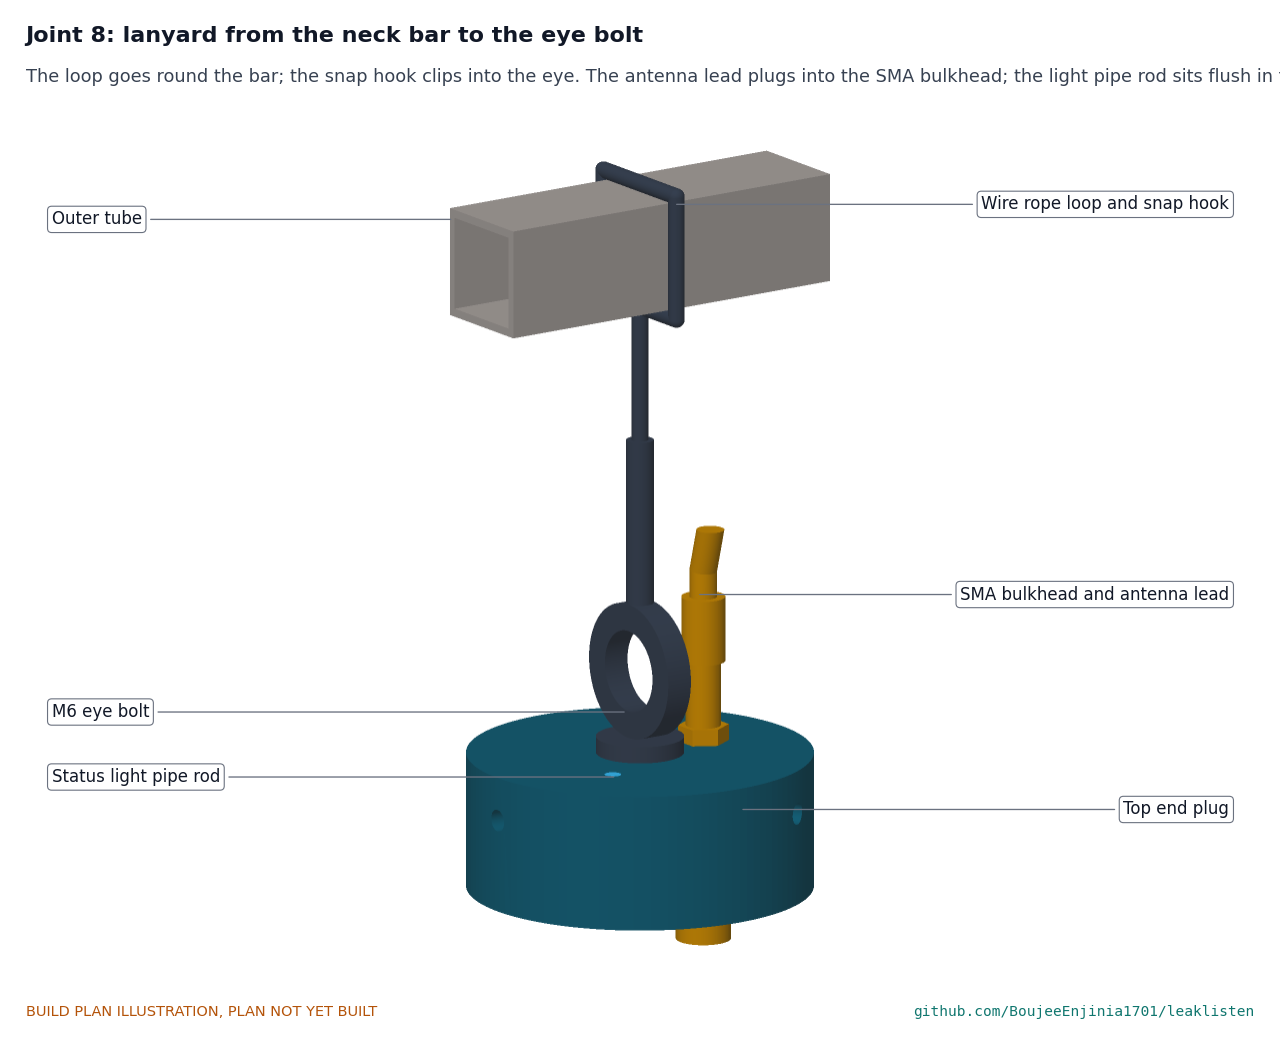
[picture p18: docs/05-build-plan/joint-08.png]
Figure 12. Joint 8: lanyard, eye bolt and antenna connector


*Figure 12. The lanyard's snap hook clips into the eye bolt; the antenna lead screws onto the connector beside it.*

#### 3.8.1 Wiring

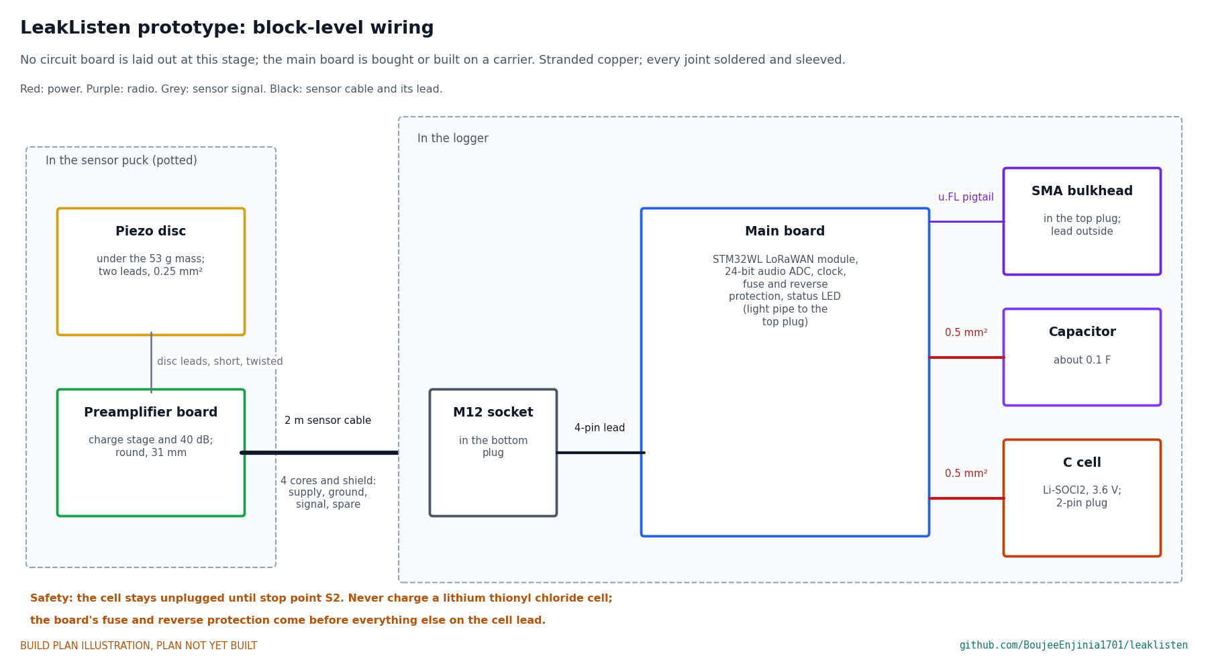
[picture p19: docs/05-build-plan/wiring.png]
Figure 13. Block-level wiring


*Figure 13. Block-level wiring. No circuit board is laid out at this stage.*

1. Piezo disc leads to the amplifier board's input: short, twisted, soldered before the board goes into the puck.
2. Sensor cable to the amplifier board: supply, ground, signal and spare cores; shield to ground at the board.
3. Panel socket to the main board: the short four-pin lead.
4. Antenna connector to the main board's radio: the pigtail, kept away from the power wires.
5. Capacitor to the main board: 0.5 mm² (20 AWG), short.
6. Cell to the main board through its two-pin plug: 0.5 mm²; the board's fuse and reverse protection are the first things on this lead.

**Check before moving on.** Every wire continues end to end; with the cell unplugged, the cell connector on the board reads open between its pins.

### 3.9 Neck bar outer tube

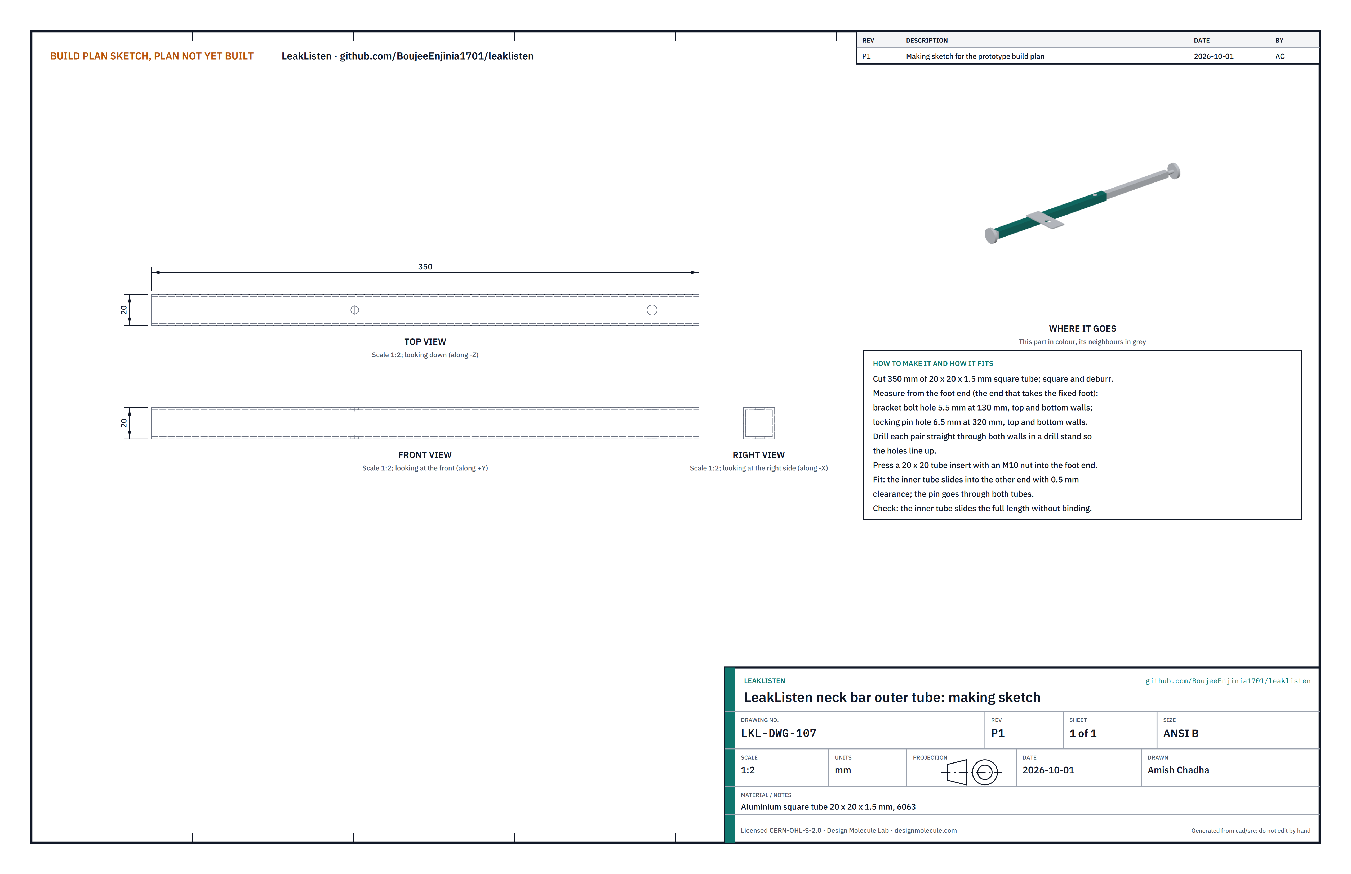
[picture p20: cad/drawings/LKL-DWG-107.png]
Figure 14. Making sketch of the outer tube


*Figure 14. Neck bar outer tube making sketch (LKL-DWG-107).*

**What it is and what it is made from.** The fixed half of the bar, which carries the antenna bracket and the lanyard. Aluminium square tube, 20 by 20 by 1.5 mm, 6063 class.

**How to make it.**

1. Cut 350 mm; square and deburr both ends.
2. Measuring from the end that takes the fixed foot: a 5.5 mm hole at 130 mm for the bracket bolt, and a 6.5 mm hole at 320 mm for the locking pin, each through the top and bottom walls. Drill each pair straight through in a drill stand.
3. Press a 20 mm square tube insert with an M10 nut into the fixed-foot end.

**How it fits the parts next to it.** The inner tube slides into the open end with 0.5 mm clearance each side; the pin passes through both tubes.

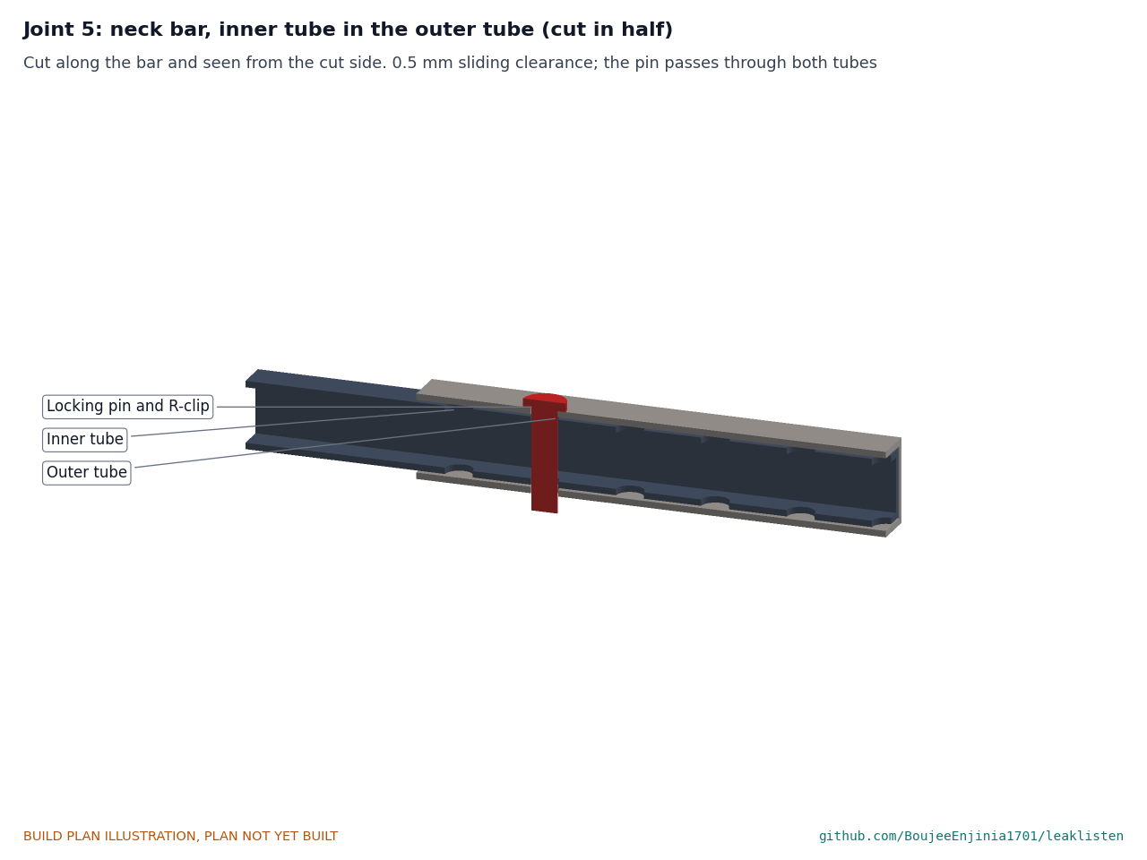
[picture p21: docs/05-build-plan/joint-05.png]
Figure 15. Joint 5: inner tube in the outer tube, cut in half


*Figure 15. The two tubes and the locking pin.*

**Check before moving on.** The inner tube slides the full length without binding.

### 3.10 Neck bar inner tube

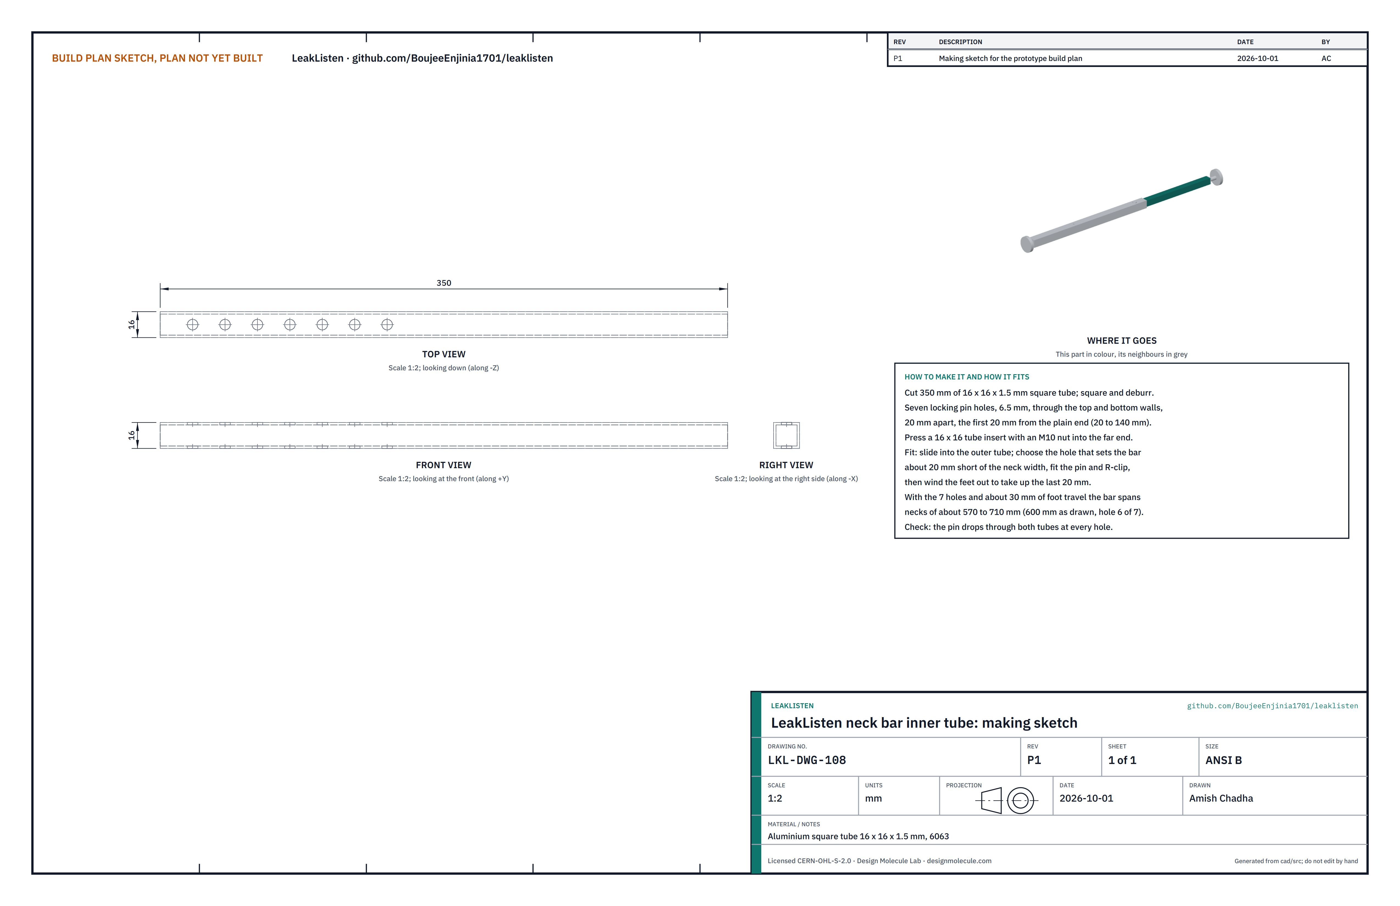
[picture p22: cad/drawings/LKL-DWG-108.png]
Figure 16. Making sketch of the inner tube


*Figure 16. Neck bar inner tube making sketch (LKL-DWG-108).*

**What it is and what it is made from.** The sliding half of the bar, which sets its length. Aluminium square tube, 16 by 16 by 1.5 mm, 6063 class.

**How to make it.**

1. Cut 350 mm; square and deburr.
2. Drill seven 6.5 mm holes through the top and bottom walls, 20 mm apart, from 20 to 140 mm from the plain end.
3. Press a 16 mm square tube insert with an M10 nut into the other end.

**How it fits the parts next to it.** Set the bar about 20 mm shorter than the neck with the pin in the right hole; the adjusting foot takes up the rest. With seven holes and about 30 mm of foot travel the bar spans necks of about 570 to 710 mm; the example chamber's 600 mm neck uses the sixth hole from the plain end.

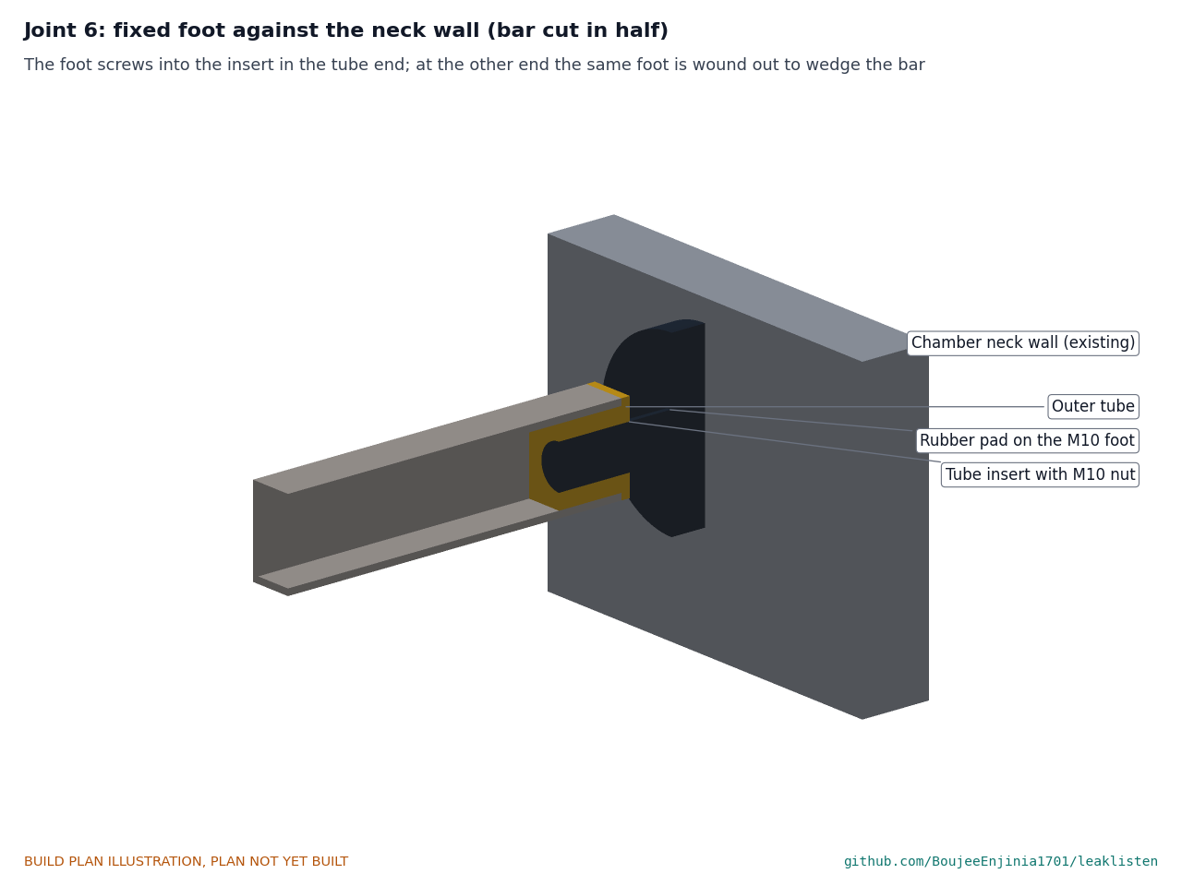
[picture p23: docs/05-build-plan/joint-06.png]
Figure 17. Joint 6: the fixed foot against the neck wall


*Figure 17. The rubber-padded foot screws into the insert in the tube end and bears on the neck wall; the foot at the other end is the same, wound out to wedge the bar.*

**Check before moving on.** The pin drops through both tubes at every hole.

### 3.11 Antenna bracket

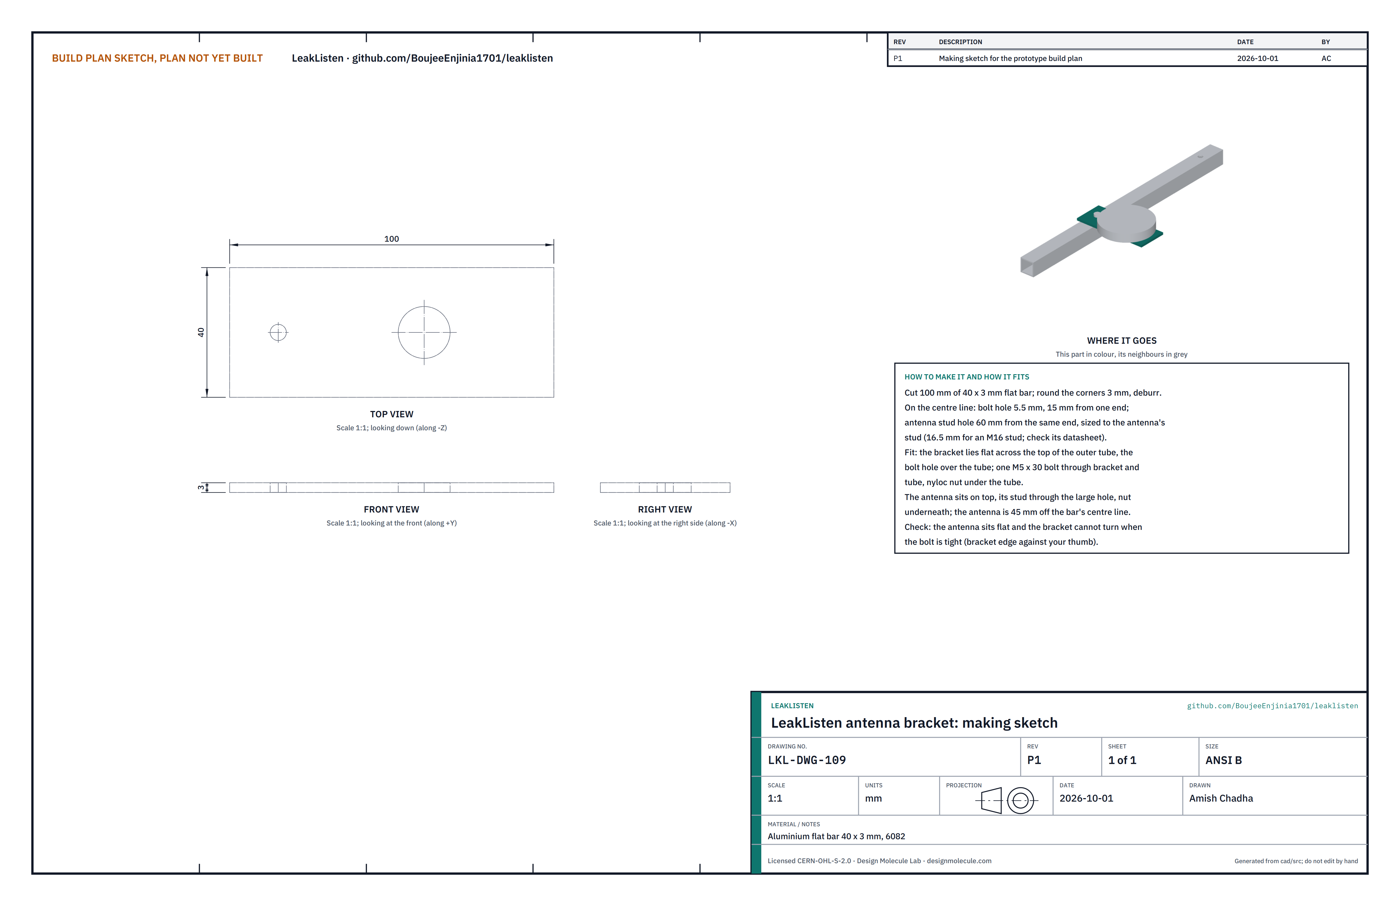
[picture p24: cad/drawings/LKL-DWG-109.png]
Figure 18. Making sketch of the antenna bracket


*Figure 18. Antenna bracket making sketch (LKL-DWG-109).*

**What it is and what it is made from.** A flat plate that holds the antenna on top of the bar. Aluminium flat bar, 40 by 3 mm, 6082 class.

**How to make it.**

1. Cut 100 mm; round the corners about 3 mm and deburr.
2. On the centre line, drill a 5.5 mm hole 15 mm from one end for the bolt, and a hole 60 mm from the same end to suit the antenna's centre stud (16.5 mm for an M16 stud; check the antenna's datasheet).

**How it fits the parts next to it.**

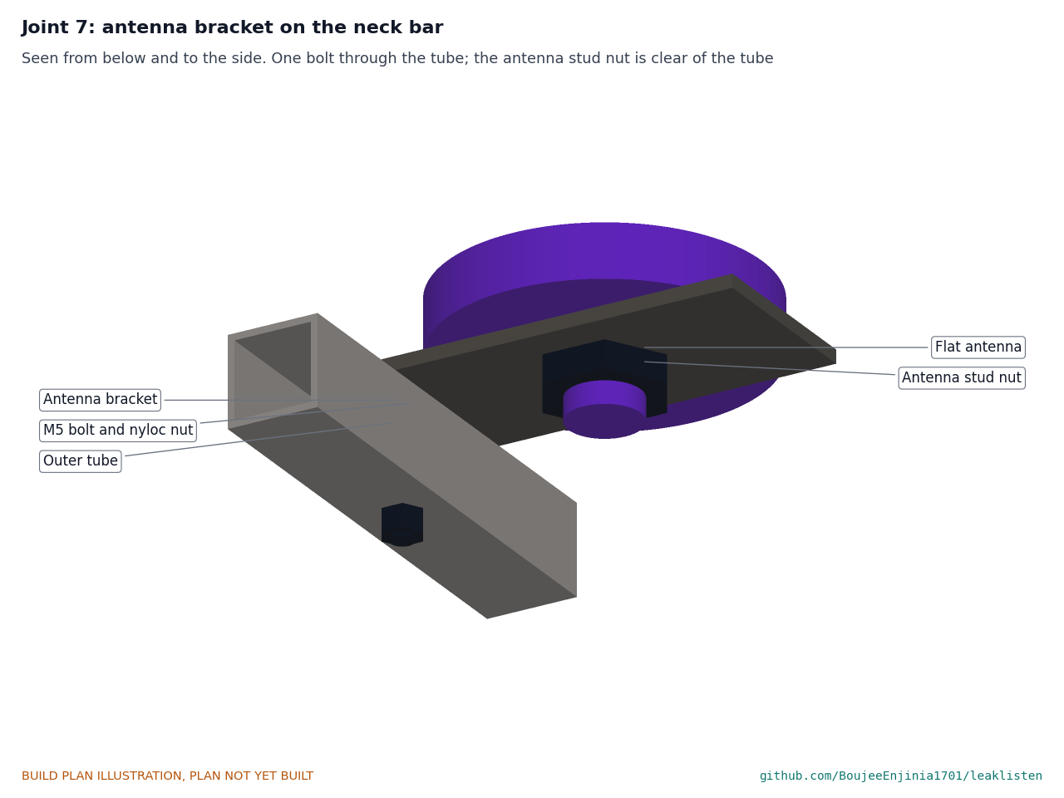
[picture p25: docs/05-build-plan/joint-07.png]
Figure 19. Joint 7: antenna bracket on the bar


*Figure 19. Seen from below: one M5 bolt through the bracket and the outer tube, nyloc nut under the tube; the antenna's stud nut sits under the bracket, clear of the tube.*

The bracket lies flat across the top of the outer tube with its bolt hole over the tube; the antenna's centre is 45 mm off the bar's centre line.

**Check before moving on.** With the bolt tight the bracket cannot be turned by hand.

### 3.12 Bought parts for the neck bar

- **Feet.** Two M10 levelling feet with 40 mm rubber pads and at least 40 mm of thread.
- **Tube inserts.** One 20 mm and one 16 mm square tube insert, each with an M10 nut, for 1.5 mm wall.
- **Locking pin.** 6 mm pin about 30 mm long with an R-clip.
- **Lanyard.** 3 mm stainless wire rope, about 150 mm, with a loop and ferrules at one end and a stainless snap hook at the other.
- **Antenna.** Flat puck antenna about 70 mm across for the regional LoRaWAN band, with a threaded centre stud and nut, and a 1 m low-loss lead ending in an SMA plug.
- **Fixings.** One M5 by 30 mm stainless bolt with a nyloc nut.

## 4. Putting it together

In each picture the parts already fitted are grey and the parts being fitted are in colour, with an arrow showing the way they go in.

### Step 1: piezo disc and seismic mass into the puck

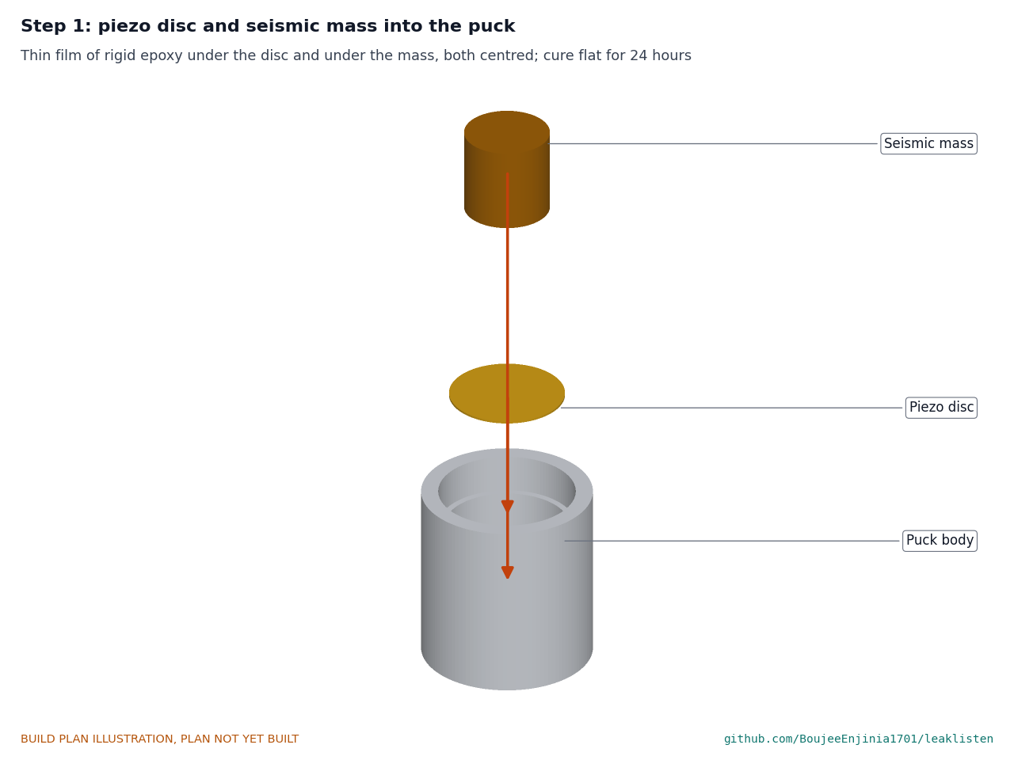
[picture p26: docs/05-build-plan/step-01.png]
Step 1


A thin film of rigid epoxy under the disc and another under the weight, both centred. Cure flat for 24 hours.

### Step 2: amplifier board and cable

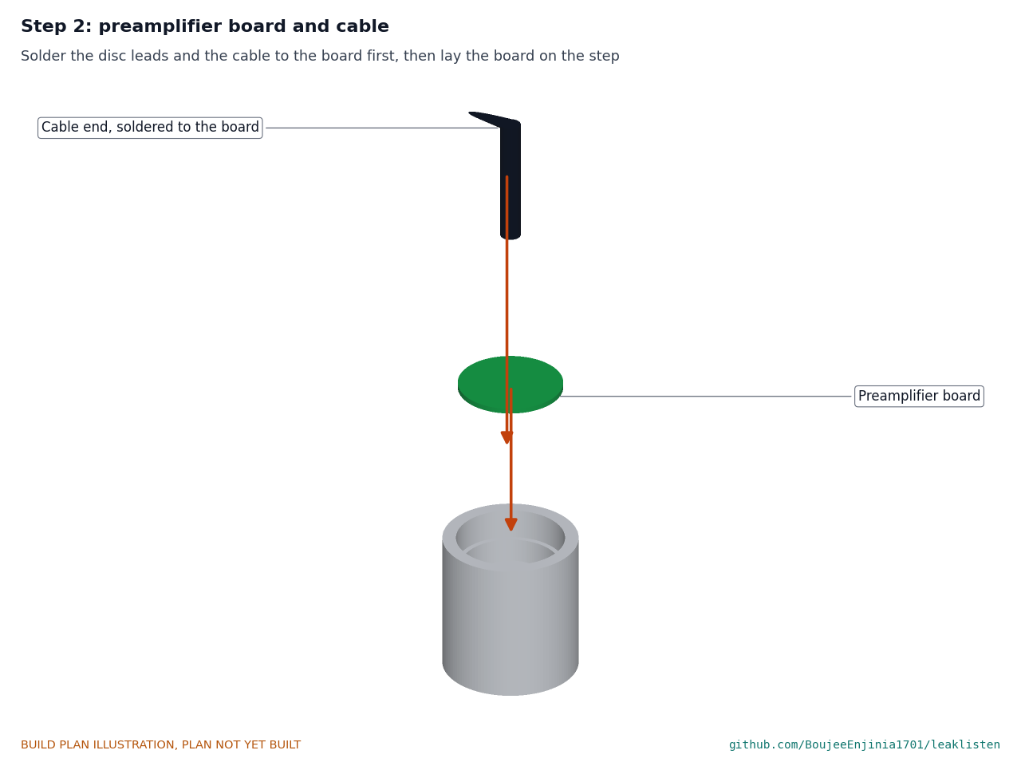
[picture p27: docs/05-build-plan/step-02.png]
Step 2


Pass the cable's bare end down through the puck's mouth and solder it and the disc leads to the board, then lay the board on the step. **Hold point:** the board sits flat on the step and the weight is free (look from the side with a lamp).

### Step 3: pot the top of the puck

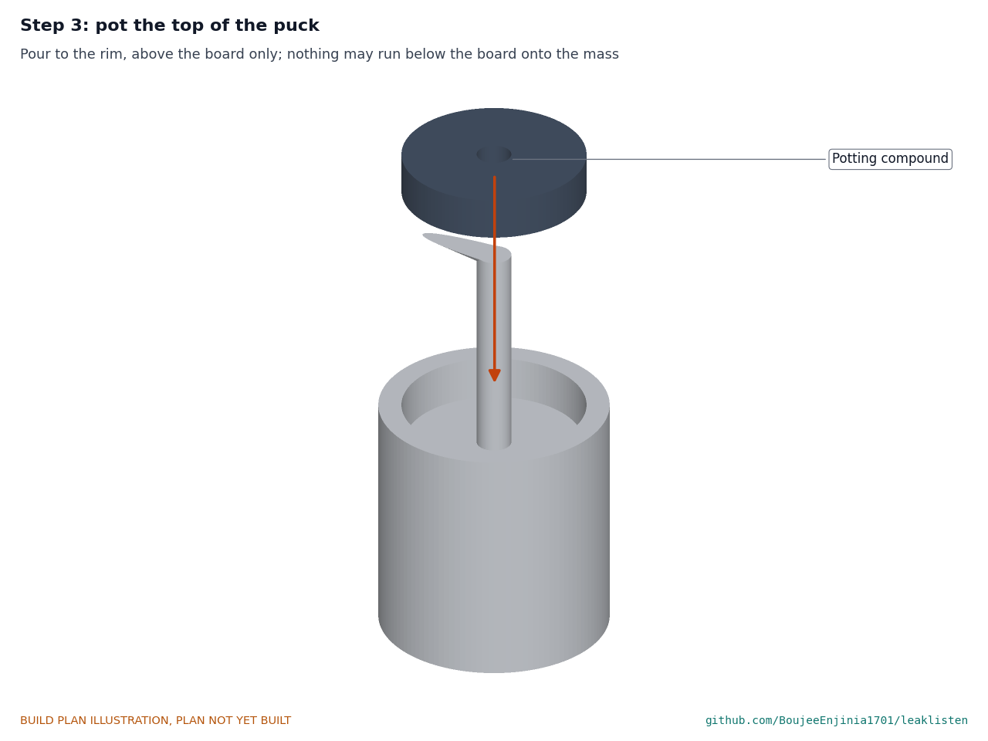
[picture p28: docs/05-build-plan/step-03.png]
Step 3


Pour potting compound to the rim, above the board only. Hold the cable upright until it sets.

### Step 4: pot magnet onto the puck

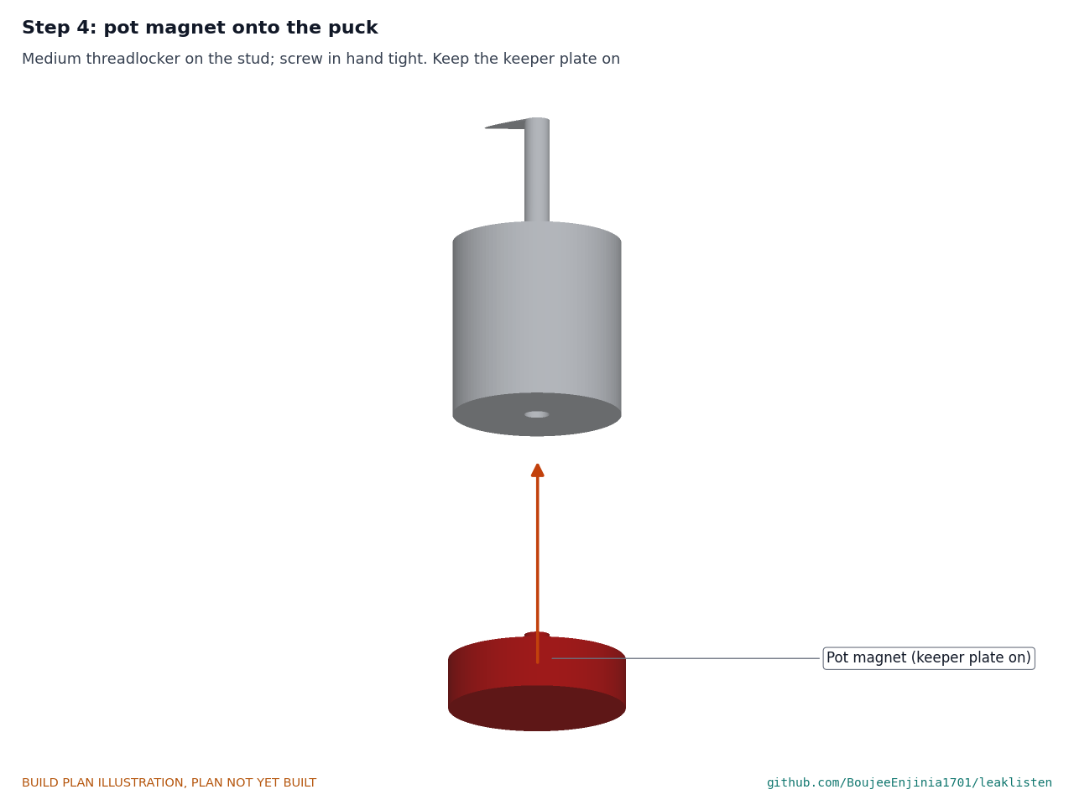
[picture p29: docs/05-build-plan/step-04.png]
Step 4


Medium threadlocker on the stud; screw the magnet into the base hand tight. Leave the keeper plate on.

### Step 5: fit the top end plug

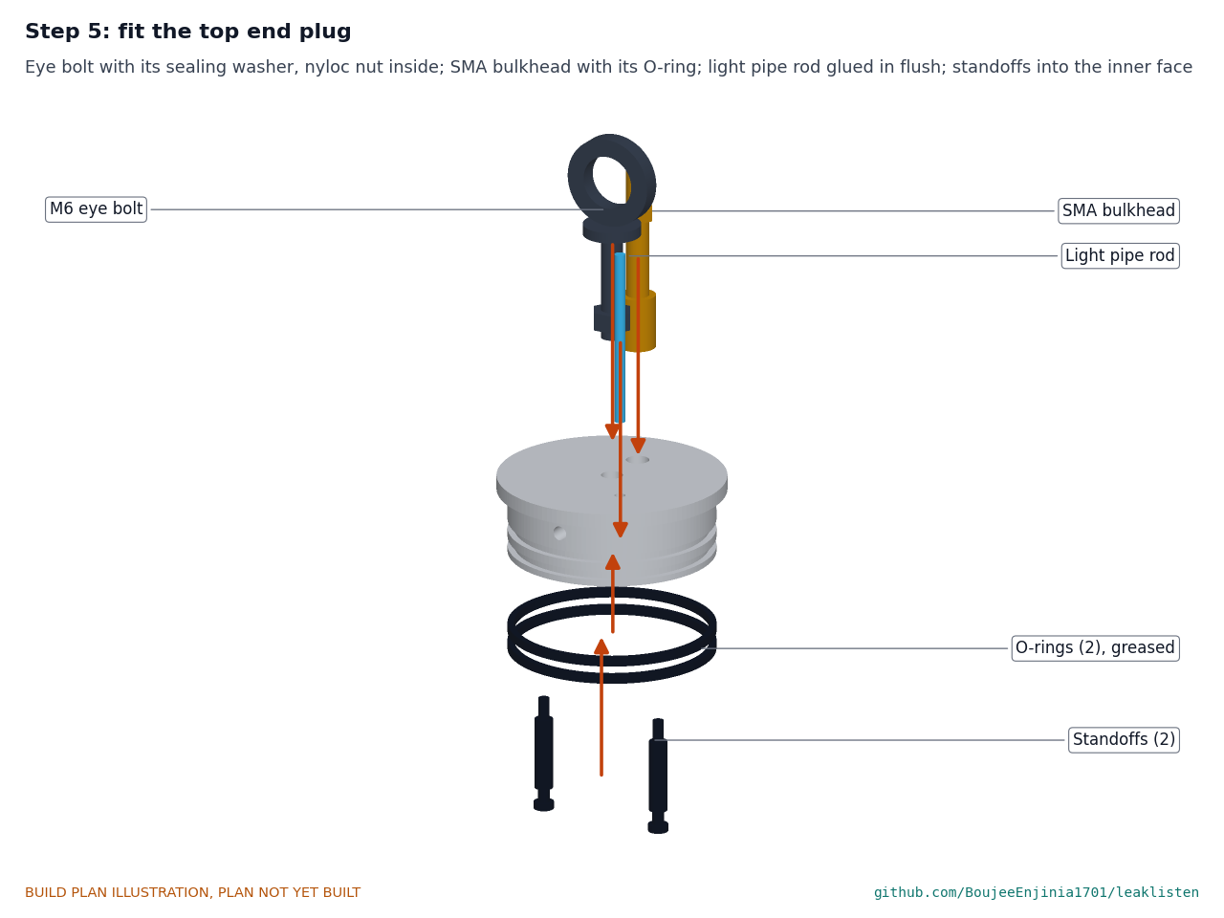
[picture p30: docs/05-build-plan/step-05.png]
Step 5


Eye bolt with its sealing washer outside and nyloc nut inside; antenna connector with its O-ring outside and nut inside; the light pipe rod glued into its hole, flush with the top face; the two standoffs into the inner face; greased O-rings into both grooves.

### Step 6: fit the bottom end plug

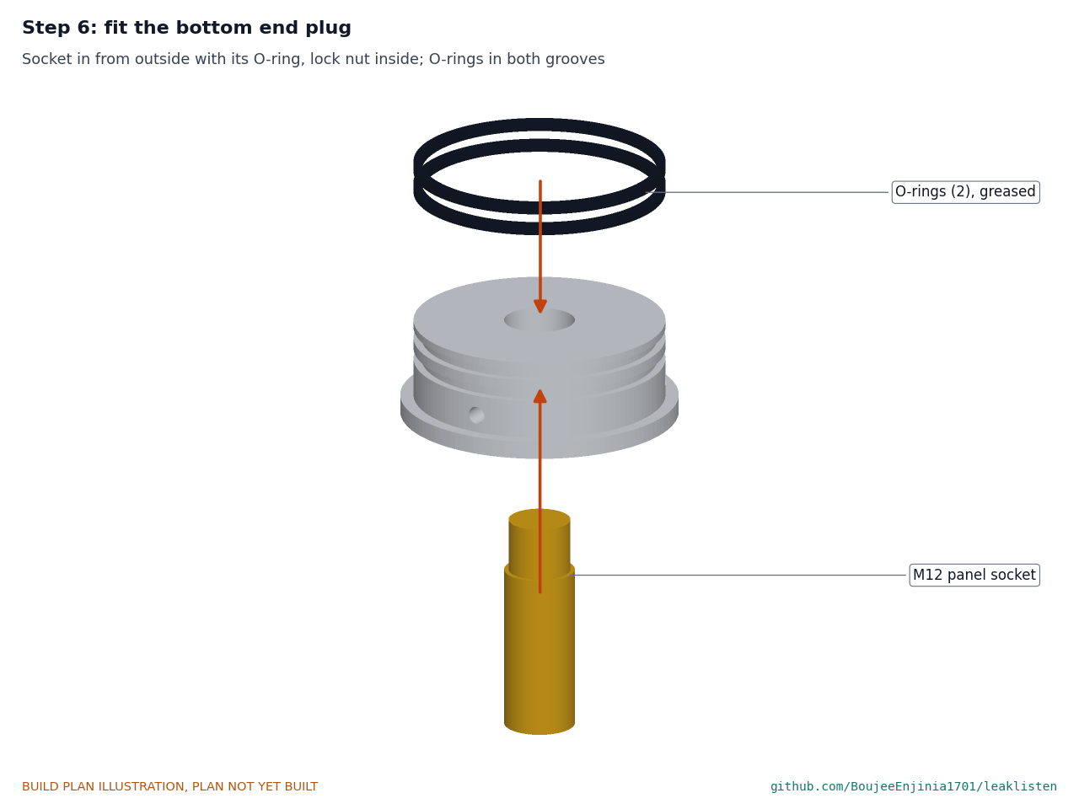
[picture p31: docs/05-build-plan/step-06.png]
Step 6


Socket in from outside with its O-ring, lock nut inside; greased O-rings into both grooves.

### Step 7: frame onto the top plug

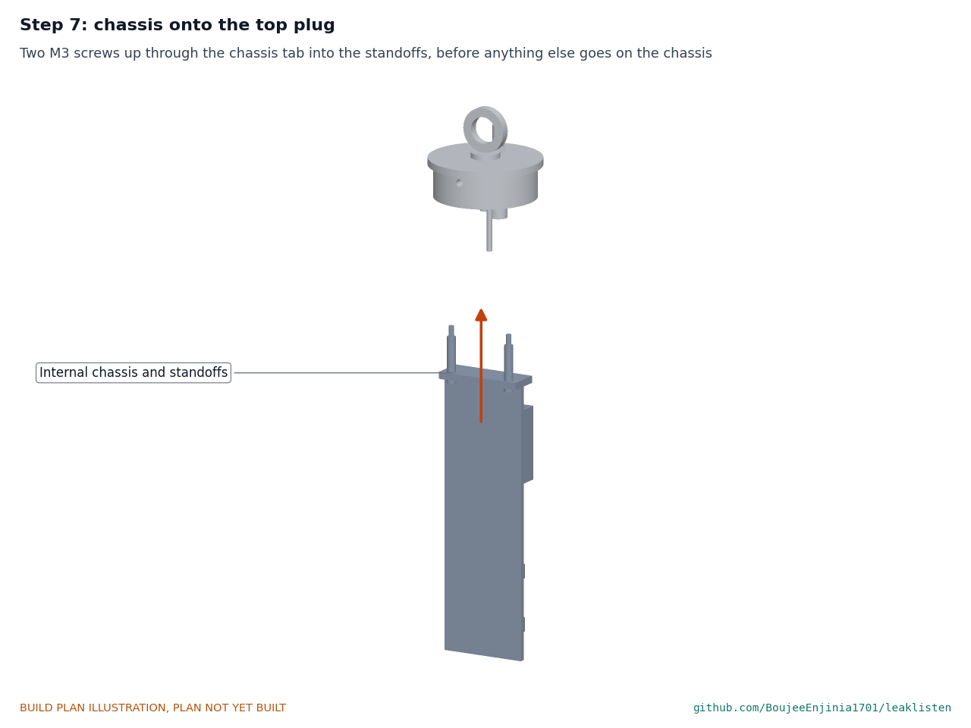
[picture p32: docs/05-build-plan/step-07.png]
Step 7


Two M3 screws up through the frame's tab into the standoffs, before anything else goes on the frame.

### Step 8: electronics onto the frame

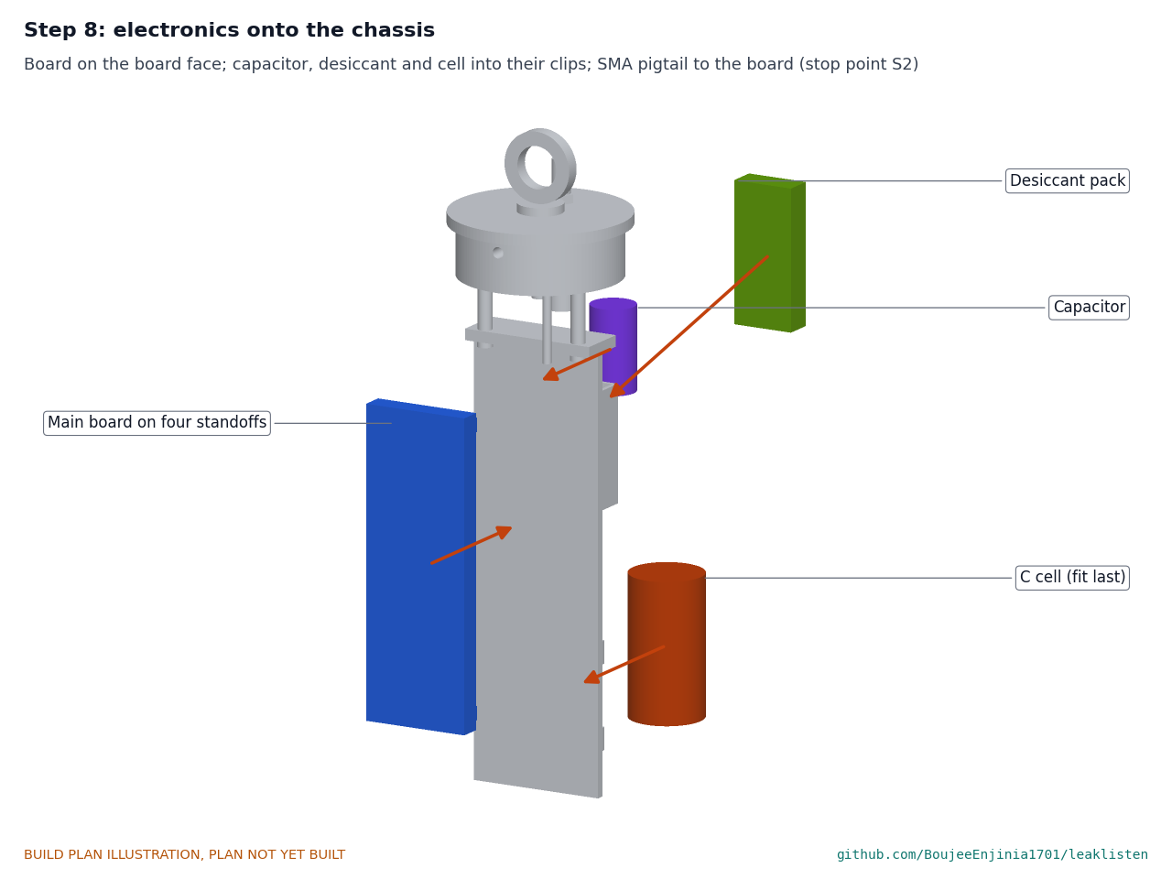
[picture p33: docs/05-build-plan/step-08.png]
Step 8


Board on its four standoffs on the board face; antenna pigtail to the board, with the status light 1.5 mm below the end of the light pipe; capacitor into its clips; desiccant into its pocket; the cell into its clips last, its plug left unplugged. **Hold point:** stop point S2 before the cell is plugged in.

### Step 9: bottom plug into the tube

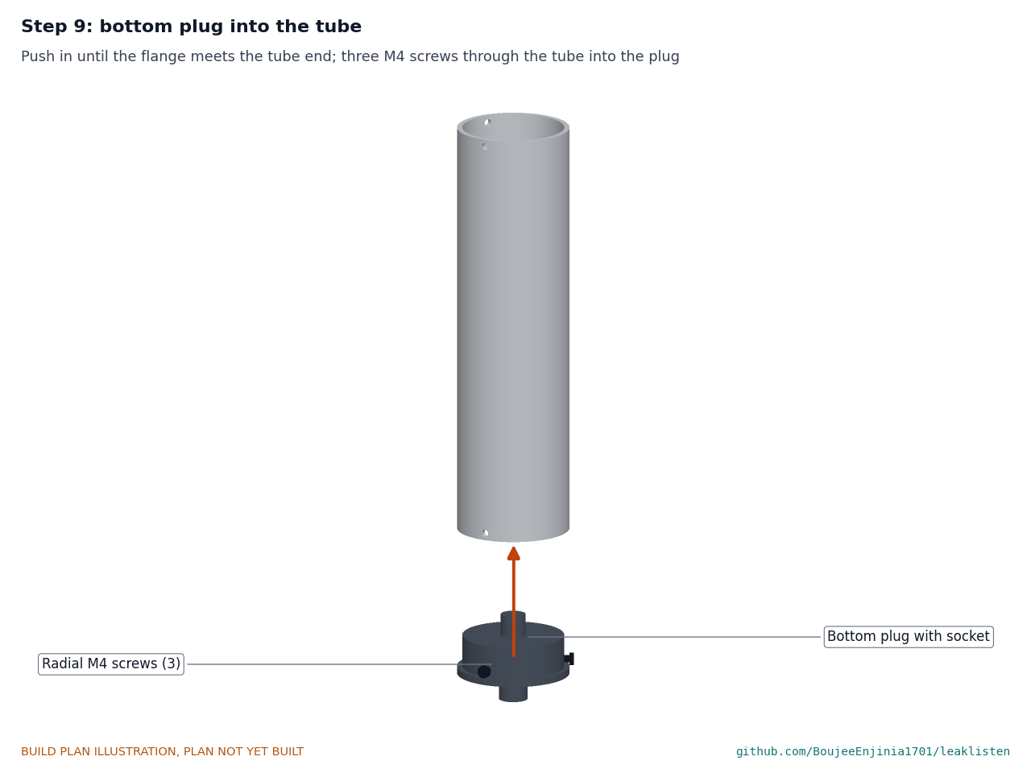
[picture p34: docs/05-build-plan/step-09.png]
Step 9


Push the plug in until its flange meets the tube end; three M4 screws through the tube into the plug.

### Step 10: close the logger

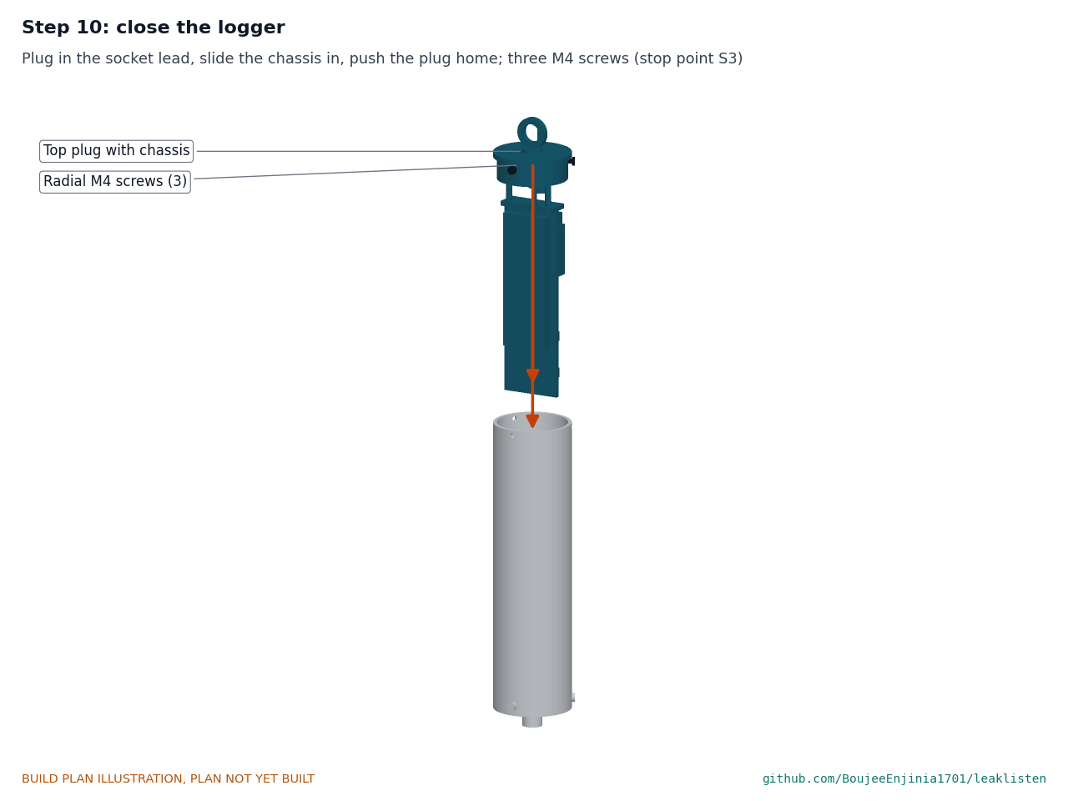
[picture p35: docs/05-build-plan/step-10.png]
Step 10


Plug the socket's lead into the board, slide the frame into the tube and push the top plug home; three M4 screws. **Hold point:** stop point S3.

### Step 11: assemble the neck bar

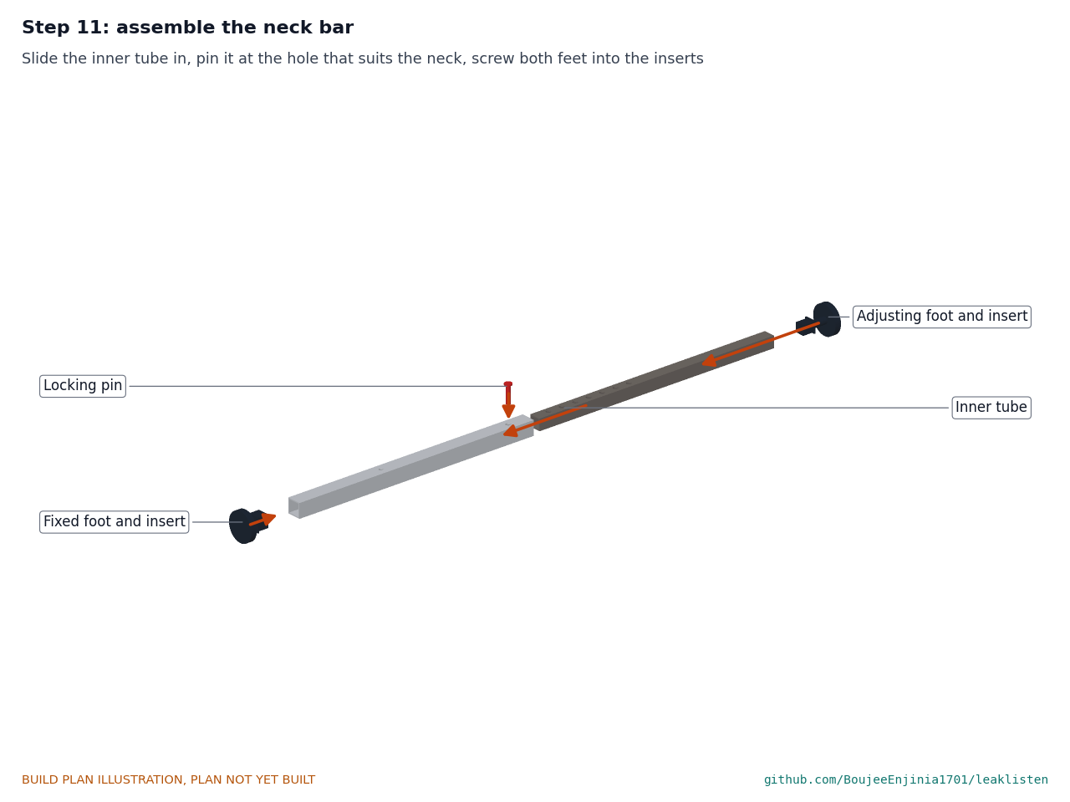
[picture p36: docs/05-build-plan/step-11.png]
Step 11


Slide the inner tube into the outer, pin it at the hole that suits the neck, and screw a foot into each insert, the fixed foot fully home.

### Step 12: antenna bracket and antenna onto the bar

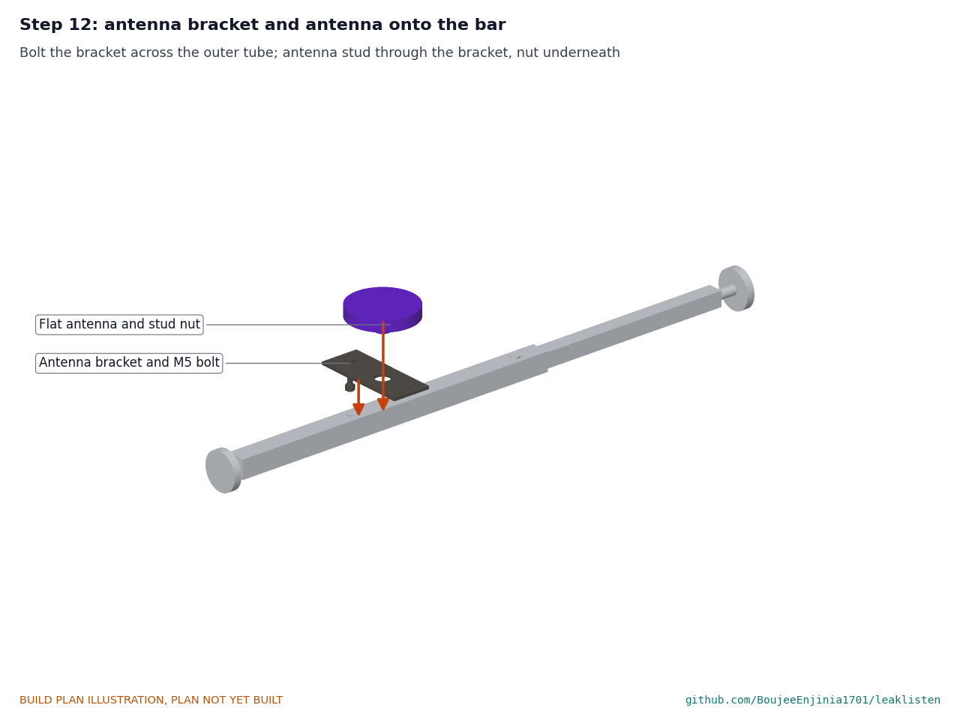
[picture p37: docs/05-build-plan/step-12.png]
Step 12


Bolt the bracket across the outer tube; put the antenna's stud through the bracket and fit its nut underneath.

### Step 13: hang the logger and connect the antenna

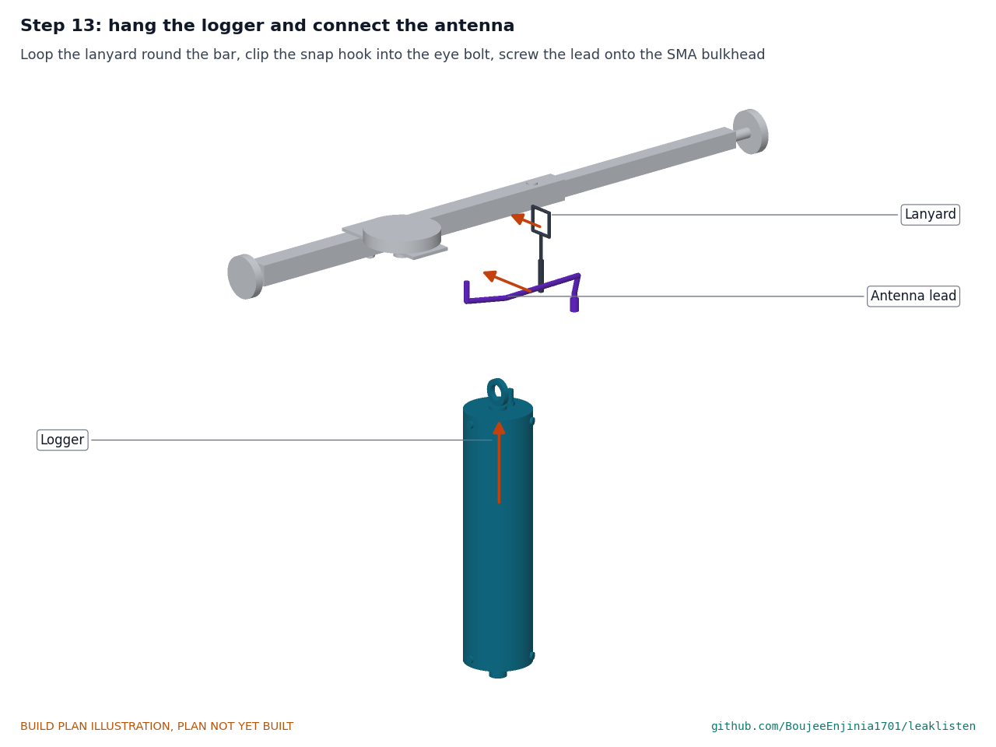
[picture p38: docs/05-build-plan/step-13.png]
Step 13


Loop the lanyard round the outer tube beside the bracket, clip the snap hook into the eye bolt, and screw the antenna lead onto the connector. Coil the spare lead and tie it to the lanyard.

### Step 14: set the bar in the chamber neck

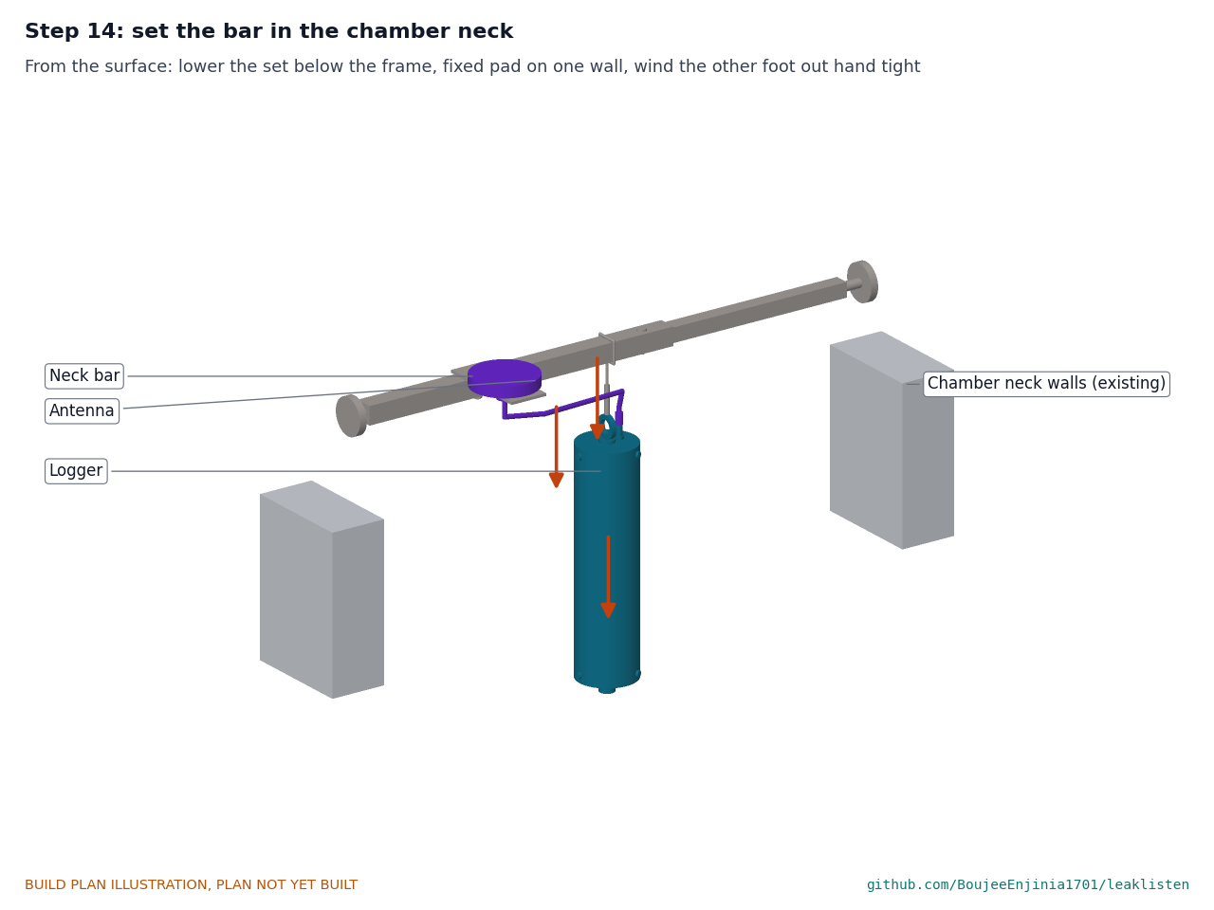
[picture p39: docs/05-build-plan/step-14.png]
Step 14


For the prototype, use a bench frame with two walls 600 mm apart. From above, lower the set until the bar is below the frame, put the fixed pad against one wall and wind the other foot out by hand until the bar does not move when pushed. **Hold point:** stop point S5.

### Step 15: sensor puck onto the spindle cap

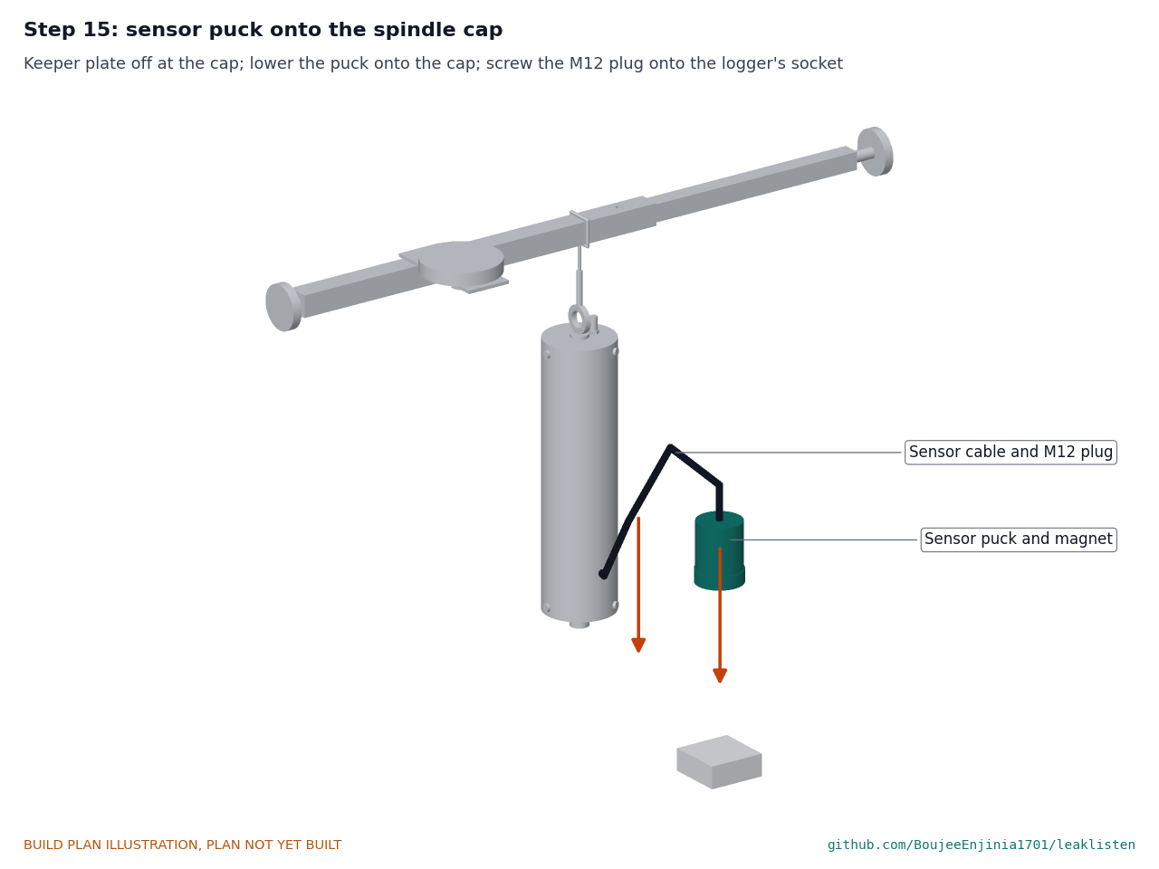
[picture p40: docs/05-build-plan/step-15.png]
Step 15


Take the keeper plate off only at the cap; lower the puck by its cable (or on a placing pole) until the magnet takes hold; screw the cable's plug onto the logger's socket.

## 5. First checks

These are the checks a TRL 4 test report would record; this plan only lists them. Requirement numbers are those of LKL-REQ-001.

*Table 2. First checks.*

| Check | Requirement | How | Pass when |
| --- | --- | --- | --- |
| Logger seals | R11 | Logger closed with no electronics, submerged under 1 m of water for 1 hour, then opened | No water inside; a paper tissue in the tube stays dry |
| Weight stands free | R3, R4 | Look into the puck from the side with a lamp before potting | Light all round the weight; nothing touches it but the disc |
| Sensor responds | R4 | Puck on a steel block on the bench; tap the block lightly; read the amplifier output on an oscilloscope | A clean response that dies away; no output when the block is still |
| Magnet hold | R9 | Spring balance hooked to the puck on a painted steel cap | 100 N or more before it lets go |
| Cell and supply | R6 | Cell plugged in; measure current in sleep and while listening | Near the 4 µA and 12 mA of LKL-CAL-001 |
| Radio | R7, R14 | Logger and antenna on the bar under a steel plate in place of the cover; one uplink to a nearby gateway | The 24-byte summary is received |
| Bar holds | R10 | Bar set in a 600 mm bench frame; logger hung; push and pull on the logger | The bar does not move; the pads do not slip |
| Size and mass | R12 | Measure and weigh the logger, cable and puck, then the bar | 70 mm or less across, 300 mm or less long; logger, cable and puck 1.0 kg or less; record the bar's mass |
| Install time | R10 | Time steps 14 and 15 at the bench frame | Recorded against the 10 min target |

## 6. Safety stops

Stop at each point. Carry on only when everything listed is true.

- **S1. Before the cell comes into the workshop.** The cell is in its packaging, undamaged, with its maker's datasheet; it is stored away from metal and heat. A non-combustible surface (a ceramic tile or steel tray) and a fire extinguisher for electrical fires are within reach of the bench.
- **S2. Before the cell is plugged in.** The board's fuse and reverse protection are fitted and checked with a meter; the cell plug's polarity matches the board, checked with a meter, not by wire colour; no charging circuit of any kind is connected. The cell has never been soldered near its body.
- **S3. Before the logger is closed.** The cell is plugged in only if the bench check of its current has been done; every wire is clear of the O-rings; a fresh desiccant pack is in its pocket.
- **S4. Before the magnet's keeper plate comes off.** The puck is at the cap or on a steel block; hands are clear of the gap; nobody with a pacemaker or implant is close.
- **S5. Before any trial in a real chamber (outside this plan).** The utility's written permission; the cover lifted with a lifting key by two people; traffic management in place; nobody enters the chamber, and nobody leans into the opening without the utility's gas test and confined space rules.

## 7. Tools, skills and workspace

**Tools.** Lathe with a boring bar (or a machining service) for the puck body, the brass weight and the two end plugs; hacksaw and mitre box; bench drill or a drill in a stand; drills 2.5 to 16.5 mm; M3, M4, M6 and M16 x 1.5 taps with their drills; deburring tool; files; calipers, steel rule and square; 3D printer that prints PETG; soldering iron; wire strippers; multimeter; oscilloscope (for the first checks); spring balance to 200 N; scale to 2 kg; stopwatch.

**Skills.** No certified trade is needed. Basic turning, drilling and tapping; through-hole and fine-wire soldering; mixing and pouring two-part potting and epoxy; care with lithium primary cells and strong magnets. All circuits are extra-low voltage, 3.6 V at the cell; no mains wiring is part of this build.

**Workspace.** A bench about 1.2 by 0.6 m; a turning and drilling corner kept apart from the electronics so chips stay off the boards; a ventilated place for potting and printing; the cell area of S1; a bench frame with two solid walls 600 mm apart for steps 14 and 15.

**Personal protective equipment.** Safety glasses for turning, drilling, cutting and soldering; nitrile gloves for epoxy and potting; no gloves near a turning lathe or drill.

## 8. Where the numbers come from

- Model and constructability checks: `cad/src/model.py` (`python cad/src/model.py --check`); STEP and STL exports in `cad/step/` and `cad/stl/`.
- Pictures: `cad/src/build_plan_media.py`, using `.kit/build_views.py`; written to `docs/05-build-plan/` and `cad/drawings/LKL-DWG-101` to `LKL-DWG-109`.
- General arrangement: `cad/drawings/LKL-DWG-001.pdf`, Rev P5.
- Calculations: `docs/04-calcs/01-sizing.md` (LKL-CAL-001 v0.3) and `docs/04-calcs/sizing.py`; mass [K1], cable reach [K2], install time [K3], flooding [J2], resonance [F6].
- Bill of materials: `bom/bom.csv`.
- Decisions: `docs/decisions/0003-design-for-construction.md` (LKL-DDR-003), with LKL-DDR-001 and LKL-DDR-002; open items in `docs/06-design-decisions.md` (LKL-DEC-001).
- Requirements: `docs/03-requirements.md` (LKL-REQ-001 v0.5).

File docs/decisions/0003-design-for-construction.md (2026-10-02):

---
doc_id: LKL-DDR-003
title: LeakListen design for construction
project: LeakListen
doc_type: Design decision record
version: "0.2"
status: Draft
date: '2026-10-02'
author: Amish Chadha
license: CERN-OHL-S-2.0
revisions:
- version: "0.1"
  date: '2026-10-01'
  author: Amish Chadha
  change: Changes that make the concept physically buildable, with the reason for each; made under Amish's 2026-09-30 instruction to make the design physically buildable; open for his review
- version: "0.2"
  date: '2026-10-02'
  author: Amish Chadha
  change: "Accepted by Amish on 2026-10-02 (Tables 1 to 3); record stays Draft"
---

# 0003: Design for construction

- **Date:** 2026-10-01
- **Status:** accepted. Every change in Table 1 was made under Amish's 2026-09-30 instruction to make the design physically buildable. Amish, 2026-10-02: "i approve your recommendations for all 555 open decisions." This covers every change in Tables 1 and 2 and the recommendations in Table 3 (A1 and A2), recorded in the design decisions register (LKL-DEC-001, items 1 to 3). The record stays Draft.

## Context

On 2026-09-30 Amish asked for a build plan that shows how each component is made and how it fits the next, with pictures, and wrote: "If you are realising that the design cannot be built as per concept - fix the design assumptions to match and be physically feasible as you draw the illustrations." The concept model of LKL-DDR-002 showed what LeakListen does, but several of its parts could not be made or fixed as drawn. Checking the model with build123d (overlaps, contacts, clearances and assembly order) found the nine problems below. An earlier note in `docs/REVIEW.md` (2026-09-26) had already flagged one of them: the hanger plate overlapped the antenna by about 10 mm.

The changes keep what LeakListen does: a magnet-on piezo sensor on the valve spindle cap, a sealed logger in the chamber neck, a flat antenna just under the cover, one C-size primary cell, placement from the surface with no chamber entry, and the same electronics, radio and data. Nothing here changes the pitch or the safety case; one change (P1) removes a hazard the concept had. Every change is in `cad/src/model.py`, which now runs 72 constructability checks (`python cad/src/model.py --check`): parts that must touch do touch, and parts that must not touch are apart by at least the stated clearance. All 72 pass.

## Decision

*Table 1. Changes made to the model, the BOM and the calculations.*

| # | Problem in the concept | Change made | Why this way |
| --- | --- | --- | --- |
| P1 | The hanger was a 1.5 mm stainless strap "hooked over the cover frame". The hook had nothing to hook over: the cover sits on the frame's seat, so a strap there lies under the cover, which then rocks under traffic. As modelled, the hook overlapped the frame and was held by nothing. | A telescopic neck bar: a 20 x 20 x 1.5 mm aluminium square tube with a 16 x 16 x 1.5 mm tube sliding inside it, a rubber-padded M10 levelling foot screwed into a tube insert at each end, and a 6 mm locking pin through both tubes. It is wedged across the chamber neck 85 mm below the street (below the frame) by winding one foot out by hand. The logger hangs from it on a 3 mm wire rope lanyard with a loop round the bar and a snap hook. | Leaves the cover and frame untouched and seated, needs no drilling of the utility's asset, and is still placed from the surface. Spreader bars of this kind are a common way of hanging instruments in manholes. Seven pin holes at 20 mm and about 30 mm of foot travel cover necks of about 570 to 710 mm. |
| P2 | The hanger plate overlapped the flat antenna by about 10 mm, and the antenna had no fixing. | A 40 x 3 mm aluminium bracket, 100 mm long, lies across the top of the outer tube on one M5 bolt; the antenna's centre stud passes through it with a nut underneath. The antenna centre is 45 mm off the bar line and its top is 20 mm under the cover (8 mm in the concept). | Nothing overlaps, and the antenna is held by the stud it is bought with. 12 mm further from the cover is small beside the 10 to 30 dB assumed for the cover itself (LKL-CAL-001, section D). |
| P3 | The logger's end plugs were drawn fused into the tube, with no way to retain them. | Two flanged end plugs turned from 65 mm acetal bar: a 63 mm flange 4 mm thick on the tube end and a 57 mm spigot 18 mm long inside, with two O-ring grooves. Each is held by three M4 screws through the tube wall into the spigot, 4 mm from the tube end, outboard of both O-rings. The PVC tube is cut to 232 mm so the logger stays 240 mm flange to flange. | A push-in plug with double O-rings is the usual way to seal a tube for 1 m submersion (R11); the screws stop it working out and never cross the seal. |
| P4 | One "antenna and lanyard gland" on the top plug. A lanyard cannot pass through a cable gland, and the antenna lead ends in a connector that a gland cannot seal round. | An M6 stainless eye bolt on the axis of the top plug, with a bonded sealing washer and nyloc nut, takes the lanyard; an IP67 SMA bulkhead with its O-ring, 14 mm off the axis, takes the antenna lead. New BOM line 13. | Each fitting does one job and seals on its own washer or O-ring. The lanyard load now goes into the plug, not into the antenna lead. |
| P5 | The board, capacitor, cell and desiccant floated inside the tube with no fixing. | A printed PETG chassis: a 48 x 3 x 158 mm spine with a top tab, hung from the top plug on two M3 x 20 standoffs. The board is on four short standoffs on one face; the cell and capacitor snap into clips and the desiccant sits in a pocket on the other face. New BOM line 12. | The electronics are fixed, lift out with the top plug as one unit, and clear the tube bore by 0.8 mm or more. |
| P6 | The M12 socket was drawn as a cylinder on the bottom of the tube with no way to mount it. | A front-mount M12 panel socket screwed into an M16 x 1.5 thread through the bottom plug, sealed by its own O-ring, with a short 4-pin lead to the board. | Uses the socket's standard panel mounting. |
| P7 | The puck had a 3 mm base, too thin to take the pot magnet's M6 stud, so the magnet had no fixing. | Base 8 mm thick, tapped M6 for 6 mm of full thread; the magnet's stud is cut to 6 mm and fitted with threadlocker. | The stud now holds the magnet to the puck and the base stays solid under the piezo disc. |
| P8 | The preamplifier board floated 6 mm above the seismic mass, and "potted" left open whether potting would fill round the mass. | The puck bore is stepped: 29 mm below, 32 mm above, the step 25 mm above the base. A round 31 mm preamplifier board sits on the step, 4.5 mm above the mass, and potting fills only the space above the board. | The mass must stand free: potting round it would add damping and stiffness and change the sensitivity of LKL-CAL-001 [F1]. The step locates the board without tools. |
| P9 | The sensor cable ran straight into the potted lid with no defined exit, and the logger hung from the old hanger at 90 mm below the street. | The cable leaves through the potting on the puck axis; the logger now hangs with its top 180 mm below the street, clear of the bar by 70 mm, and the M12 plug sits 480 mm below the street. | Follows from P1: the lanyard and snap hook need about 70 mm under the bar. The 2 m cable still reaches caps 2.18 m deep [K2]. |

*Table 2. Knock-on changes.*

| Item | Change | Reason |
| --- | --- | --- |
| Mass | 1.35 kg in all with the neck bar and antenna (0.98 kg in the concept) [K1]. The logger, cable and sensor are 0.96 kg; the neck bar with its feet and lanyard is 0.32 kg. R12 (1.0 kg in all) is now not met; see A1. | The neck bar replaces a 0.05 kg strap; the flanged plugs, chassis and fittings add about 0.1 kg. |
| Cost | BOM lines 1, 6 and 9 repriced and lines 12 and 13 added. Value-engineering target: USD 130. Estimated cost of the constructable design: USD 141 (USD 11 over the target) [M1]. | Parts added for construction; the neck bar (USD 18) is the largest change. |
| Size | 63 mm diameter (68 mm over the radial screw heads), 240 mm flange to flange, 283 mm with the socket and eye bolt. R12's 70 x 300 mm still holds. | Flanges, socket and eye bolt. |
| Sensor | Puck and magnet 277 g (262 g); mounted resonance 676 to 1,352 Hz (695 to 1,389 Hz). R3 stays at risk, slightly worse. | Thicker base (P7). |
| Flooding | The logger body is 551 g against 748 g of water displaced; it still floats on its lanyard when the chamber floods, now with 1.9 N of lift [J2]. | Heavier plugs and chassis. |
| Install time | 11 min task estimate (10 min), with the bar, logger and antenna assembled before going to site [K3]. R10 stays not verifiable at TRL 3. | Setting the bar takes about a minute longer than hooking a strap. |
| Drawing | LKL-DWG-001 Rev P4; making sketches LKL-DWG-101 to 109 added. | Follows the model. |
| Calculations | LKL-CAL-001 v0.3: mass, cost, resonance, flooding, cable reach and install time re-run; every other section is unchanged. | Follows the model. |

*Table 3. Proposed, then accepted by Amish as recommended on 2026-10-02.*

| # | Question | Options | Recommendation |
| --- | --- | --- | --- |
| A1 | R12 limits total mass to 1.0 kg; with the neck bar the set is 1.35 kg. | (a) restate R12 as 1.0 kg for the logger, cable and sensor (0.96 kg) and count the neck bar as site hardware; (b) relax R12 to 1.5 kg in all; (c) look for a lighter hanger (1 mm wall tube saves about 55 g; still not met). | (a): R12 was set for handling the logger, and the bar stays in the neck between visits. Accepted 2026-10-02; the logger set is weighed at TRL 4, since the margin is 0.04 kg. |
| A2 | The neck bar needs a neck of about 570 to 710 mm with two sound opposite walls. | (a) neck bar as modelled, with a longer inner tube for wider necks; (b) a bracket on two concrete screws in the neck wall, which needs the utility's consent to drill. | (a) for the prototype; confirm the neck sizes of the pilot district before any deployment. Accepted 2026-10-02; a longer inner tube is designed only if the pilot utility's neck sizes go past 710 mm, and the drilled bracket stays the fallback. |

## Consequences

- `design_state: constructable` in `project.yaml`. The build plan LKL-BLD-001 shows every component and step in pictures generated from the model (`cad/src/build_plan_media.py`).
- With A1 accepted, R12 is met on paper (0.96 kg for the logger, cable and sensor against 1.0 kg; LKL-REQ-001 v0.6, LKL-CAL-001 v0.4). Before it, the requirement status (LKL-CAL-001 v0.3) was: 1 not met (R12, mass, see A1), 4 at risk (R1, R3, R4, R7), 1 open (R2), 2 not verifiable at TRL 3 (R10, R13), 3 met on paper (R5, R6, R9), 3 met by design (R8, R11, R14), and R15 reported against the value-engineering target: USD 11 over it.
- The photoreal renders (`media/render-*.png`), `media/card.png`, `media/social-preview.png` and the appearance model `cad/src/product_model.py` still show the concept strap hanger, the fused plugs and the single top gland; they need updating on Amish's Mac, where Blender is. `cad/src/model.py` keeps the concept strap parameters only so `product_model.py` still runs.
- The pot magnet's stud length, the antenna's stud size, the SMA bulkhead's hole size and the M12 socket's thread are confirmed when parts are bought (LKL-DEC-001).

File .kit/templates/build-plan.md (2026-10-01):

---
doc_id: PRJ-BLD-001
title: Project prototype build plan
project: Project name
doc_type: Build plan
version: "0.1"
status: Draft
date: YYYY-MM-DD
author: Amish Chadha
license: CERN-OHL-S-2.0
revisions:
  - version: "0.1"
    date: YYYY-MM-DD
    author: Amish Chadha
    change: First build plan; design made constructable
---

# Project prototype build plan

**Plan, not yet built.** How to build the first proof-of-concept prototype, component by component. Building and testing to it is TRL 4 work. Decisions still to be made are kept in the design decisions register (`docs/06-design-decisions.md`), not here.

## 1. What you are building

Every component, pulled apart and numbered in build order

One short paragraph: what the prototype is, how many components, which are made and which are bought, and the main ways they are made.

## 2. What changed to make it buildable

| Component | The concept had | The buildable design has | Why |
| --- | --- | --- | --- |

## 3. Making the components

### 3.1 Component name

Making sketch

**What it is and what it is made from.**

**How to make it.**

1. Mark out ...
2. Cut ...

**How it fits the parts next to it.**

Close-up of the joint

**Check before moving on.**

## 4. Putting it together

### Step 1: ...

Step 1

## 5. First checks

| Check | Requirement | How | Pass when |
| --- | --- | --- | --- |

## 6. Safety stops

## 7. Tools, skills and workspace

## 8. Where the numbers come from

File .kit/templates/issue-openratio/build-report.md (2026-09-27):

---
name: Build report
about: Tell us what happened when you built, printed or tested part of this design
title: "Build report: "
labels: build-report
---

This is a research and educational prototype, not a medical device. It is a TRL 3 concept and is not released for fabrication. If you build any part of it, you do so at your own risk. Reports help everyone.

**What you built** (part, sub-assembly or test)

**Materials, tools and settings**

**What worked**

**What did not work, with photos or measurements if you have them**

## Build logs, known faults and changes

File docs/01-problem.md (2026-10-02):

---
doc_id: LKL-PRB-001
title: LeakListen problem statement
project: LeakListen
doc_type: Problem statement
version: "0.5"
status: Draft
date: '2026-10-02'
author: Amish Chadha
license: CERN-OHL-S-2.0
revisions:
- version: "0.1"
  date: '2026-09-25'
  author: Amish Chadha
  change: Initial scaffold
- version: "0.2"
  date: '2026-09-25'
  author: Amish Chadha
  change: Problem, users, context, constraints, prior work and open questions for TRL 2
- version: "0.3"
  date: '2026-09-25'
  author: Amish Chadha
  change: "TRL 3, reflect the TRL 2 review items adopted for TRL 3 (LKL-DDR-001) and the findings of LKL-CAL-001 in the constraints, prior work and open questions"
- version: "0.4"
  date: '2026-09-25'
  author: Amish Chadha
  change: "Recommendations accepted by Amish (DDR-002): open questions on plastic mains and cover loss updated; LKL-DDR-001 items now decided"
- version: "0.5"
  date: '2026-10-02'
  author: Amish Chadha
  change: "First partner question answered by Amish's 2026-10-02 decision (first candidate region: the UK)"
---

# LeakListen problem statement

A large share of treated city water is lost to leaks before it reaches customers, and most leaks that do not surface are found late, by slow manual listening surveys or not at all. Small and mid-sized utilities need a cheap way to listen to their network every night and point crews at the few places worth a closer look.

## The problem

Leaks cost water, energy and money in every network, and the losses are largest where utilities can least afford them.

- Globally, non-revenue water (water produced but not billed, because of physical leaks or commercial losses) is estimated at 126 billion m³ a year, worth nearly $40 billion ([World Bank](https://blogs.worldbank.org/en/ppps/what-do-private-companies-look-performance-based-non-revenue-water-project)).
- In developing countries, about 45 million m³ a day are lost through leakage in distribution networks, "enough to serve nearly 200 million people" ([Kingdom, Liemberger and Marin, World Bank, 2006](https://documents1.worldbank.org/curated/en/385761468330326484/pdf/394050Reducing1e0water0WSS81PUBLIC1.pdf)).
- Even in high-income networks the numbers are large: the United States still has about 240,000 water main breaks a year ([ASCE 2025 Report Card](https://infrastructurereportcard.org/cat-item/drinking-water-infrastructure/)), and water companies in England and Wales leaked an average of 2,967 million litres a day from April 2022 to March 2025 ([Discover Water](https://www.discoverwater.co.uk/leaking-pipes)).

Many leaks never reach the surface and can run for months because nobody hears them. Commercial acoustic noise loggers solve this, but a fleet of them plus the software subscription is beyond many small utilities, and the loggers are closed, so a utility cannot inspect, repair or adapt them.

## Users and context

| User | Need |
| --- | --- |
| Small and mid-sized water utility (network and leakage team) | A low-cost way to screen a district every night and send the leak crew to the right street |
| Leak detection technician | Loggers that are quick to place from the surface and give a clear "listen here" list for ground microphone or correlator follow-up |
| Utility manager or regulator | A simple trend of how many loggers flag a possible leak, to target repairs and show progress on losses |
| Community water scheme or campus facilities team | A few loggers on a private network (campus, industrial park, airport) without a specialist contract |
| Researchers and students | An open, documented logger and dataset for leak noise research |

**Operating context.** The logger sits in a valve chamber or surface valve box on a pressurized distribution main, typically DN80 to DN300 (3 to 12 in), cast iron, ductile iron, steel, asbestos cement or plastic. Chambers are dark, damp and may flood; the cover is often cast iron, which blocks radio. The sensor attaches by magnet to a valve spindle cap, hydrant or fitting, which carries pipe vibration well. Leaks are loudest relative to background at night, when demand and traffic are low, so the logger listens between about 02:00 and 04:00.

## Constraints

- Garage-buildable prototype, about $130 USD in parts per logger (`project.yaml`).
- No pipe work: nothing is cut, tapped or drilled on the utility's assets, and the logger must not change water quality.
- Installed and recovered from the surface with a pole or valve key; no confined space entry (see Safety).
- Runs on a primary battery for years; there is no power in a chamber and no sun for solar.
- Sends one small summary a night over LoRaWAN to any network server, including the lab's TwinKit gateway; raw vibration samples never leave the device (a fixed requirement, LKL-DDR-001 D6).
- Works only on pressurized pipes. Leaks on unpressurized or intermittent-supply pipes make little or no noise.
- Utility permission is needed before any logger is placed on a public network.

## Out of scope

- Pinpointing a leak to within a metre. LeakListen flags a likely leak near a logger; crews then pinpoint with a ground microphone or correlator. Correlation between loggers is an open question for a later phase.
- Transmission mains above DN600, sewer and gas networks.
- Customer-side leaks inside buildings.

## Prior work

- **Acoustic leak detection** is the standard method for hidden leaks. Research at the National Research Council of Canada characterized leak signals in plastic pipes and found that most of the energy measured by hydrophones was below 50 Hz and that plastic pipes attenuate leak noise strongly ([Hunaidi and Chu, *Applied Acoustics*, 1999](https://www.sciencedirect.com/science/article/pii/S0003682X99000134)). A low-cost sensor must therefore reach down to a few hertz and will hear less far on plastic pipes.
- **Commercial noise and correlating loggers** are proven. For example, Gutermann's ZONESCAN 820 loggers correlate automatically between all relevant logger pairs each day and report leak positions to better than 1 m ([Gutermann](https://en.gutermann-water.com/)). These are closed products; LeakListen aims at the simpler, cheaper noise-level screening task, with open hardware and data.
- **Performance-based non-revenue water programs** show that finding and fixing leaks pays back, which is why the World Bank promotes them ([World Bank](https://blogs.worldbank.org/en/ppps/what-do-private-companies-look-performance-based-non-revenue-water-project); [Kingdom et al., 2006](https://documents1.worldbank.org/curated/en/385761468330326484/pdf/394050Reducing1e0water0WSS81PUBLIC1.pdf)).
- **Lab siblings.** LeakListen reuses the STM32WL LoRaWAN core and payload conventions of FieldNode (not its solar power, which cannot work in a chamber), decided by Amish on 2026-09-25 (LKL-DDR-001 D4, LKL-DDR-002), and reports to the lab's TwinKit gateway, which already lists leak detection among its water supply uses.
- **Leak noise in plastic pipes.** Gao et al. modeled leak noise in buried plastic pipes as a fluid-dominated wave with a flat source spectrum and showed that the signals are low frequency and narrow band ([Gao, Brennan, Joseph, Muggleton and Hunaidi, *Journal of Sound and Vibration*, 2004](https://www.sciencedirect.com/science/article/pii/S0022460X03011647)). LKL-CAL-001 uses the same model form to estimate detection distance.

## Open questions

- [ ] Which pipe materials and diameters dominate the first partner utility's network? LKL-CAL-001 estimates about 185 m on iron but only a few metres on plastic for a contact sensor on a valve, so the answer sets how soon the hydrophone variant, which serves plastic mains under LKL-DDR-002, is needed.
- [ ] How much does a cast-iron cover attenuate LoRa in practice? LKL-CAL-001 assumes 20 dB, which limits the link to about 0.5 km. The response is decided (LKL-DDR-002): measure first, then a gateway within about 0.5 km of each such district by default, with a through-cover antenna where a utility agrees.
- [ ] What night-time background noise (pumps, pressure reducing valves, traffic, customer use) will cause false alarms?
- [ ] Will the partner utility allow magnets on valve spindle caps and hydrants, and who may place loggers?
- [x] Which partner first? Decided by Amish, 2026-10-02 (LKL-DDR-002, O1): a water utility with metallic mains, district metered areas and a leakage target it reports against; the first candidate region to approach is the UK, where water companies run district metered areas and report leakage to the regulator. Nothing is agreed.
- [ ] Is a nightly noise-level flag enough for the utility, or is correlation between loggers needed to be useful?

## Safety

> **Safety:** Valve chambers can be confined spaces with low oxygen or toxic gas; LeakListen is designed to be placed from the surface, and nobody should enter a chamber without the utility's confined space permit, gas testing and a trained standby person. Covers are heavy: use a proper lifting key and keep hands and feet clear. Work in the street needs traffic management under the local authority's rules. The logger uses a lithium thionyl chloride primary cell, which can vent or burn if shorted, crushed, heated or charged; never charge it. The pot magnet is strong: keep it away from pacemakers and pinch points.

## User research and co-design

This design is for communities the author is not part of, so requirements come from the people who will use it.

- [ ] Identify a local partner organization (Helpful Engineering network, NGO or university)
- [ ] Run co-design sessions with intended users; record who, where and what was learned
- [ ] Validate load, distance, terrain and cost assumptions in the field
- [ ] Revise requirements (REQ) from findings before freezing the design

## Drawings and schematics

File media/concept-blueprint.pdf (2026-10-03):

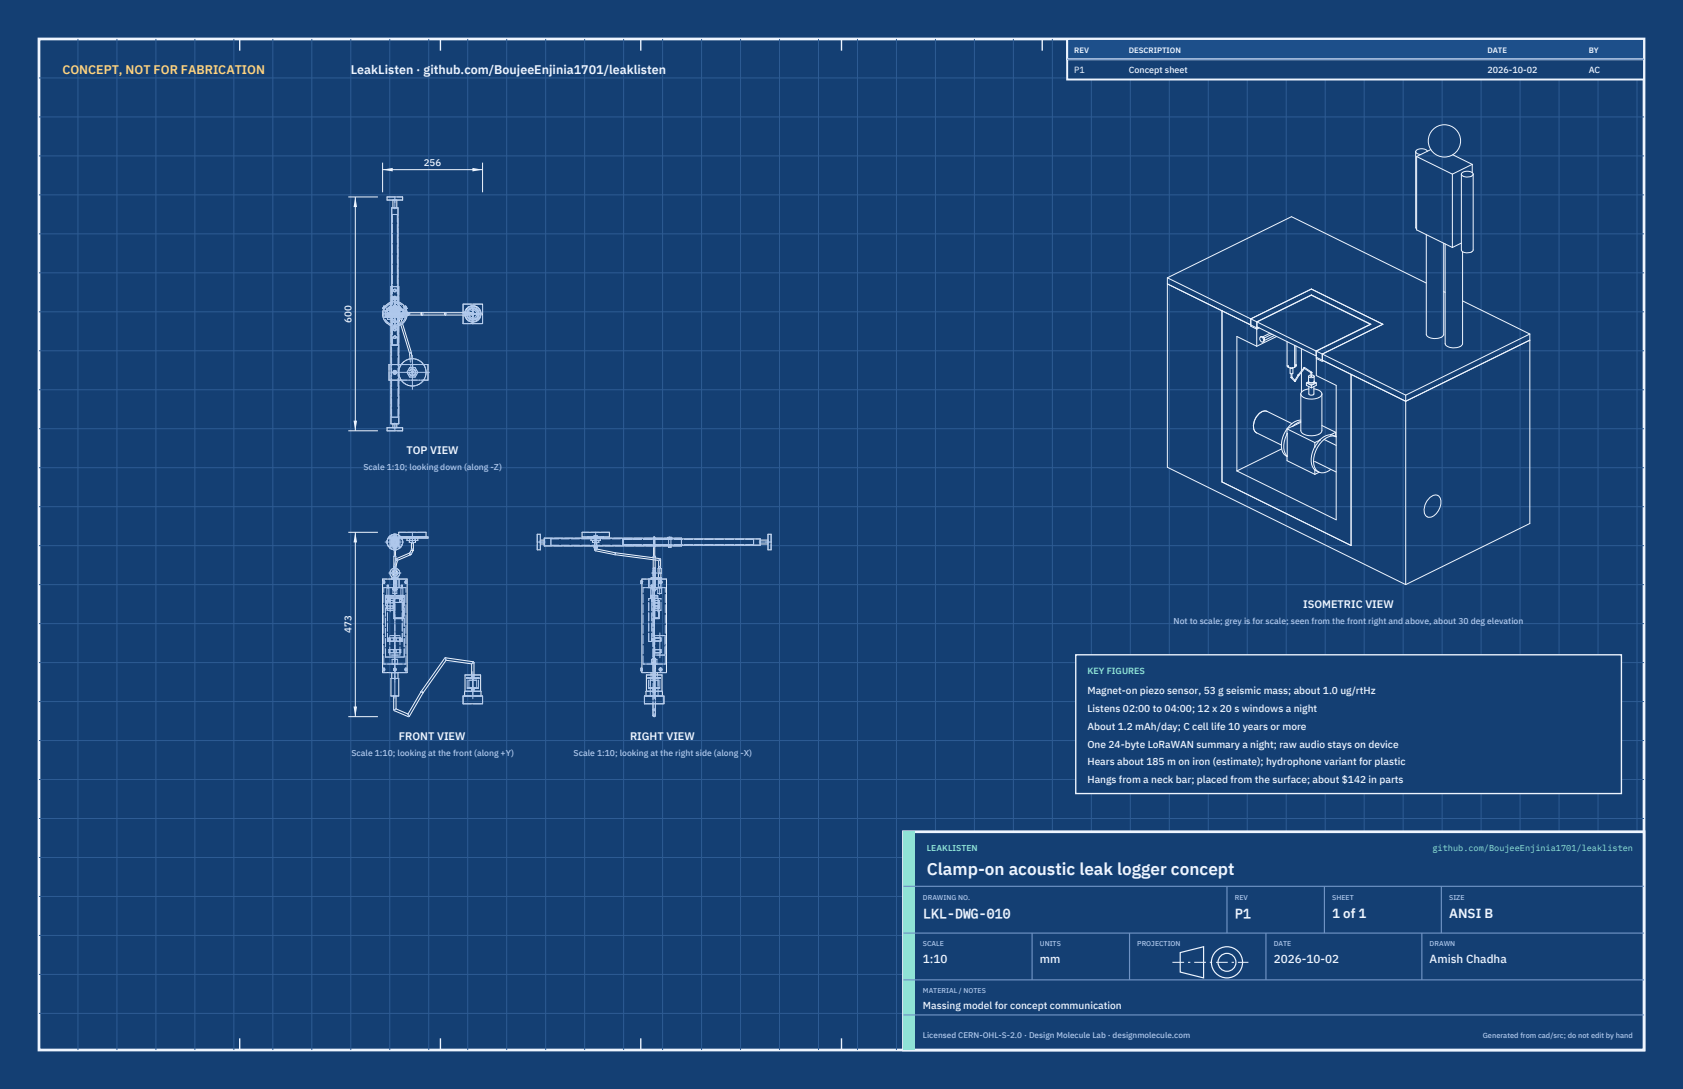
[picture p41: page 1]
CONCEPT, NOT FOR FABRICATION; LeakListen · github.com/BoujeeEnjinia1701/leaklisten; FRONT VIEW; TOP VIEW; RIGHT VIEW; ISOMETRIC VIEW; REV; DESCRIPTION; DATE; Concept sheet; LEAKLISTEN; github.com/BoujeeEnjinia1701/leaklisten; DRAWING NO. LKL-DWG-010; REV P1; SHEET 1 of 1; SIZE ANSI B; SCALE 1:10; UNITS mm; PROJECTION; DRAWN Amish Chadha; Licensed CERN-OHL-S-2.0 · Design Molecule Lab · designmolecule.com; Generated from cad/src; do not edit by hand

Scale 1:10; looking down (along -Z)

Not to scale; grey is for scale; seen from the front right and above, about 30 deg elevation

KEY FIGURES
Magnet-on piezo sensor, 53 g seismic mass; about 1.0 ug/rtHz
Listens 02:00 to 04:00; 12 x 20 s windows a night
About 1.2 mAh/day; C cell life 10 years or more
One 24-byte LoRaWAN summary a night; raw audio stays on device
Hears about 185 m on iron (estimate); hydrophone variant for plastic
Hangs from a neck bar; placed from the surface; about $142 in parts

Scale 1:10; looking at the front (along +Y)

Scale 1:10; looking at the right side (along -X)

Clamp-on acoustic leak logger concept

MATERIAL / NOTES
Massing model for concept communication

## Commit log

2026-09-25 Initial scaffold: standard open hardware layout, CERN-OHL-S v2 + MIT licenses
    Claude-Session: https://claude.ai/code/session_01XuhhSU4W6fYhgCfURbrkut
    [bom.csv]
2026-09-26 Populate to TRL 2: problem, requirements, precis, concept media, BOM and README use cases
    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
    [bom.csv]
2026-09-26 Advance to TRL 3: DDR-001, CAL-001 sizing, parametric model with STEP/STL, GA drawing, priced BOM; TRL 4 on hold
    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
    [bom.csv, leaklisten-assembly.step, leaklisten-assembly.stl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]
2026-09-26 Accept all recommendations (DDR-002), switch footer to designmolecule.com, add README write-up with new inspiration point
    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
    [bom.csv, leaklisten-assembly.step, leaklisten-assembly.stl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]
2026-09-27 Product appearance model and photoreal renders
    Adds cad/src/product_model.py (appearance model for renders only, all main
    dimensions from model.py) and Blender renders in media/render-*.png,
    captioned with the project, repository and viewing direction. README leads
    with the product render; trl stays 3.
    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
2026-10-01 Image quality pass: legible exploded views, flow diagrams and drawing sheets
    Kit 1.6.1 image layout: the parts list sits in its own column, number bubbles sit on visible parts and never overlap, small parts get a leader, pictures are cropped to the subject, flow labels keep numbers with their units, and sheet captions and the revision table no longer overprint. Concept images, blueprint and general arrangement sheet regenerated; repo-specific labels moved clear of other text and lines.
2026-10-01 Kit 1.7.0: constructable design, illustrated build plan and design decisions register
    The design is now constructable: every part can be made and fits its neighbours, with each change recorded in a Design for construction decision record (made under Amish's 2026-09-30 instruction; ope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
    FlexHand also credits Dr. Geeti Chadha as a contribut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
    [bom.csv, leaklisten-assembly.step, leaklisten-assembly.stl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]
2026-10-02 Record Amish's approval of the open-decision recommendations
    Amish approved the recommendation on every open decision in the design decisions register ("i approve your recommendations for all 555 open decisions.", 2026-10-02). Each decision is moved to Decisio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
2026-10-03 Carry approved follow-ups into the design and redo photoreal renders
    Amish approved the follow-up actions from the open-decision sign-off ("APPROVED CHANGES, COMPLETE THESE", 2026-10-02), the design-for-construction change tables in ten repos, the last wave's open dec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
    [bom.csv, leaklisten-assembly.step, leaklisten-assembly.stl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]
2026-11-05 Kit 1.9.1 upgrade: pipeline documents and detailed CAD for every option
    STEM check with fixes under the standing instruction and an independent
    review, concept options scored against the user requirements, URS, PRS,
    RTM, REG, FEA, RSK, MKT, PLN and DDR, every option modelled at D3 with
    cad/fidelity.json passing, and the concept options picture rendered with
    Blender Cycles on Amish's Mac. Concept choices stay proposed, awaiting
    Amish.
    Claude-Session: https://claude.ai/code/session_01LppsZSzPTJWTBAV5wh1Goq

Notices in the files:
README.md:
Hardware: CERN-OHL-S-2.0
